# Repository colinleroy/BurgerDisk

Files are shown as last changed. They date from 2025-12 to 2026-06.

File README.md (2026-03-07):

# BurgerDisk - a daisy-chainable Smartport hard drive

**Warning - everything in git, and not a release, is not necessarily fully tested.**

This device provides the Smartport-capable Apple II with an SD-card-based
hard-drive, like the SmartportSD, SPIISD or FloppyEmu projects do.

Contrary to those, the BurgerDisk firmware handles a daisy-chain port
and allows you to have more Smartport devices and/or dumb floppy drives
connected behind it.

Contrary to the SPIISD v2 and FloppyEmu projects, BurgerDisk is free software and
free hardware, and licensed in a way to keep it that way.

Contrary to the SPIISD v2 and FloppyEmu projects, BurgerDisk has no screen UI,
and contrary to the SPIISD v1 project, it has no "boot partition" selection
button. The Apple II will be able to boot from the first partition when booting
from slot 5. This is both a choice - I wanted this device to resemble a
period-correct hard drive - and a limitation - there are no extra digital GPIOs
available on the Nano board.

The code of this firmware is based on:
- Apple //c Smartport Compact Flash adapter, written by Robert Justice <rjustice(at)internode.on.net>
- Ported to Arduino UNO with SD Card adapter, written by Andrea Ottaviani <andrea.ottaviani.69(at)gmail.com>
- FAT filesystem support, written by Katherine Stark
- Daisy chaining is based on SmartportVHD's reverse engineering, written by Cedric Peltier

## Building the BurgerDisk
Full instructions for building your own BurgerDisk are available in the
[BurgerDisk build instruction page](build_instructions/README.md).

## Using the BurgerDisk
### Plugging in
Plug the BurgerDisk to your Apple II, or to the previous Smartport device in the
chain. Plug the next device to the daisy port of the BurgerDisk.

When daisy-chaining, the usual Apple II rules apply:
- first the dumb 3.5" floppy disk drives (like the Apple 3.5 drive)
- followed by Smartport devices (like BurgerDisk, Unidisk 3.5", Fujinet, SPIISD, etc)
- followed by dumb disk drives (like the Disk //c)

So far, BurgerDisk has been tested in the following configurations:
- Alone on the //c and IIgs external floppy connector
- computer => BurgerDisk => Disk //c
- computer => Unidisk 3.5 => BurgerDisk
- computer => Unidisk 3.5 => BurgerDisk => Disk //c
- computer => BurgerDisk => Unidisk 3.5 => Disk //c

It has been tested with the following computers:
- Apple //c A2S4000, ROM3
- Apple //c A2S4100, ROM4x
- Apple IIgs, ROM 01

[More tests results are available](https://www.colino.net/wordpress/archives/2026/02/08/burgerdisk-tests/).

### Configuring disk images
The firmware will open and present between one and four partitions.
If a config.txt file exists on the SD card, it will use the first four
lines as filenames for the partitions to open. An optional fifth line
containing "debug=1" will turn debug messages on.

For example, this will present `prodos.po` and `total_replay.po`, and turn
debug on:
```
prodos.po
total_replay.po

debug=1
```

If no config.txt file exists, the firmware will search for PARTx.po
files, with x between 1 and 4.

## Compatibility notes
The firmware is compatible with SPIISD v1 and SPIISD v2 boards. It fixes
two bugs in their firmwares:
- Too slow init preventing the partitions to be visible by ProDOS after booting
  from internal floppy,
- A non-recoverable freeze on A2S4100 Apple //c with the memory expansion board.

But,
- Of course, running this firmware on an SPIISD board will not allow for daisy chaining.
- For daisy-chaining, the BurgerDisk firmware makes use of pins that the SPIISD
  boards use for button(s) and/or LCD. If you want to replace the SPIISD firmware
  with BurgerDisk's, it is safer to unsolder the buttons and remove the LCD. The
  BurgerDisk firmware does not handle any buttons or LCD anyway.

## Licensing
This firmware is licensed under the GPL v3.

The PCBs and enclosure are licensed under CC BY-SA 4.0.

This means that anyone is welcome to **use, modify, distribute and sell hardware**
based on BurgerDisk. Using and modifying does not require you to do anything.
**Distributing and/or selling requires you to provide the source files for the
firmware and the PCBs, under the same licenses**. It can just be a link to this
repository if no modification is made. If modifications are made, think free
software, and consider submitting pull requests, it could help avoiding
fragmentation.

## Thanks and acknowledgments

Many thanks to Robert Justice, Katherine Stark and Andrea Ottaviani for the
initial work on a simple SD-based Smartport device.

Many thanks to Cedric Peltier for his work on SmartportVHD, which does support
daisy-chaining, but is sadly abandoned, and based on a weird-ass development
board. It was very well documented and helped me a lot implementing daisy-chaining.

Many thanks to Ralph Irving, who spent many hours beta-testing and pinpointing
bugs I could not have fixed without his help (for lack of hardware).

Thanks also to Steve Chamberlin of [BMOW](https://www.bigmessowires.com/), for
documenting a lot of their Smartport/FloppyEmu work on their blog.

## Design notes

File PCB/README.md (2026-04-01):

In this directory are the Kicad sources for the different PCBs.
Variations exist:
- *-Angled: For a right-angle, PCB-type DB19F connector (otherwise, panel-mount (solder cups) connector required)
- *-THT: Through-hold PCB. Will require an Arduino and SD module
- *-SMD: SMD PCB with the Atmega328p integrated, and the microSD where applicable

PCBs families:
- BurgerDisk: The simpler PCB, with more enclosures options (Full or micro SD)
- Mini: Everything integrated, for the Mini enclosure
- Domino: Everything integrated, as small as possible.
- (micro)SD-module: the card readers for the BurgerDisk

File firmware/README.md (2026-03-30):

# Programming the Arduino Nano with BurgerDisk's firmware

In order for the Arduino Nano to boot fast enough to answer an Apple //c booting
from its internal floppy, the Nano **has** to be programmed using an AVR ISP
programmer. I use an [STK500 AVR ISP programmer](https://aliexpress.com/item/1005006205386137.html).

Open a terminal, and change to this `firmware/` directory.

## Arduino IDE installation
Install the Arduino IDE, for example on a Debian-based Linux distribution:
```
sudo apt install arduino
```

Start it:
```
arduino .
```

## Arduino IDE configuration
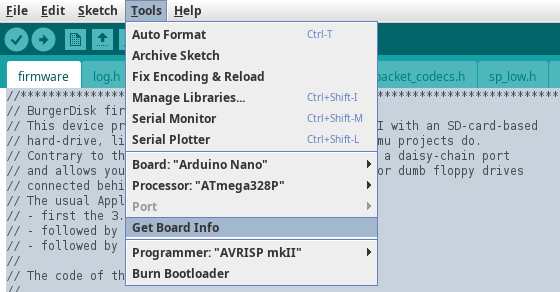
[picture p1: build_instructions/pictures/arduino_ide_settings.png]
The Arduino IDE Tools menu
.

In `Tools` menu, `Programmer` submenu, select your programmer.

You can then either continue using the Arduino IDE interactively:
- In `Tools` menu, `Board` submenu, select `Arduino Nano`.
- In `Tools` menu, `Processor` submenu, select `Atmega328p`.
- In `Sketch` menu, `Include Library` submenu, select `Manage Libraries...`.
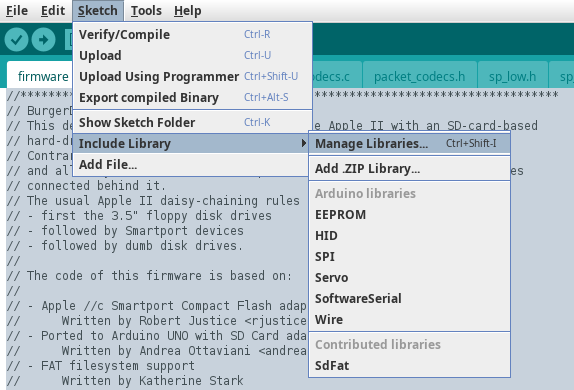
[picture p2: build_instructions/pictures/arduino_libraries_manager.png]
Manage Libraries menu item
  .
- Search for `SdFat` by Bill Greiman, scroll to it, and install version 2.3.0 (Screenshot shows 2.1.2, but choose 2.3.0).
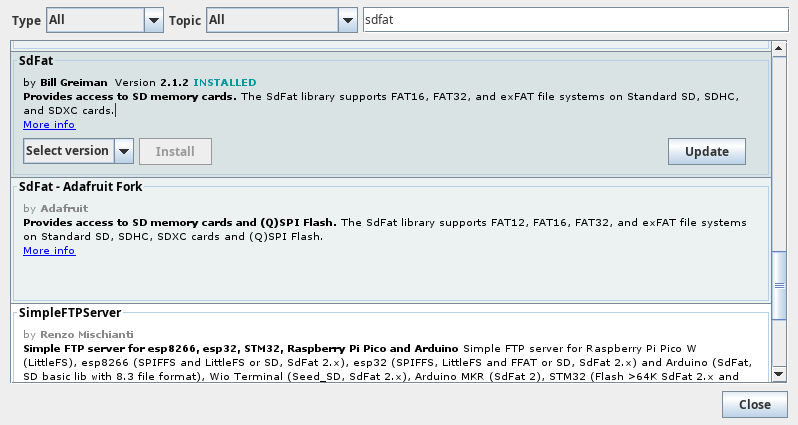
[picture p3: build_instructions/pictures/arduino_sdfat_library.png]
SdFat installation
  

Or, you can quit the Arduino IDE, and in your terminal, run:
```
make setup
```

## Flashing the firmware
**Make sure that the Nano is out of the BurgerDisk PCB, or that the BurgerDisk
is disconnected from the Apple II, even if the Apple II is turned off, before connecting the programmer. NEVER connect the programmer when the BurgerDisk is
connected to the Apple II.**

Connect your Arduino Nano to the programmer's 6-pin connector. The red
wire of the connector must be towards the Nano's `VIN` pin.
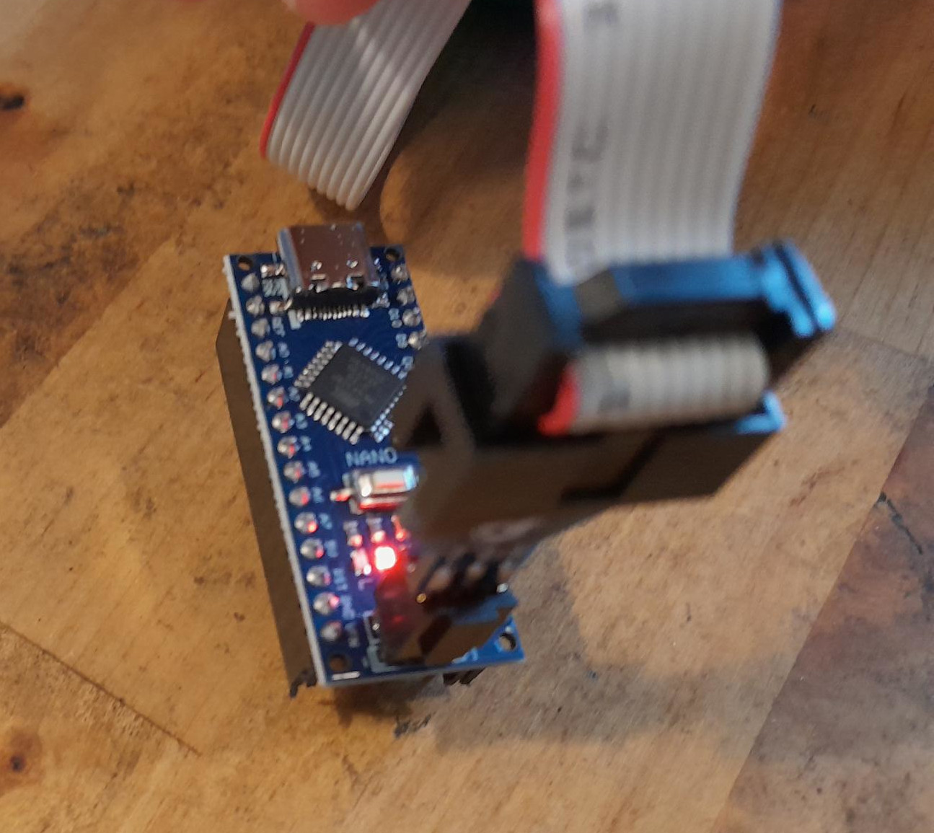
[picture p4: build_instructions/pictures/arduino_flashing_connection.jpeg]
The Arduino Nano, connected to the programmer


Two options here too:
- From the Arduino IDE, `Sketch` menu, choose `Upload using programmer`. Wait
  until the "Done uploading" message.
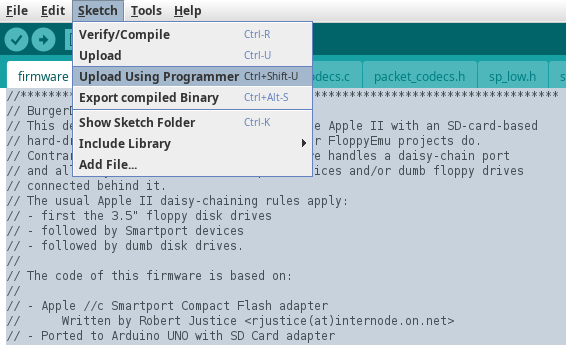
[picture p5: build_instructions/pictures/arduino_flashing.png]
Upload using programmer menu item
  
- From the command line, run `make fuse && make upload`. Wait for the upload to be done.

Disconnect the programmer, and you're set.

## Debugging
If you need to debug the firmware, you can connect its UART pins to an [UART/USB
converter](https://aliexpress.com/item/1005008293602159.html). Wire the
BurgerDisk's UART `GND` pin to the USB converter `GND` pin, and the BurgerDisk's
UART `TX` pin to the USB converter's `RX` pin.

Plug the USB converter in your computer, check its device file (using `dmesg`
for example), then run:
```
minicom -D /dev/ttyUSB0 -8 -b230400
```

Connect the BurgerDisk to the Apple II, and boot the Apple II. Log messages
should be visible in Minicom. Remember: **never have the programmer connected
while the PCB is connected to an Apple II!**

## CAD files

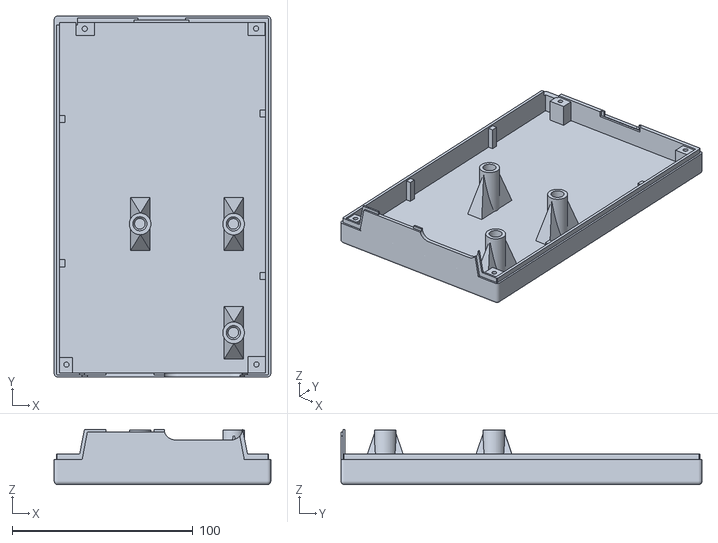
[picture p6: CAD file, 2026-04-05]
enclosure/Full-Size/BurgerDisk SMD Top (full size SD).stl
120.0 x 200.0 x 30.7

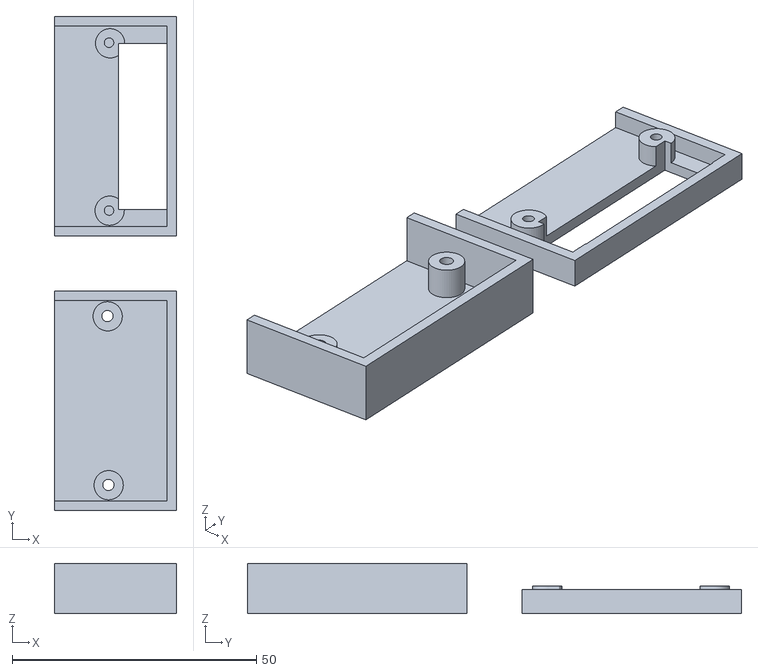
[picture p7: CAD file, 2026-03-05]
enclosure/Adapter/DB19-to-IDC20 adapter.stl
25.0 x 101.2 x 10.2

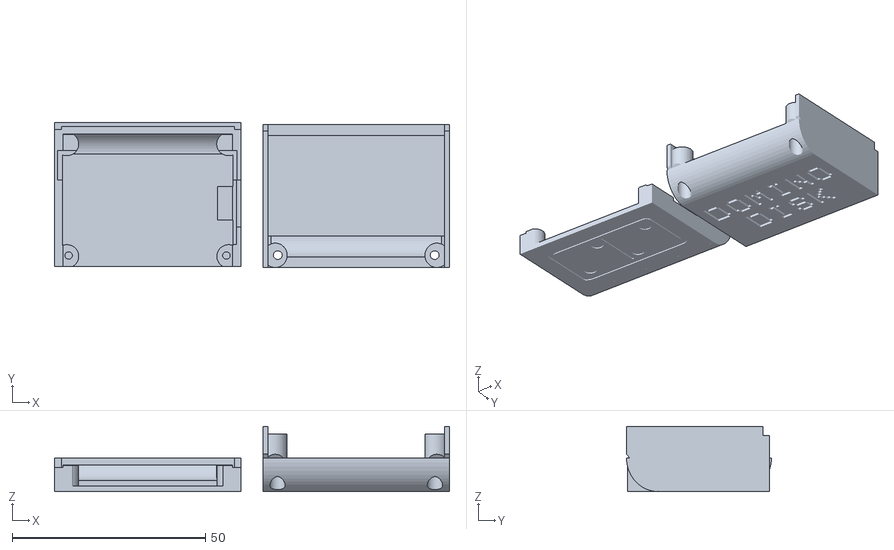
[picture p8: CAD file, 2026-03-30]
enclosure/Domino/DominoDisk SMD Angled.stl
102.1 x 37.5 x 16.9

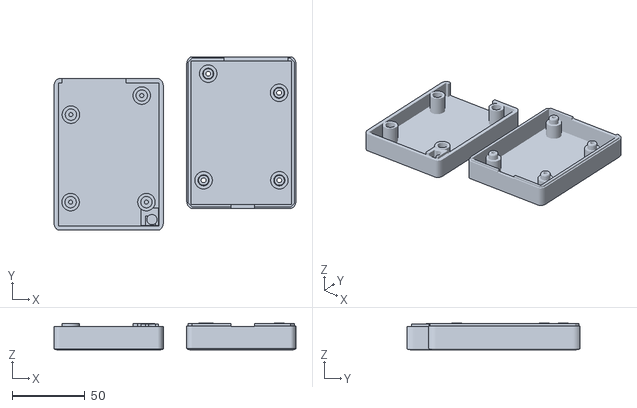
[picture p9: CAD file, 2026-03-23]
enclosure/Mini/Mini-BurgerDisk.stl
166.0 x 119.0 x 18.5

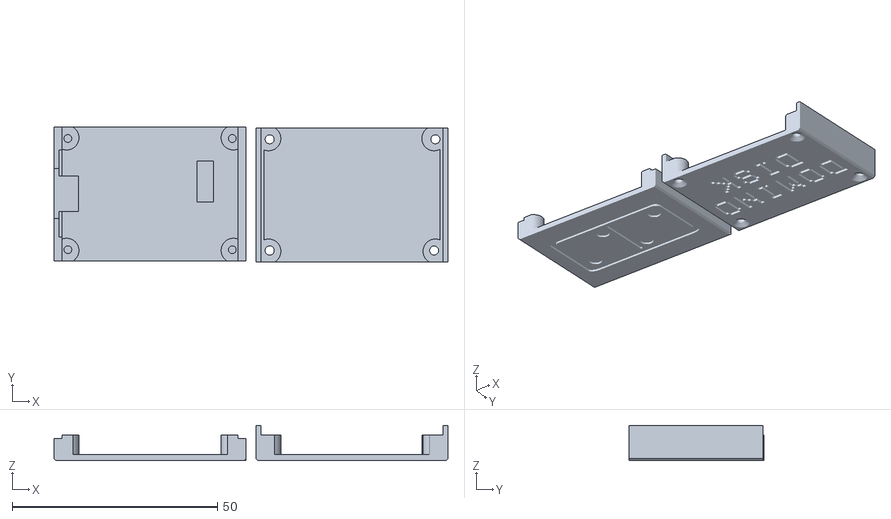
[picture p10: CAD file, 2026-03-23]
enclosure/Domino/DominoDisk SMD.stl
96.0 x 32.9 x 8.60

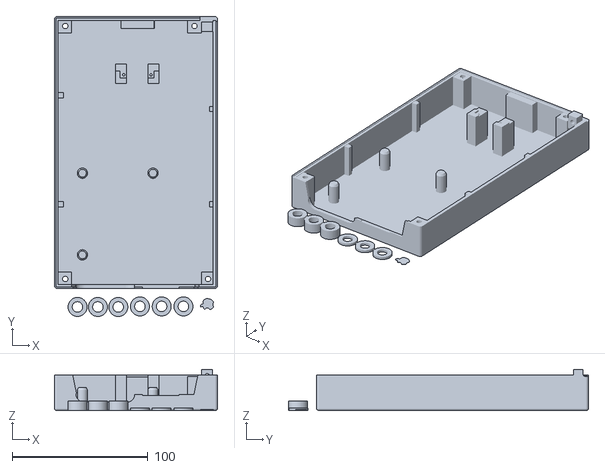
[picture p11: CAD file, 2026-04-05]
enclosure/Full-Size/BurgerDisk SMD bottom.stl
120.0 x 220.6 x 30.2

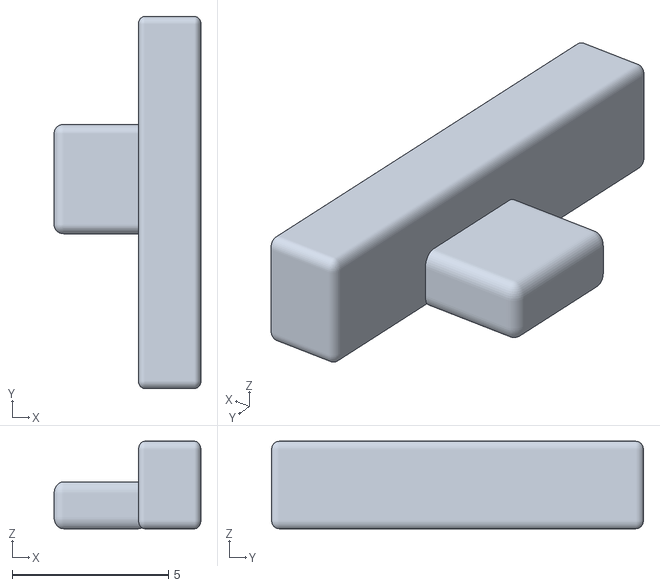
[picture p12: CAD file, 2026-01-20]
enclosure/Full-Size/BurgerDisk LED diffuser.stl
4.70 x 11.9 x 2.80

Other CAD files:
enclosure/Full-Size/BurgerDisk SMD top (micro-SD).stl

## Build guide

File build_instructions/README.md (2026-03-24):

# Building the BurgerDisk

## BOM (bill of materials)
Mind that the links provided here might be dead by the time you read this, and
that most of them have options (number of pins, resistor values, etc) that you
should double-check before buying.

**For the main board**, you will need:
- one female DB19 connector, [solder type](https://www.ebay.com/itm/165875193091) or
  [angled](https://www.ebay.com/itm/284338436979), for daisy-chaining
- the main PCB's [Gerber files](../../../releases/latest/). You can get them easily
  from PCBWay: [for solder type DB19](https://www.pcbway.com/project/shareproject/BurgerDisk_Apple_II_Smartport_hard_drive_235e6080.html), 
  or [for angled DB19](https://www.pcbway.com/project/shareproject/BurgerDisk_Apple_II_Smartport_hard_drive_Angled_THT_DB19_d37bdb0f.html)
- one [Arduino Nano with an Atmega328p processor](https://aliexpress.com/item/1005006773519913.html)
- one [STK500 AVR ISP programmer](https://aliexpress.com/item/1005006205386137.html) for uploading the firmware to the Arduino
- one [IDC20 connector, male, 2.54mm pitch](https://aliexpress.com/item/1005001400147026.html)
- one [470Ω resistor, 1/2W](https://aliexpress.com/item/1005004472952572.html)
- one [150Ω resistor, 1/4W](https://aliexpress.com/item/32952657927.html)
- one [330Ω resistor, 1/4W](https://aliexpress.com/item/32952657927.html)
- one [1kΩ resistor, 1/4W](https://aliexpress.com/item/32952657927.html)
- one [10kΩ resistor, 1/4W](https://aliexpress.com/item/32952657927.html)
- one [3mm LED, 3V, 20mA](https://fr.aliexpress.com/item/1005003320296052.html)
- one [PC817 optocoupler (DIP-4)](https://aliexpress.com/item/1005004609787594.html)
- one [1N5818 diode](https://aliexpress.com/item/4000055728807.html)
- one [1N4448 diode](https://aliexpress.com/item/1005008591345474.html)
- two [2-pin male headers, 2.54mm pitch](https://aliexpress.com/item/1005006181780843.html)
- one [microSD module ("TF")](https://aliexpress.com/item/1005008633757049.html) or for a better manipulation of the card,
  [my version](../../../releases/latest/)
- one [6-pin male header, 2.54mm pitch](https://aliexpress.com/item/1005006181780843.html) for the MicroSD module
- one [6-pin cable, 2.54mm pitch, 10cm long](https://aliexpress.com/item/4001119232749.html) for the MicroSD module
- one [2-pin cable, 2.54mm pitch, 20cm long](https://aliexpress.com/item/4001119232749.html) for the LED
- two [15-pin female header](https://aliexpress.com/item/1005006934014275.html) for easy Arduino removal

**For connecting to the computer**, you will need:
- The BurgerDisk connection cable, composed of:
  - the [DB19 to IDC20 PCB](https://www.pcbway.com/project/shareproject/BurgerDisk_DB19_to_IDC20_adapter_d6ce25bb.html)
    or its [Gerber files](../../../releases/latest)
  - an [IDC20 cable, 2.54mm pitch](https://aliexpress.com/item/1005003853804182.html), at least 50cm
  - a second [IDC20 connector, male, 2.54mm pitch](https://aliexpress.com/item/1005001400147026.html)
  - one [male DB19 connector](https://www.ebay.com/itm/257181325655)
  - two [M2 x 12 or 14mm screws](https://aliexpress.com/item/1005006960903249.html)
- Alternatively, the [Fujinet's DB19/IDC20 adapter](https://github.com/FujiNetWIFI/fujinet-hardware/tree/master/AppleII/DB-19M-Adapter-Male-Rev1)
can be used, provided that you solder [the -12V and +12V pads between the IDC20
and the DB19, and the DRV2 pad on the side](../build_instructions/pictures/fujinet-db19-adapter.png)

**For the enclosure**, you will need:
- the [enclosure's STL files](../enclosure/)
- four [M3 x 20mm wood screws](https://aliexpress.com/item/33043885403.html)
- two [M2 x 6 to 10mm screws](https://aliexpress.com/item/33043885403.html)
- optionally, a [500 grams weight](https://aliexpress.com/item/1005007419997918.html)
  (and glue) to make the enclosure heavier and avoid thick-cables-induced levitation.
  (I found diving belt weights to have the best price-to-weight ratio but you can
  use whatever you want or have available).

## Printing the enclosure
You can use the .stl files provided in [this repository](../enclosure/).
So far I print the enclosure at 15% infill, 0.20mm layer height. With my printer
I don't need support for the overhangs on the slots at the back, but your mileage
may vary.

## Video format

These instructions are also [available in video format](https://www.youtube.com/watch?v=1XYskDaTvEE).

## Building the main PCB
**All elements are to be soldered on the top-side of the PCB**, the side with the
markings.

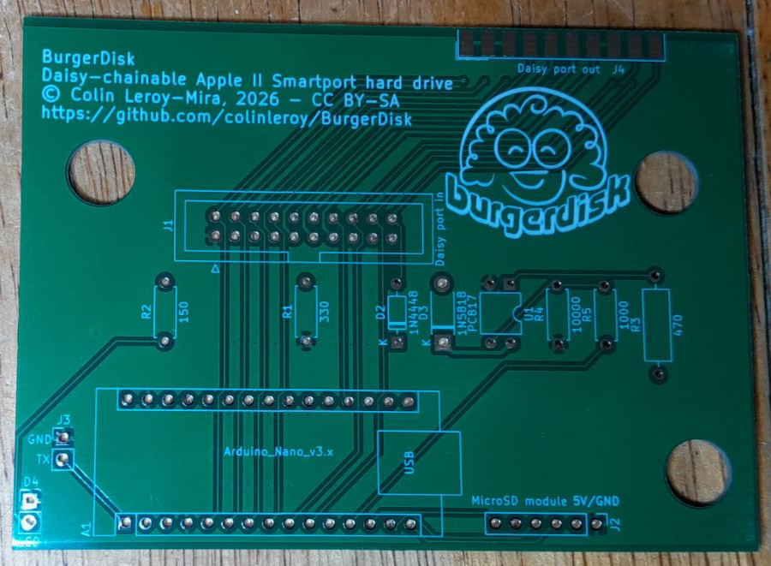
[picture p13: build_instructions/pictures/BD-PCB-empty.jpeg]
The empty PCB


### Small components: Resistors, diodes and optocoupler
Insert the 150Ω resistor in its spot, (R2/150).

Insert the 330Ω resistor in its spot (R1/330).

Insert the 470Ω resistor in its spot (R3/470).

Insert the 10kΩ resistor in its spot (R4/10000).

Insert the 1kΩ resistor in its spot (R5/1000).

Resistors are not polarized, so you can put them either way.

Insert the 1N4448 diode in its spot (D2 / 1N4448).

Mind that diodes **are** polarized, so make sure the line on the PCB silkscreen
and the line on the diode are facing the same way.

Insert the 1N5818 diode in its spot, (D3/1N5818).

Insert the PC817 optocoupler in its spot (U1/PC817). The small round
mark on the PC817 is the anode, and goes to the hole with a square solder mask.

Make these components stay in place, either by bending their legs or taping them.

Solder them.

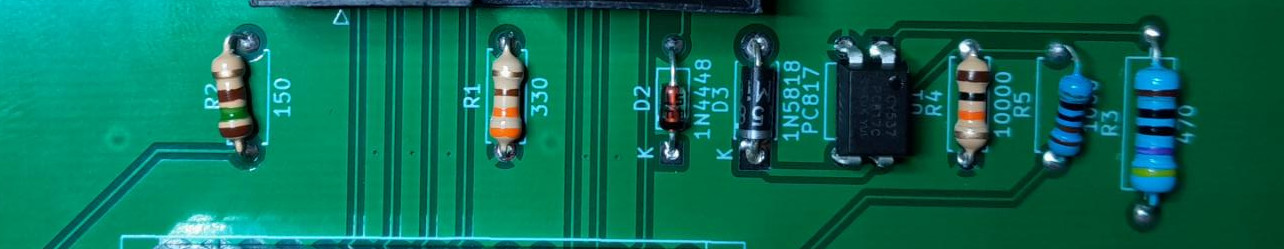
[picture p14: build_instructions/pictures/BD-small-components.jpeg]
Small components soldered


### MicroSD card module connector
Solder the 6-pin male header on the "MicroSD module" spot.

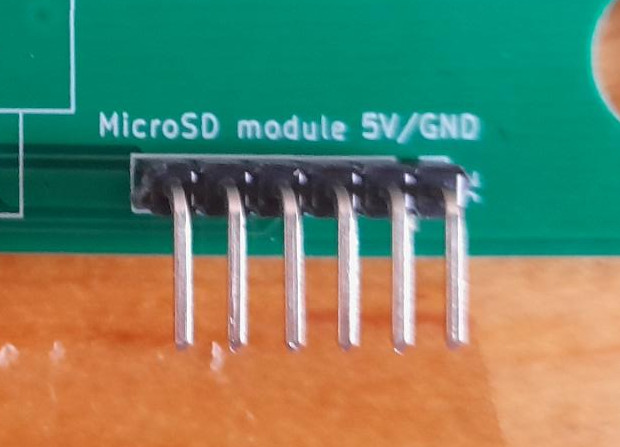
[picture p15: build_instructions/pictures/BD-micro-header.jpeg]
The MicroSD header


### 2-pin headers
Insert the 2-pin male headers in the "J3" and "LED" spots. Solder them.

### Input IDC-20 connector
Insert the IDC-20 connector in its spot. Mind the notch position, it must be
towards the bottom of the PCB. Solder it.

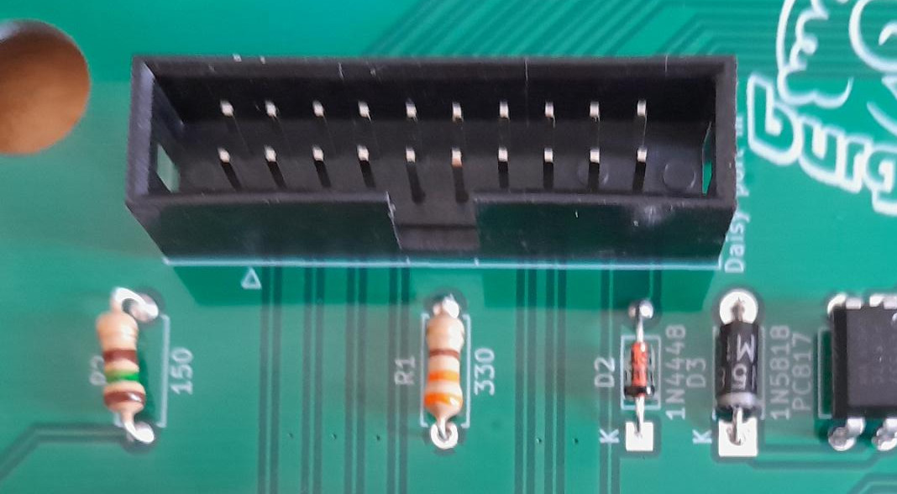
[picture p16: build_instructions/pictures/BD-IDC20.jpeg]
The IDC20 connector


### Arduino Nano
Solder the Nano's 6-pin header for programming on top of the Nano if necessary.
The top of the Nano is the side with the USB connector and the reset button.

This is not strictly necessary, but I like to put the Nano on a "socket" so that
it is easy to replace if necessary.

Assemble the Nano's two 15-pin connector with the 15-pin female connectors.
Insert these on the PCB, in the "NANO" spot, with the female headers towards
the PCB. Make sure the USB port is facing right, over the "USB conn" marking
on the PCB. Solder the 30 pins to the Nano.

Reverse the PCB, and solder the female headers' 30 pins to the PCB.

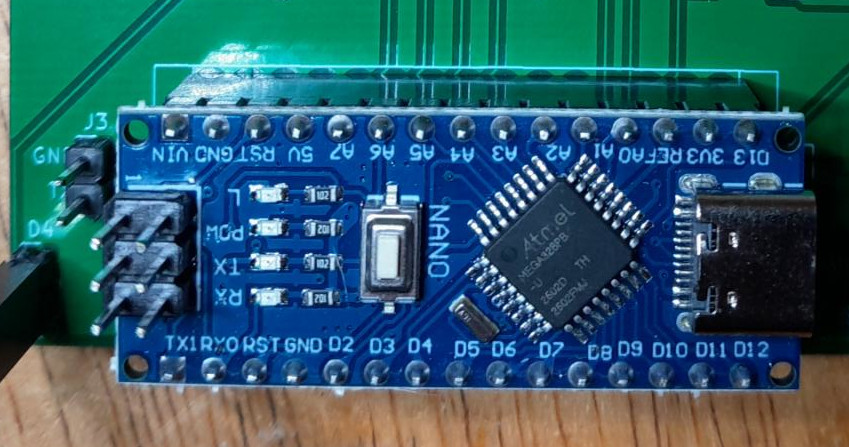
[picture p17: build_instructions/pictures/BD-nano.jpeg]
The Nano on its headers


You can [program the Arduino at this point](../firmware/README.md). People having
bought a kit from me don't need to program the Arduino, I did it before shipping.

Add a strip of black tape on the Nano's red LEDs, otherwise it will glow red
through white enclosures.

### Daisy DB19
Align the female DB19 connector with the Daisy out pads on the PCB. Pay close
attention to the alignment, as the DB19 will basically be un-desolderable with
basic equipment. Solder it on both sides.

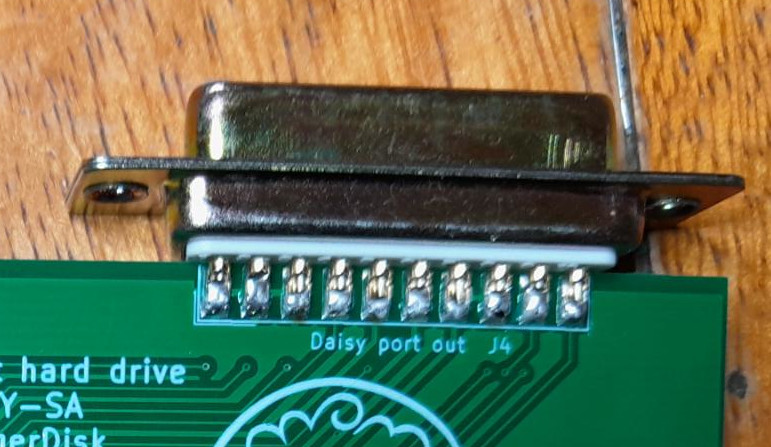
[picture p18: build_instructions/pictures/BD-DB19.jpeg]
DB-19 soldered


Your PCB now looks like this:
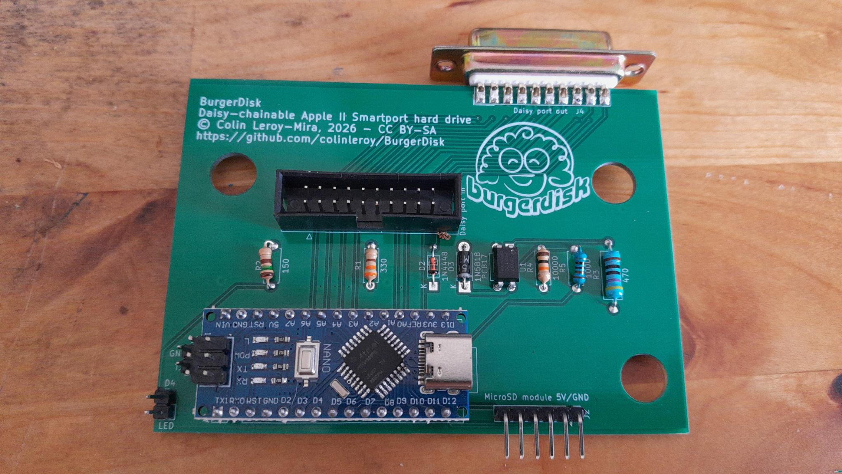
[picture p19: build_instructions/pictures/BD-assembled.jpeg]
The assembled PCB


### LED
Solder the LED to about 15 cm of Dupont wire connectors. The easiest way is to use
male/female connectors, shorten the LED's legs, and solder the LED to the male
connectors, minding the polarity (long leg = anode, red wire).

Put 3mm heatshrink on the LED to avoid having it illuminate the whole enclosure.

The anode (red wire) goes to the edge of the PCB.

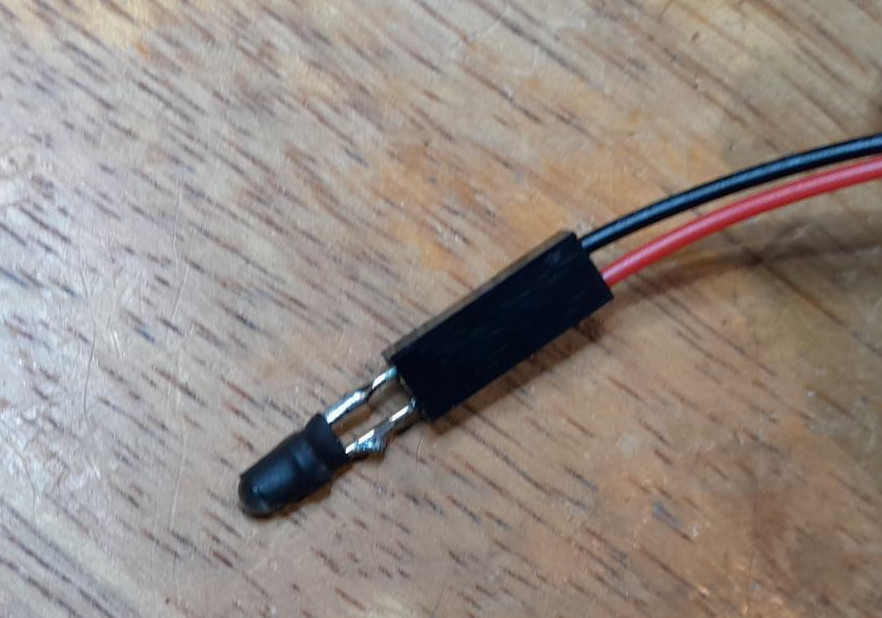
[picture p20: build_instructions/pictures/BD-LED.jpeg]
The LED


## The main connection cable
Because of its daisy-chaining capabilities, the cable to plug BurgerDisk to the
Apple II is more complicated than most DB19-to-IDC20 adapters.

The correct DB19-to-IDC20 adapter for this project is provided in this
repository.

### Assembling the adapter-based cable
Align the male DB19 connector with the pads on the adapter PCB. Pay attention
to the alignment, as the DB19 connector will basically be un-desolderable.
Solder it.

Insert the IDC-20 connector in the adapter PCB. It must on the top-side of the
PCB, where the IDC-20 is outlined on the silkscreen. Pay attention to the notch
position, which should be towards the DB19 connector. Solder it.

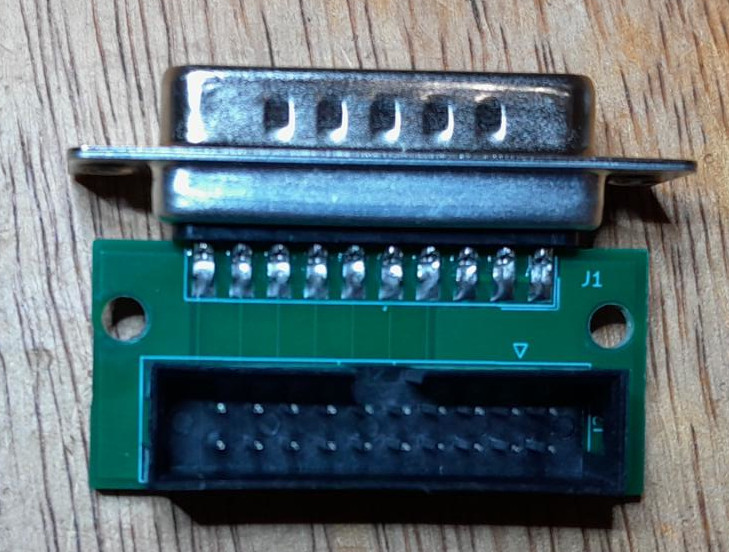
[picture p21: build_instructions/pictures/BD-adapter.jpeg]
The adapter, soldered


Insert the assembled adapter into its enclosure, and screw it shut with two M2
x 12 (or 14) mm screws.

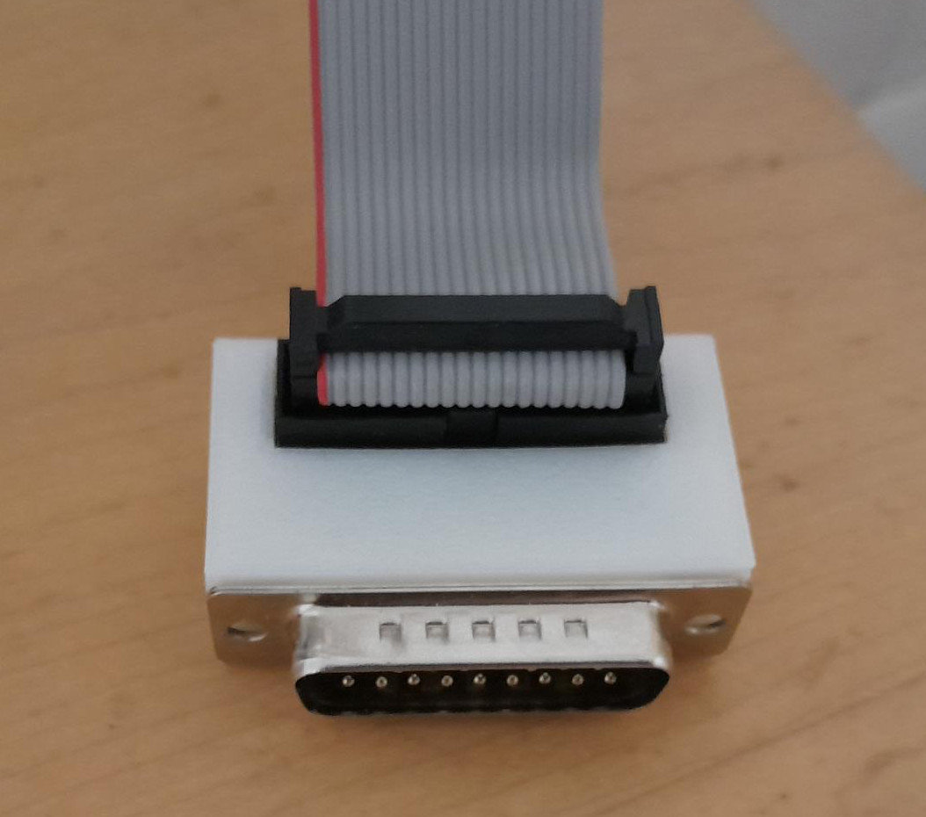
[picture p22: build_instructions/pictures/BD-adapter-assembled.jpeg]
The adapter, assembled


## Assembling in the enclosure
Put washers on the enclosure mounting posts: 2mm if you are using the angled
DB19 female connector, or 9mm (2 + 7) if you're using the "solder type" DB19
connector.

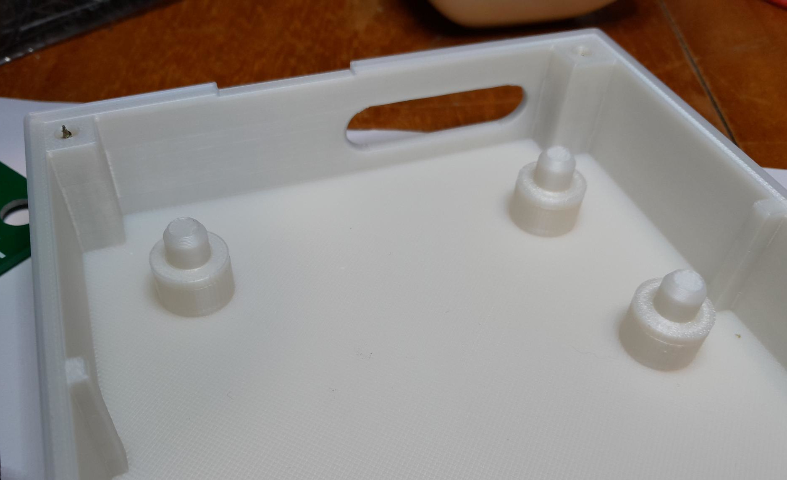
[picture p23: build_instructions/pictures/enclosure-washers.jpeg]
The washers


Put the PCB in the enclosure's bottom, making sure the enclosure notches
are in the PCB mounting holes.

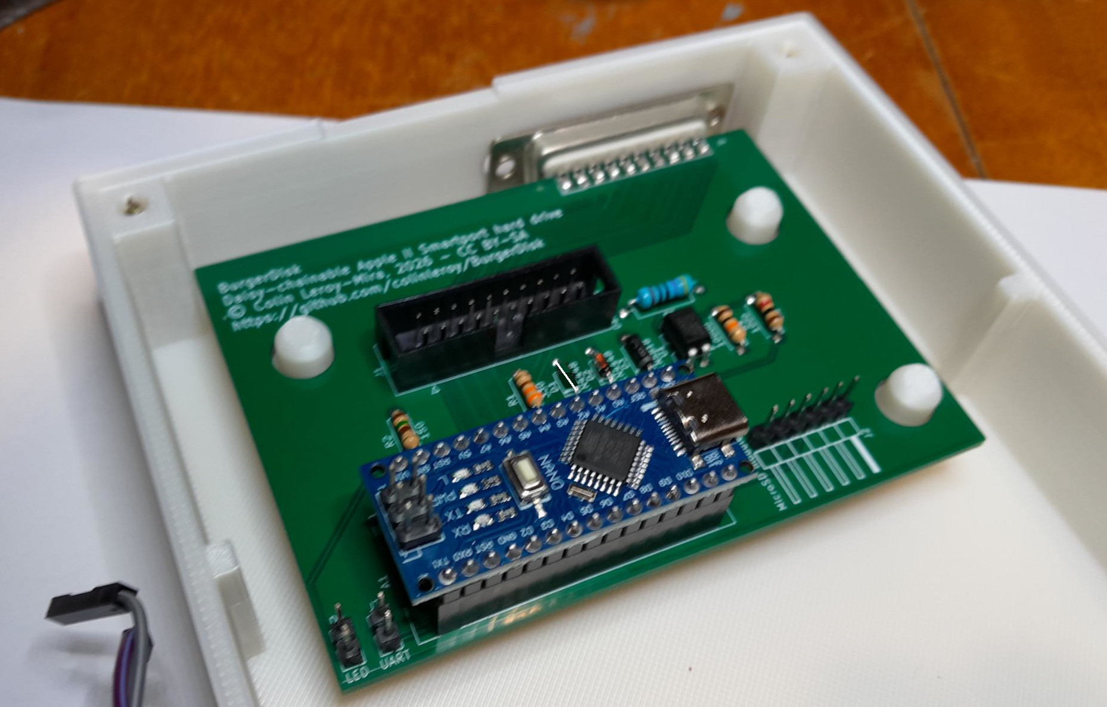
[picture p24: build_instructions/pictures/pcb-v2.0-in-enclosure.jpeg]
The BurgerDisk assembly


If using the angled DB19, put the 7mm washers on top of the PCB.

Screw the MicroSD module with M2 x 6 to 10mm screws, face up, at the front of the
enclosure's bottom; then connect it to the PCB using the 6 or 8-pin cable.
**Mind which way you connect!**
When looking from the front of the enclosure, +5V and GND are on the **right**
both on the PCB, and on the MicroSD module.

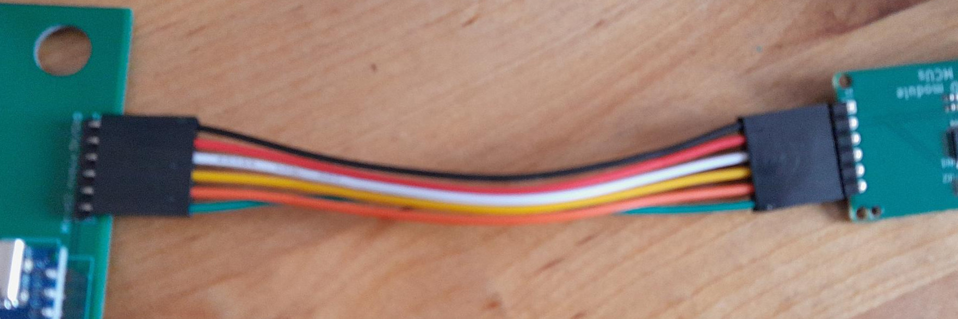
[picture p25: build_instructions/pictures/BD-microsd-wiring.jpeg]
The microSD wiring


Plug the main input cable in, and route it out of the enclosure via its dedicated
slot in the back.

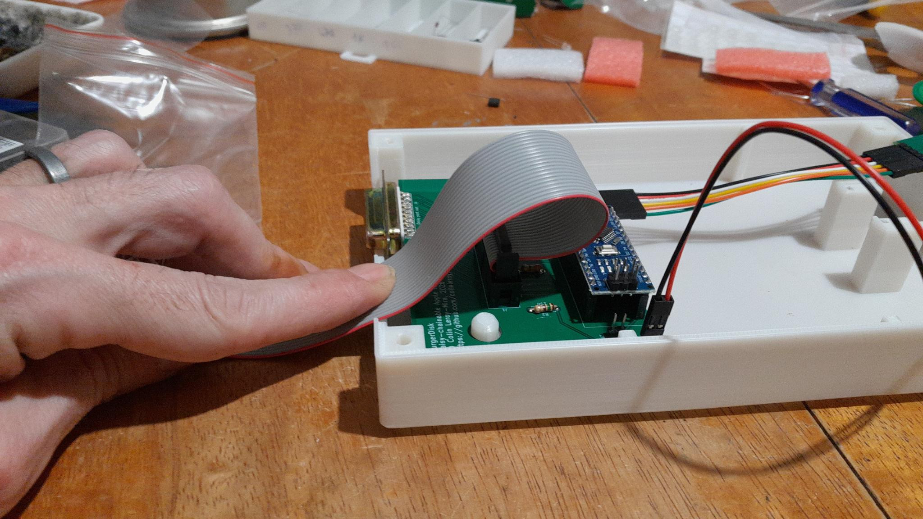
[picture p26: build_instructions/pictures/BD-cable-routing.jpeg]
The cable routing


Glue a weight in the front of the bottom part if needed (epoxy works well on PLA
and lead). Make sure you leave room for the enclosure top's posts.
Put the enclosure's top on the bottom, making sure the notches are
aligned so that the PCB does not move around. Turn the enclosure on its back,
and screw it closed with four M3 x 20mm screws. There may be some stringing from
the 3D printing in the bottom part of the holes, remove it with a small
screwdriver beforehand if needed.

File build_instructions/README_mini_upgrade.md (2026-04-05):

# Fitting the Mini's PCB into a full-size BurgerDisk enclosure
If you have a Mini BurgerDisk and would like to house it in the
full-size BurgerDisk enclosure (for style, or to get a full-size
SD card, etc), this is possible with a bit of tinkering.

The Mini's PCB comes with two cuttable traces - one for the onboard LED's power,
and one for the onboard's MicroSD reader. It also comes with headers to connect
an external LED and card reader instead.

This is what you start with (LED header already soldered in here, forgive the
oversight):
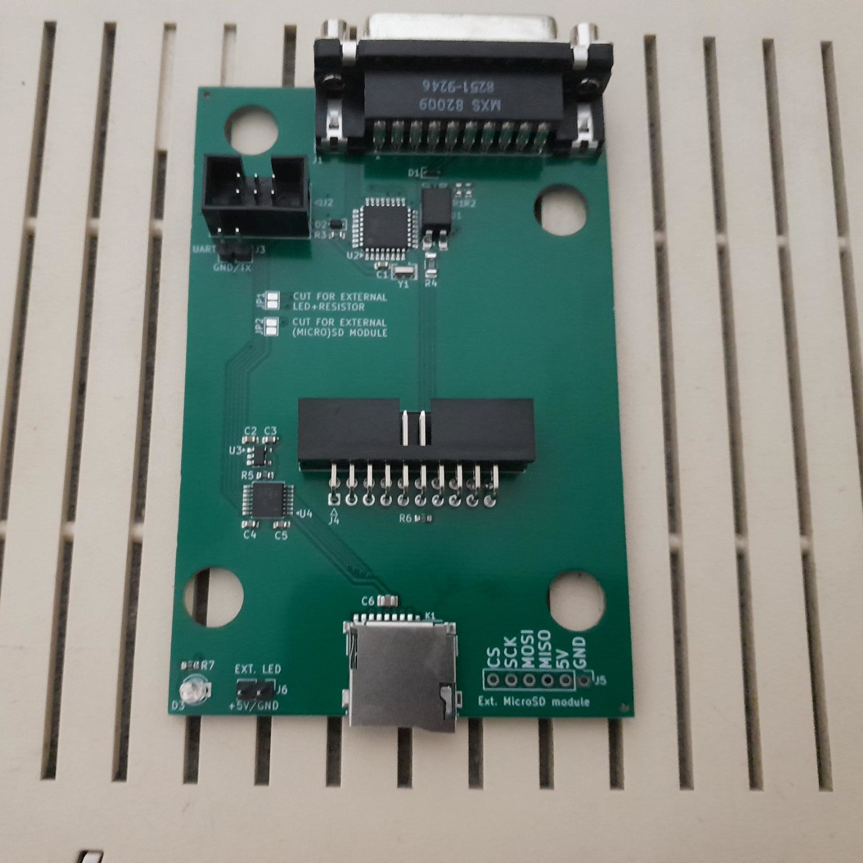
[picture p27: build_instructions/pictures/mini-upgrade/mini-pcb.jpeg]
The Mini PCB


## BOM (bill of materials)
The upgrade requires:
- A full-size enclosure (SMD version)
- A microSD or SD card module
- A ⌀3mm LED
- A resistor (the LED is 5V powered, check the required values. 150Ω is good
  for a blue LED)
- A 2-pin Dupond male header
- A 6-pin Dupond male header
- A 2-pin Dupond cable with female headers on one end
- A 6-pin Dupond cable with female headers on both ends
- A short length of ⌀3mm heatshrink

This is what you need:
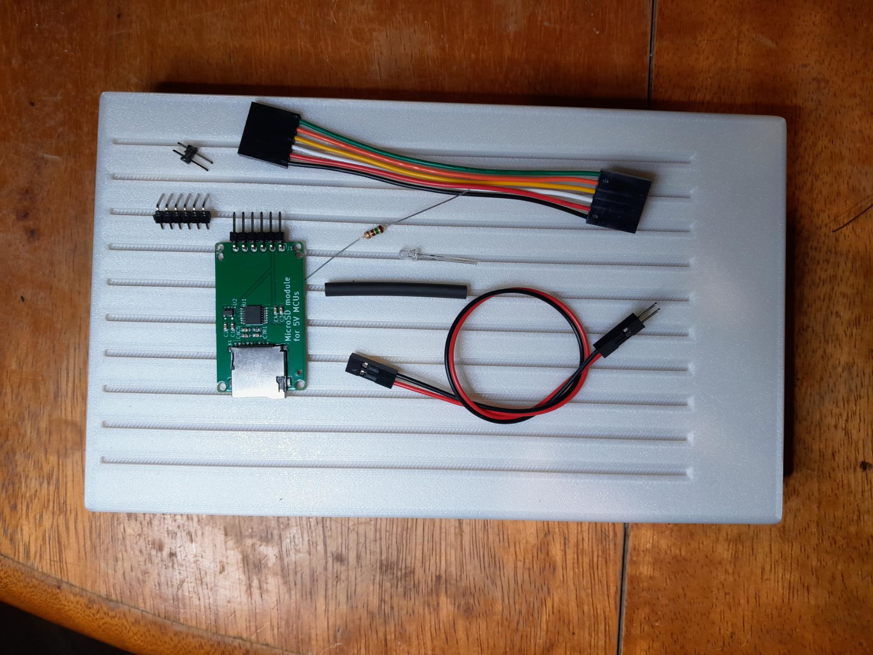
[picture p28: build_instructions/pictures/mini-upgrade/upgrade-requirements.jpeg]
The upgrade kit


## Solder the headers on the LED and MicroSD headers on the PCB
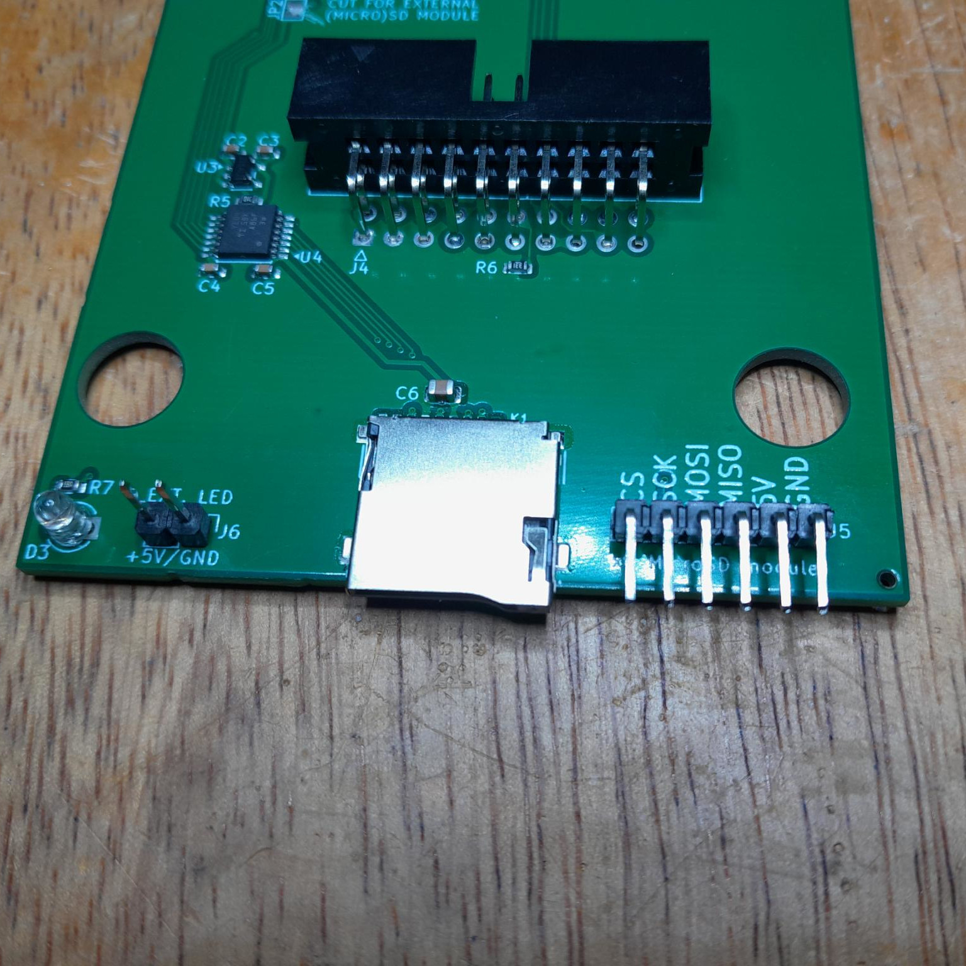
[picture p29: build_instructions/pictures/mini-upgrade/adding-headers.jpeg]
Headers soldered


## Cut the traces powering the internal components
The traces are under the ISP header, clearly identified:
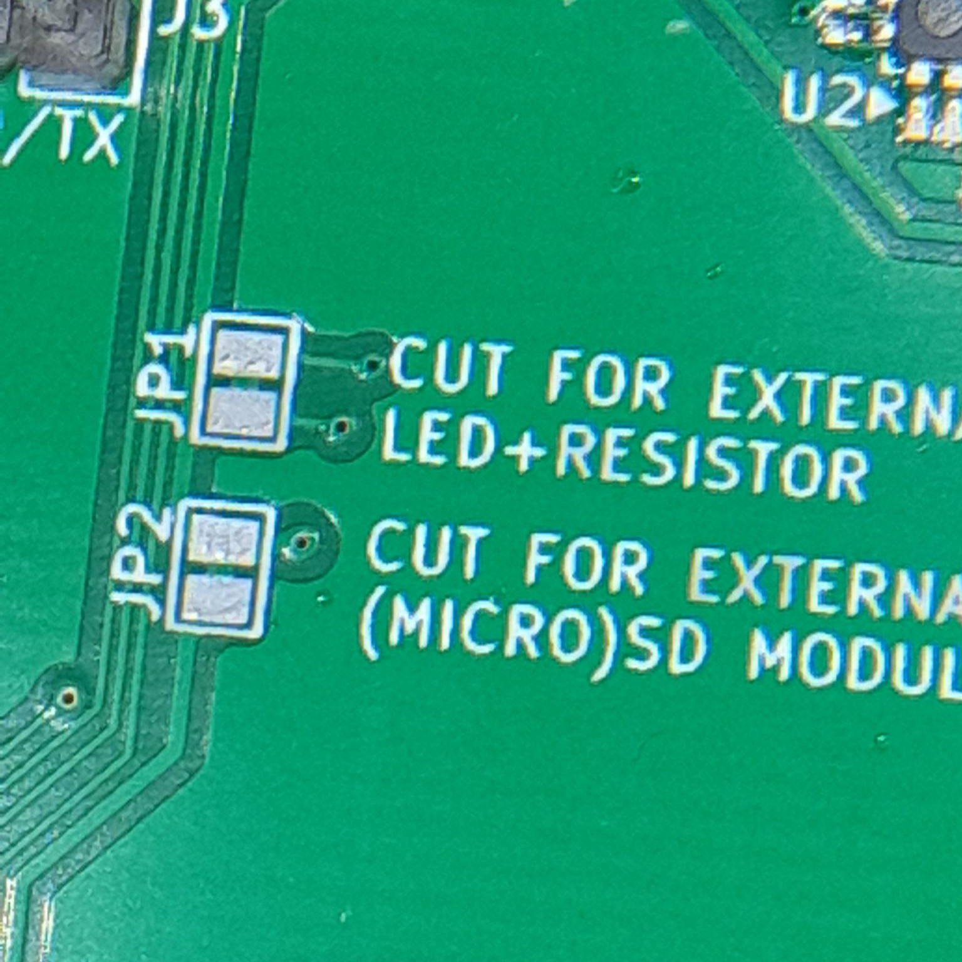
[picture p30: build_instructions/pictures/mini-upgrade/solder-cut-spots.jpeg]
The traces to cut


Cut them with a sharp knife.
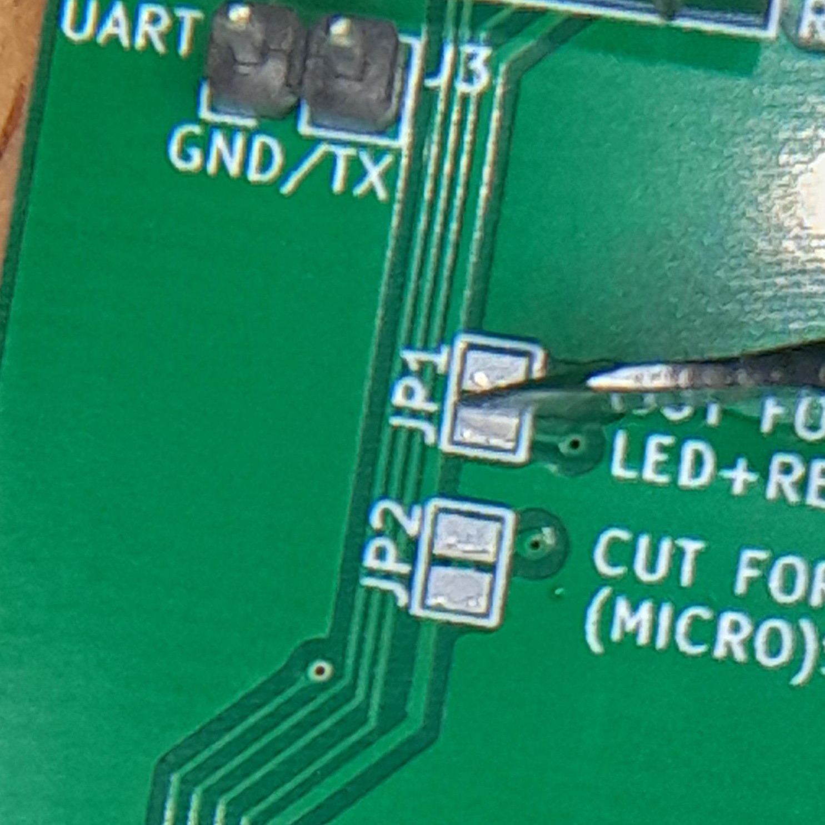
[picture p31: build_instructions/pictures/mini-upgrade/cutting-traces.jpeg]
Cutting the traces


Once done, verify that there is no continuity between the surrounding pads.
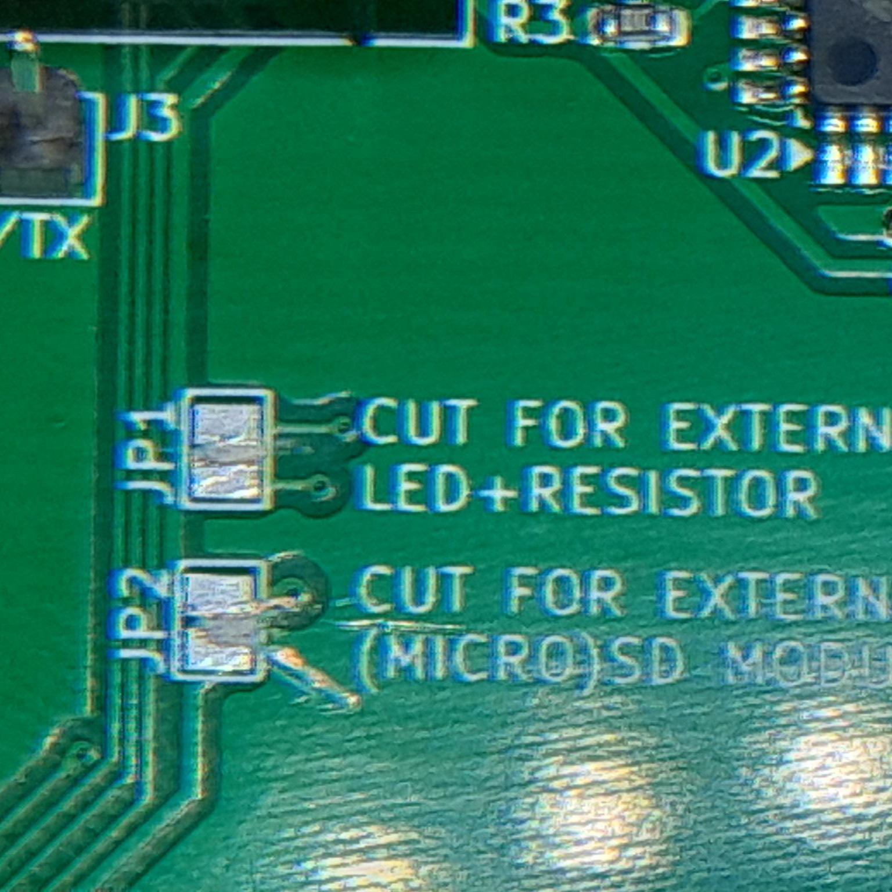
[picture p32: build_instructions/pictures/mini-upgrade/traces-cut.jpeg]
The traces, cut


If you want to go back to a Mini enclosure at a later point, reconnecting these
will be possible with two solder points.

## Assemble the LED and resistor on their cable
Cut the LED's long leg shorter.
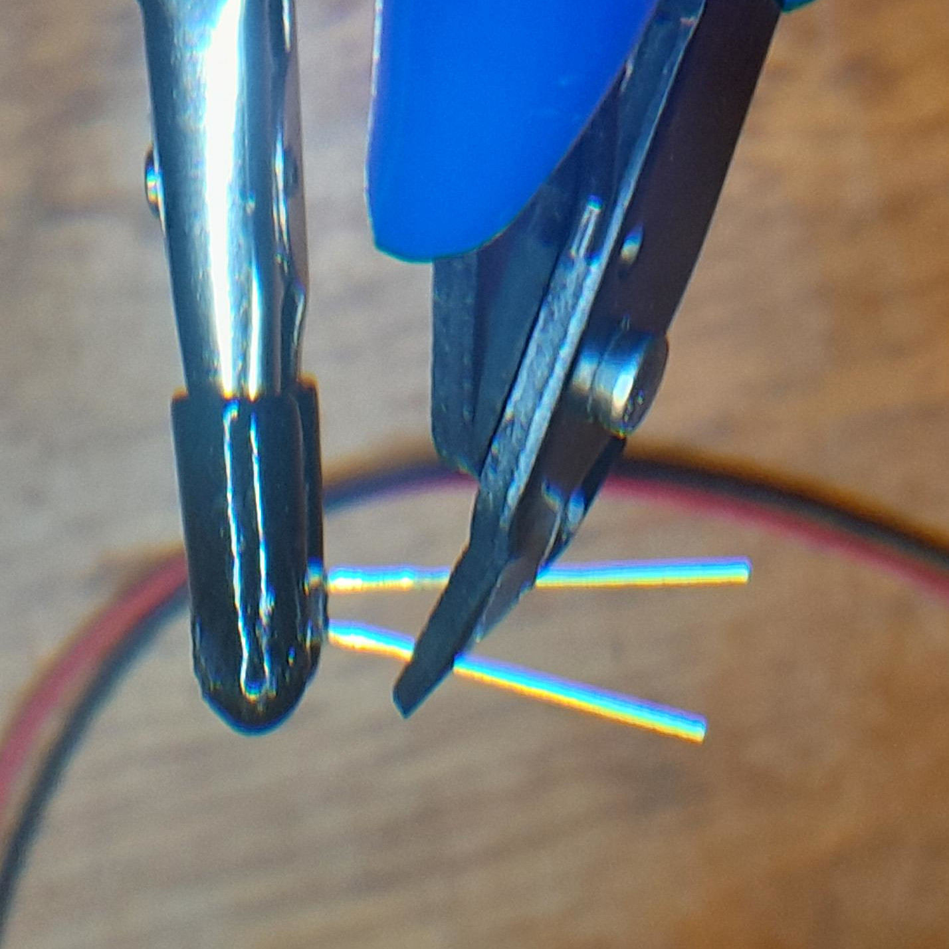
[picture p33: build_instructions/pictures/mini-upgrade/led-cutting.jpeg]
Cutting the LED's anode


Cut the resistor's legs shorter, and tin them with solder. Do the same with
the LED's legs and the wires.
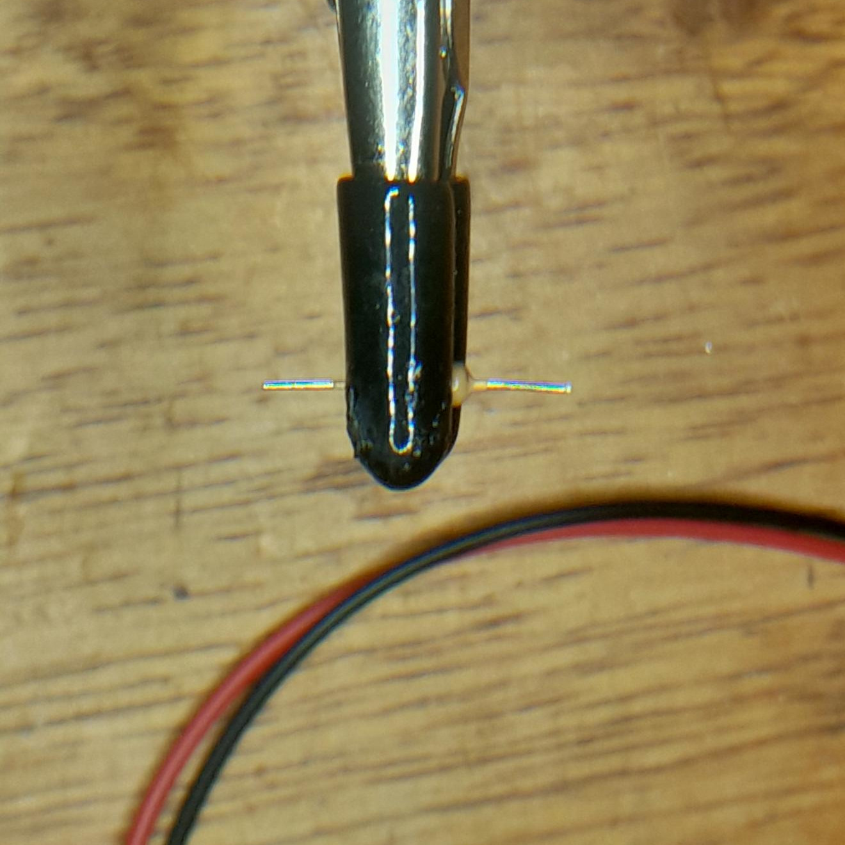
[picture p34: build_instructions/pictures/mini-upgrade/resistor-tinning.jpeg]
Tin the resistor with solder


Solder the resistor on the LED's short leg, add a bit of heatshrink, and solder
to the wire.
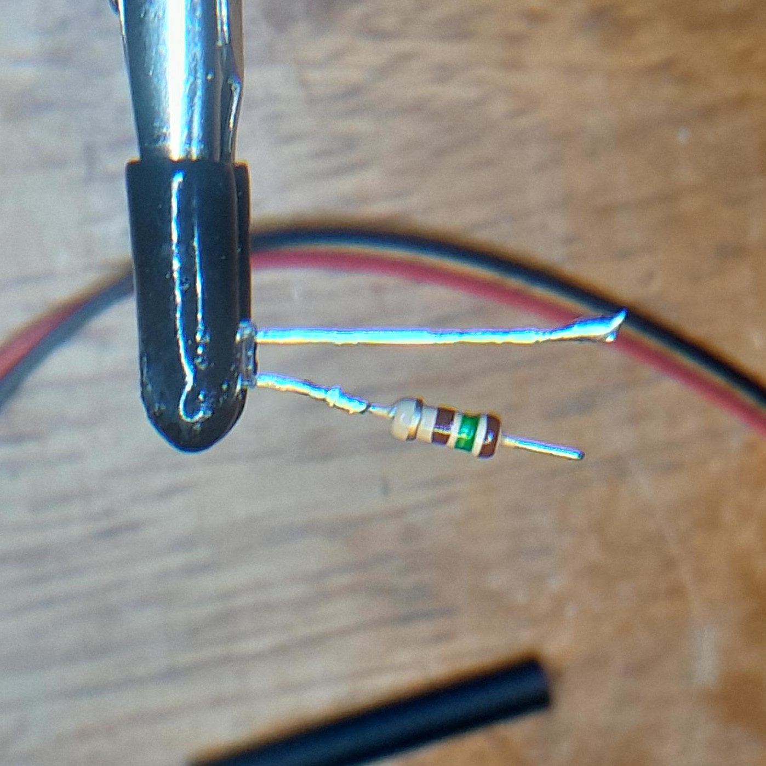
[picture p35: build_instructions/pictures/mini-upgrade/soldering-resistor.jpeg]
Soldering the resistor on the LED

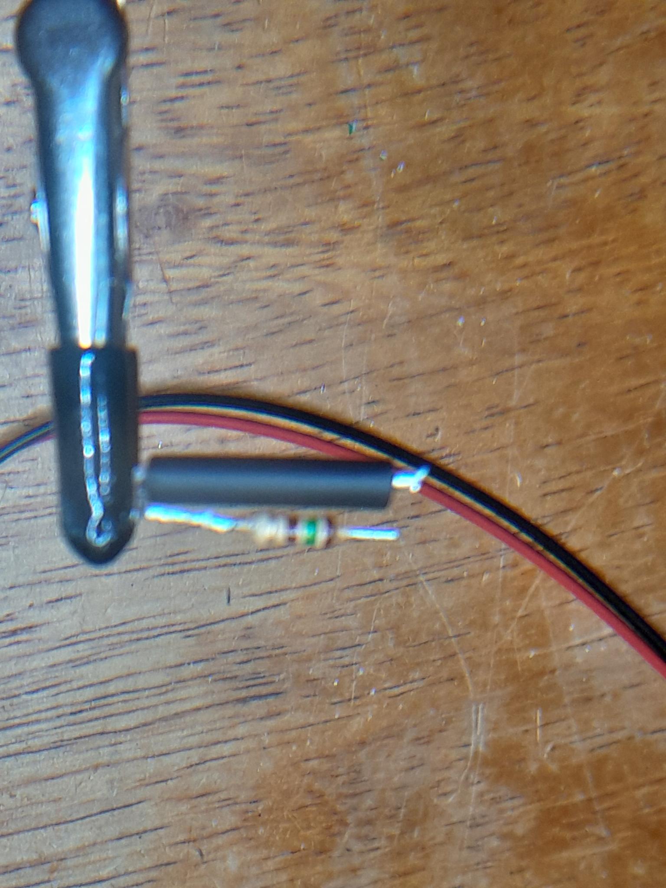
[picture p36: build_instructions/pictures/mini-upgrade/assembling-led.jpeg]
Adding the heatshrink

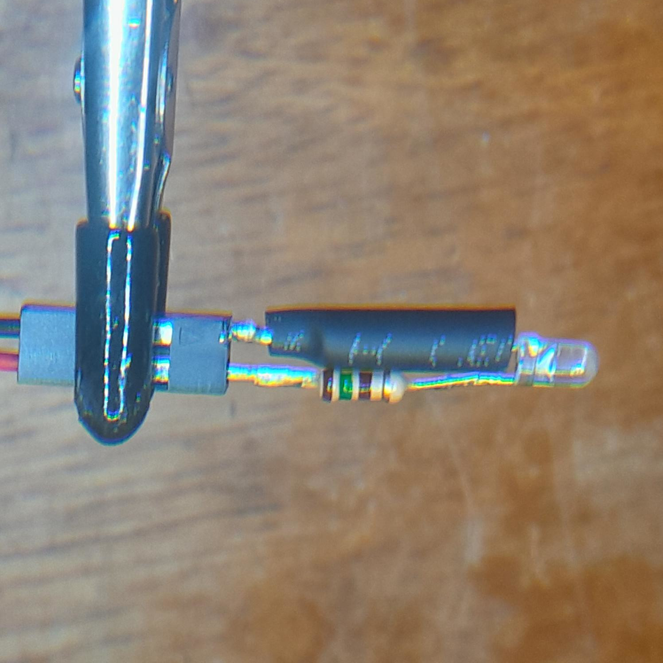
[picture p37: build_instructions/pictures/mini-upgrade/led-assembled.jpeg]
Soldering to the wire


Add a bit of heatshrink around the LED's body, to prevent light from going out
in all directions.
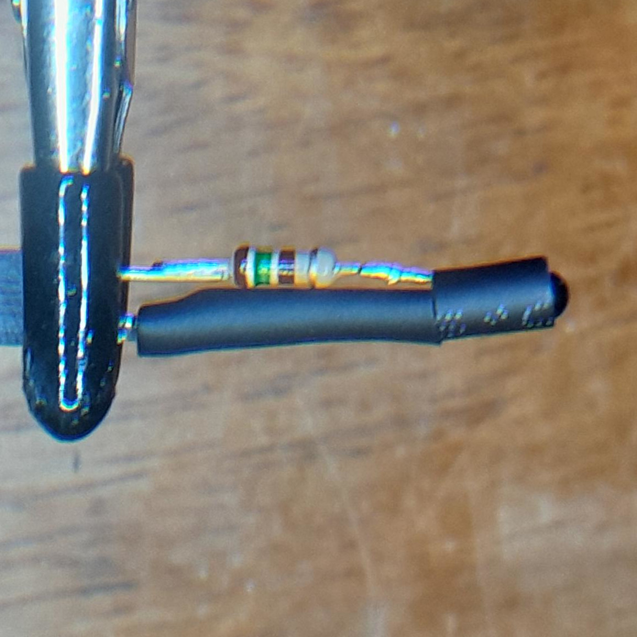
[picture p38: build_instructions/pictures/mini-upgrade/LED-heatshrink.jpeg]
Heatshrinking the LED


## Assemble your kit in the full-size enclosure
Install the PCB in the full-size enclosure, with the provided spacers:
- 2mm under and 7mm on top if you have a PCB-type DB19F connector
- 2+7mm under if you have a solder-cups DB19F connector

Screw the card reader module in place, insert the LED in its holder, and connect
both to the PCB.

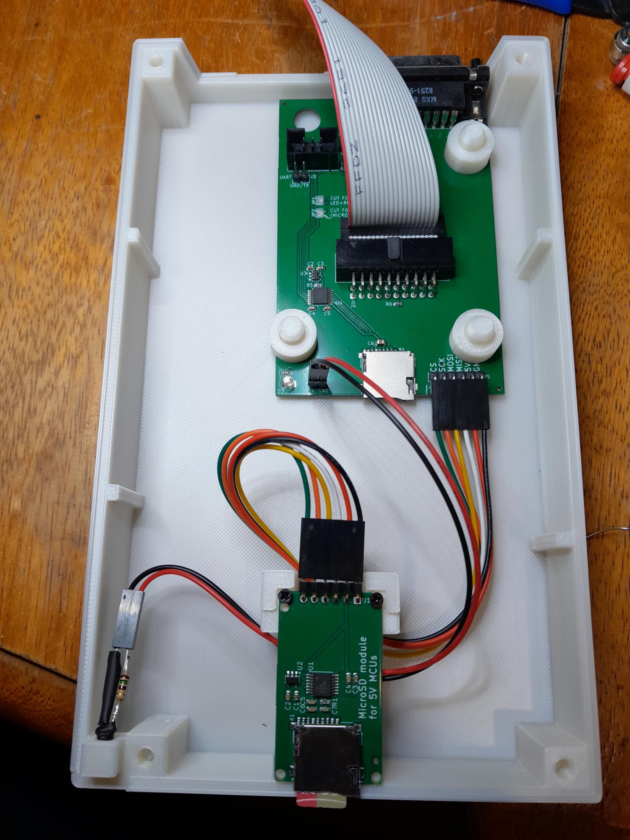
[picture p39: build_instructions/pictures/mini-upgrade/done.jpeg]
The result


Let the IDC-20 cable through its slot, close the enclosure and screw it shut.
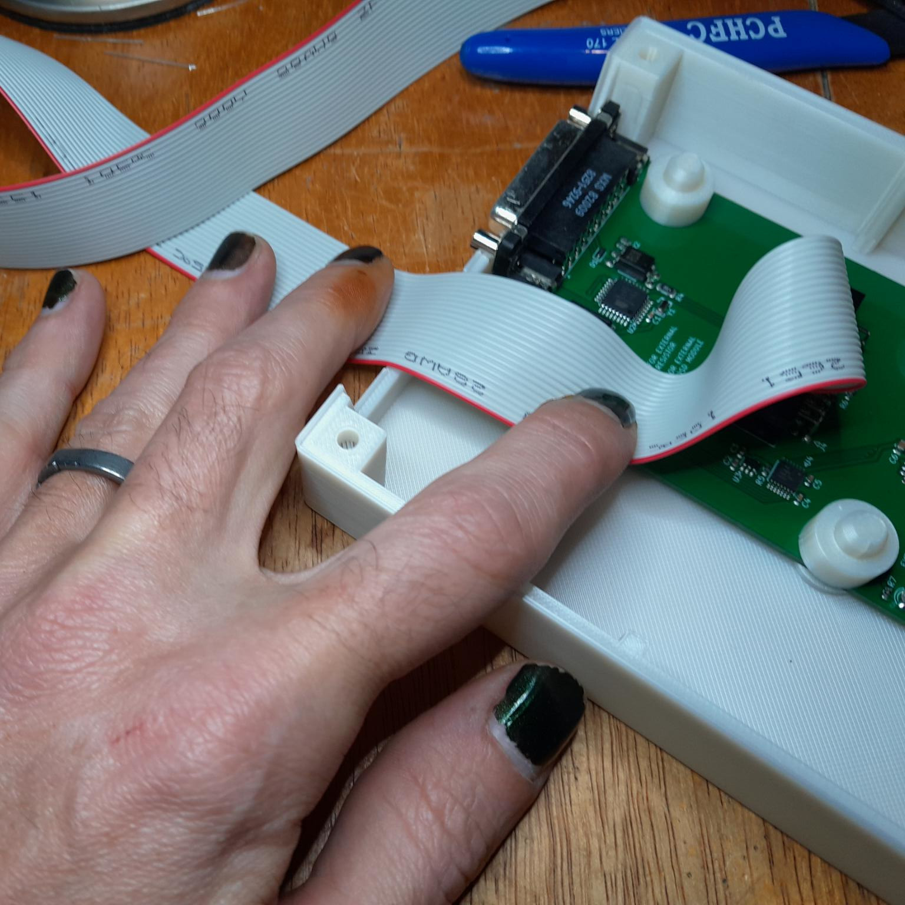
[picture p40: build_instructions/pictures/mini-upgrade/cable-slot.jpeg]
The cable's path


Add the LED diffuser, the logo and feet to the enclosure. You're done!

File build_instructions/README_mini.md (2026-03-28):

# Building the Mini BurgerDisk

## BOM (bill of materials)
Mind that some of the external links provided here might be dead by the time you read this, and
that some of them have options (number of pins, length, etc) that you should double-check
before buying.

**For the main board**, you will need:
- the [assembled main PCB](../PCB/Small-atmega-SMD). Kicad 9 + the 
  [Fabrication toolkit plugin](https://github.com/bennymeg/Fabrication-Toolkit)
  allows for a simple order at JLC, with a few components needing a manual rotation.
- one female DB19 connector, [angled](https://www.ebay.com/itm/284338436979), for daisy-chaining
- one [STK500 AVR ISP programmer](https://aliexpress.com/item/1005006205386137.html) for uploading the firmware to the Arduino

**For connecting to the computer**, you will need:
- The BurgerDisk connection cable, composed of:
  - the [DB19 to IDC20 PCB](../PCB/DB19-IDC20-Adapter)
  - an [IDC20 cable, 2.54mm pitch](https://aliexpress.com/item/1005003853804182.html), at least 50cm
  - an [IDC20 connector, male, 2.54mm pitch](https://aliexpress.com/item/1005001400147026.html)
  - one [male DB19 connector](https://www.ebay.com/itm/257181325655)
  - two [M2 x 12 or 14mm screws](https://aliexpress.com/item/1005006960903249.html)
  - its [enclosure's STL files](../enclosure/Adapter/)
- Alternatively, the [Fujinet's DB19/IDC20 adapter](https://github.com/FujiNetWIFI/fujinet-hardware/tree/master/AppleII/DB-19M-Adapter-Male-Rev1)
can be used, provided that you solder [the -12V and +12V pads between the IDC20
and the DB19, and the DRV2 pad on the side](../build_instructions/pictures/fujinet-db19-adapter.png)

**For the enclosure**, you will need:
- the [enclosure's STL files](../enclosure/Mini/)
- four [M3 x 20mm wood screws](https://aliexpress.com/item/33043885403.html)

## Printing the enclosure
You can use the .stl files provided in [this repository](../enclosure/).
So far I print the enclosure at 15% infill, 0.20mm layer height. With my printer
I don't need support for the overhangs, but your mileage may vary.

### Finishing the main PCB
Insert the female DB19 connector pins on the PCB's top side and clip it. Solder it.

Your PCB now looks like this:
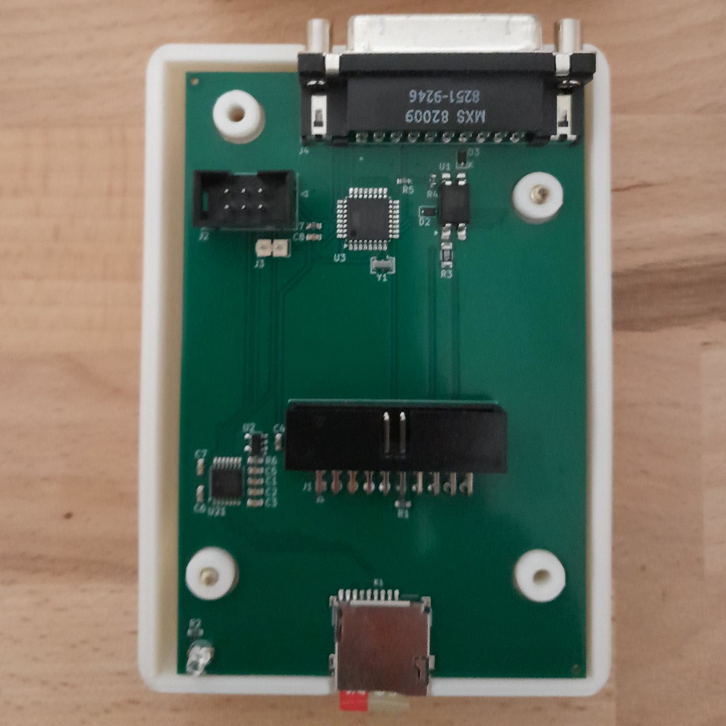
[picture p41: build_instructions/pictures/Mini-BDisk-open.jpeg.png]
The assembled PCB


Connect the ISP programmer to its header, and use `make fuse upload` in the
[firmware](../firmware) directory to program the Atmega. You might need to change the
`PROGRAMMER` variable in the `Makefile`. For the first time, you will need the
install the Arduino IDE, and to run `make setup` once in the
[firmware](../firmware) directory.

### Assembling the adapter-based cable
Align the male DB19 connector with the pads on the adapter PCB. Pay attention
to the alignment, as the DB19 connector will basically be un-desolderable.
Solder it.

Insert the IDC-20 connector in the adapter PCB. It must on the top-side of the
PCB, where the IDC-20 is outlined on the silkscreen. Pay attention to the notch
position, which should be towards the DB19 connector. Solder it.

The adapter, soldered

Insert the assembled adapter into its enclosure, and screw it shut with two M2
x 12 (or 14) mm screws.

The adapter, assembled

## Assembling in the enclosure

Connect the IDC-20 cable to both the main PCB and the adapter. The notch is not on
the same side at both ends, so one way is more satisfying than the other. Make it
so the IDC-20 cable goes directly behind the adapter.

Close the enclosure, with the IDC-20 cable exiting right over the DB19, and screw
it shut with 4x20mm screws. Add rubber feet.

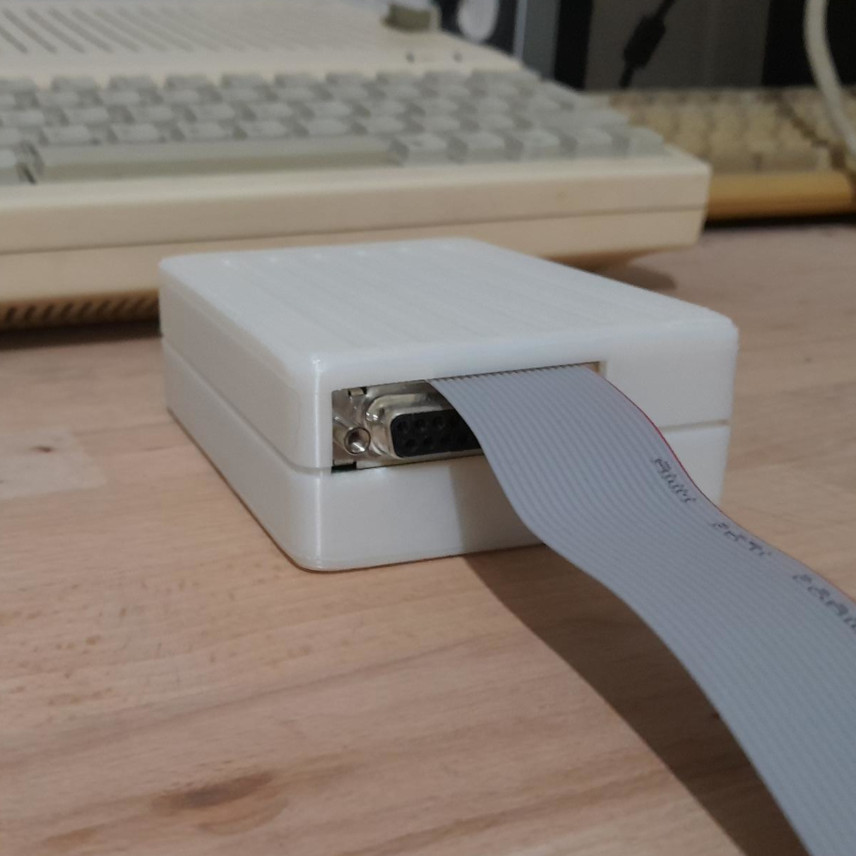
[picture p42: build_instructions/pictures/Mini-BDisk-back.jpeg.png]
The assembled unit


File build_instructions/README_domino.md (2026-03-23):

# Building the DominoDisk

## BOM (bill of materials)
Mind that some of the external links provided here might be dead by the time you read this.

**For the main board**, you will need:
- the [assembled main PCB](../PCB/DominoDisk-SMD). Kicad 9 + the 
  [Fabrication toolkit plugin](https://github.com/bennymeg/Fabrication-Toolkit)
  allows for a simple order at JLC, with a few components needing a manual rotation.
  Don't forget to have them assemble **both sides**.
- one female DB19 connector, [solder cups type](https://www.ebay.com/itm/165875193091), for daisy-chaining
- one male DB19 connector, [solder cups type](https://www.ebay.com/itm/116595555769)
- one [STK500 AVR ISP programmer](https://aliexpress.com/item/1005006205386137.html) for uploading the firmware to the Arduino

**For the enclosure**, you will need:
- the [enclosure's STL files](../enclosure/Domino/)
- four [M2 x 12mm wood screws](https://aliexpress.com/item/1005006960903249.html)

## Printing the enclosure
You can use the .stl files provided in [this repository](../enclosure/).
So far I print the enclosure at 100% infill, 0.20mm layer height.

### Finishing the main PCB
Insert the female DB19 connector pins on the PCB, at the J1 (DB19F) edge connector.
Insert the male DB19 connector pins on the PCB, at the J3 (DB19M) edge connector.
Solder them, both sides.

Your PCB now looks like this:
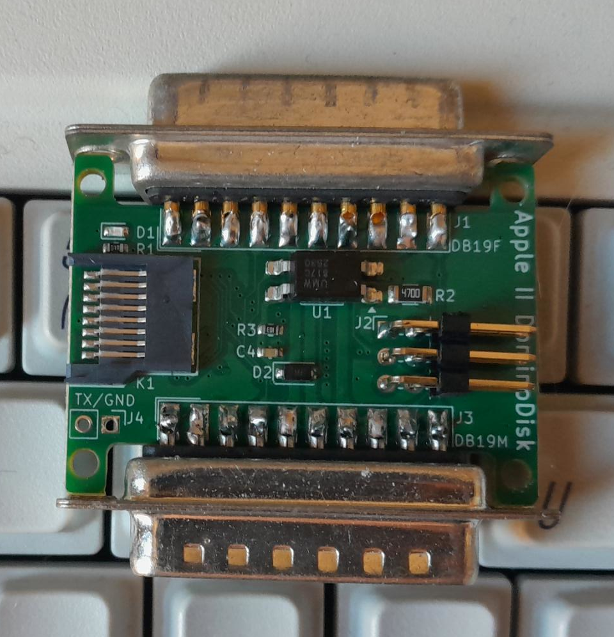
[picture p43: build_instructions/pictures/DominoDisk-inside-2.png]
The assembled PCB


Connect the ISP programmer to its header, notch up (the other way is impossible anyway).
Use `make fuse upload` in the [firmware](../firmware) directory to program the
Atmega. You might need to change the `PROGRAMMER` variable in the `Makefile`.
For the first time, you will need the install the Arduino IDE, and to run 
`make setup` once in the [firmware](../firmware) directory.

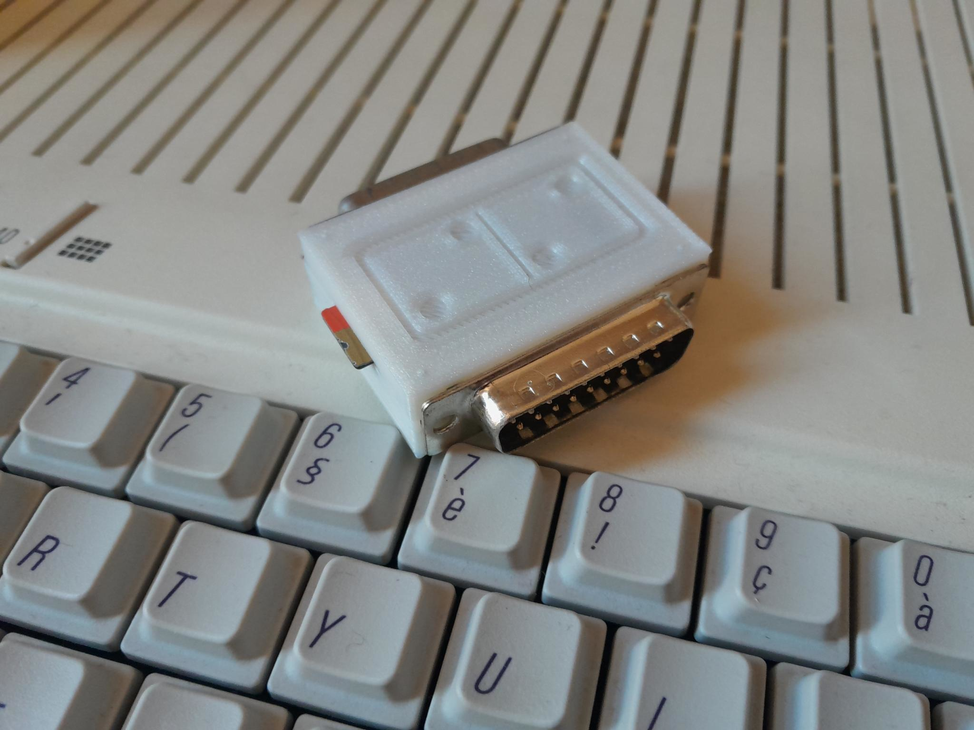
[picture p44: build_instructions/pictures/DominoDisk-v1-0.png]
The assembled unit


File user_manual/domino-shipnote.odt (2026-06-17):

DominoDisk Smartport Hard Disk for Apple II

Quickstart

Thank you for getting a DominoDisk! I hope you will like it.

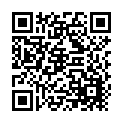
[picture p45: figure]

| The User Manual is available at https://www.colino.net/wordpress/wp-content/burgerdisk-user-manual.pdf

Here are the most relevant parts:

Insert a FAT-formatted microSD card in the slot, face up. The ProDOS volumes presented to the Apple II must be named PART1.po to PART4.po, or be referenced in a config.txt file containing up to four lines with the filenames. For example:

A2Desktop.hdv

Total_Replay.hdv

ProDOS 2.4.3.po

System Utilities.dsk

Do not hotplug Apple II storage devices while the Apple II is powered on.

Plug any “dumb” 3.5inch drive first, followed by the DominoDisk and Smartport devices, followed by 5.25” drives.

Have fun,

Colin - colin@colino.net

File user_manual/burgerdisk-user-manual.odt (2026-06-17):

BurgerDisk/DominoDisk Smartport Hard Disk for Apple II

User manual

Version 2.5

April 2026

colin@colino.net – https://www.colino.net/

# Index of Figures

Figure 1: Inserting the MicroSD card 5

Figure 2: Example daisy-chain 6

# Index of Tables

Table 1: Example config.txt 4

# Introduction

BurgerDisk and DominoDisk are Smartport hard disks, with storage backed on a microSD card, for the Apple II line of computers running ProDOS.

Both devices share the same firmware and the same features, so this user manual applies equally to both devices.

It is compatible with the Smartport-enabled Apple II models:

- The Apple //c (apart from the ROM255 version, which can be upgraded)
- The Apple IIgs
- Slotted Apple II computers with a DiskII controller and a SoftSP card.

It is daisy-chainable, which lets you use other storage devices with it.

# BurgerDisk storage configuration

## Presenting disk images to the computer

Different image formats are supported:

- .po (in ProDOS-ordered format)
- .2mg (in ProDOS-ordered format)
- .dsk (in ProDOS or DOS3.3-ordered format, but of ProDOS volumes)
- .hdv

These images can be either 140KB, 400KB, 800KB, or an arbitrary number of blocks up to 32MB (65535 blocks).

The BurgerDisk does not support .woz, .nib, .edf, .do images.

BurgerDisk uses these disk images to present to ProDOS. They are stored as files on the MicroSD card, formatted as FAT.

By default, the firmware will search for four files: PART1.po, PART2.po, PART3.po, PART4.po, and present them if they exist.

You can also put images with arbitrary names, and reference at most four of them in the config.txt file at the root of the MicroSD’s filesystem.

Table 1: Example config.txt

A2DeskTop-1.5-en_800k.2mg

Total Replay v5.2.hdv

Documents.po

Your Apple II can boot from any slot, but only from the first device in any slot. For the BurgerDisk, this means you can boot from the first partition if the device is first in the daisy-chain. Booting from another partition requires modifying their order in config.txt.

Afterwards, you can insert the MicroSD card in its slot (face up, connector down), connect your device to your Apple II, and boot it.

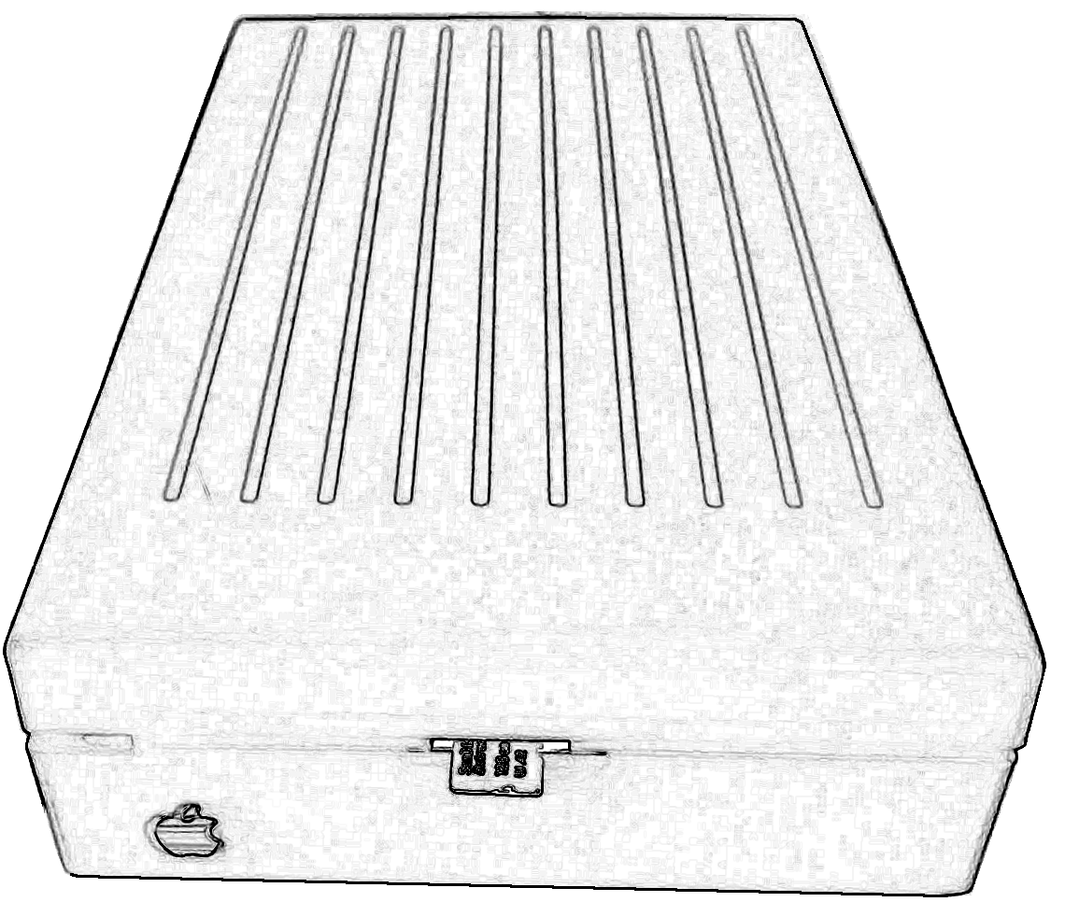
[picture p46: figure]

Figure 1: Inserting the MicroSD card

Push the card until it clicks in place. Push it again to remove it.

## Debugging and options

debug (default 0): If you would like to work on the BurgerDisk firmware, enabling debug messages on its serial port will be useful. You can do that by adding debug=1 in an options.txt file at the root of the SD card.

force_next_smartport (default 1): By default, BurgerDisk lies to the controller, telling it there are more Smartport devices after it. This makes chaining an SPIISD (or other devices that do not correctly advertise themselves as Smartport devices) possible. It has no adverse effects, but this can be disabled using force_next_smartport=0 in the options.txt file.

# BurgerDisk installation

To connect the BurgerDisk to your Apple II, you can either plug it directly to the computer, or to another device, in what is called a Daisy Chain. This allows you to have multiple storage devices connected to your computer. Daisy chains have rules about devices ordering:

- First “dumb” 3.5” floppy drives, like the Apple 3.5 Drive (A9M0106)

- then Smartport devices, like the Unidisk 3.5 (A2M2053) or the BurgerDisk

- followed by 5.25” floppy drives (except on Liron cards, which do not handle 5.25” drives at all)

In this example, the Apple II will be able to boot from the Unidisk 3.5”. To boot from the BurgerDisk’s first partition, invert the Unidisk 3.5” and BurgerDisk, so that the BurgerDisk is connected to the computer, the Unidisk connected to the BurgerDisk, and the Disk //c connected to the Unidisk.

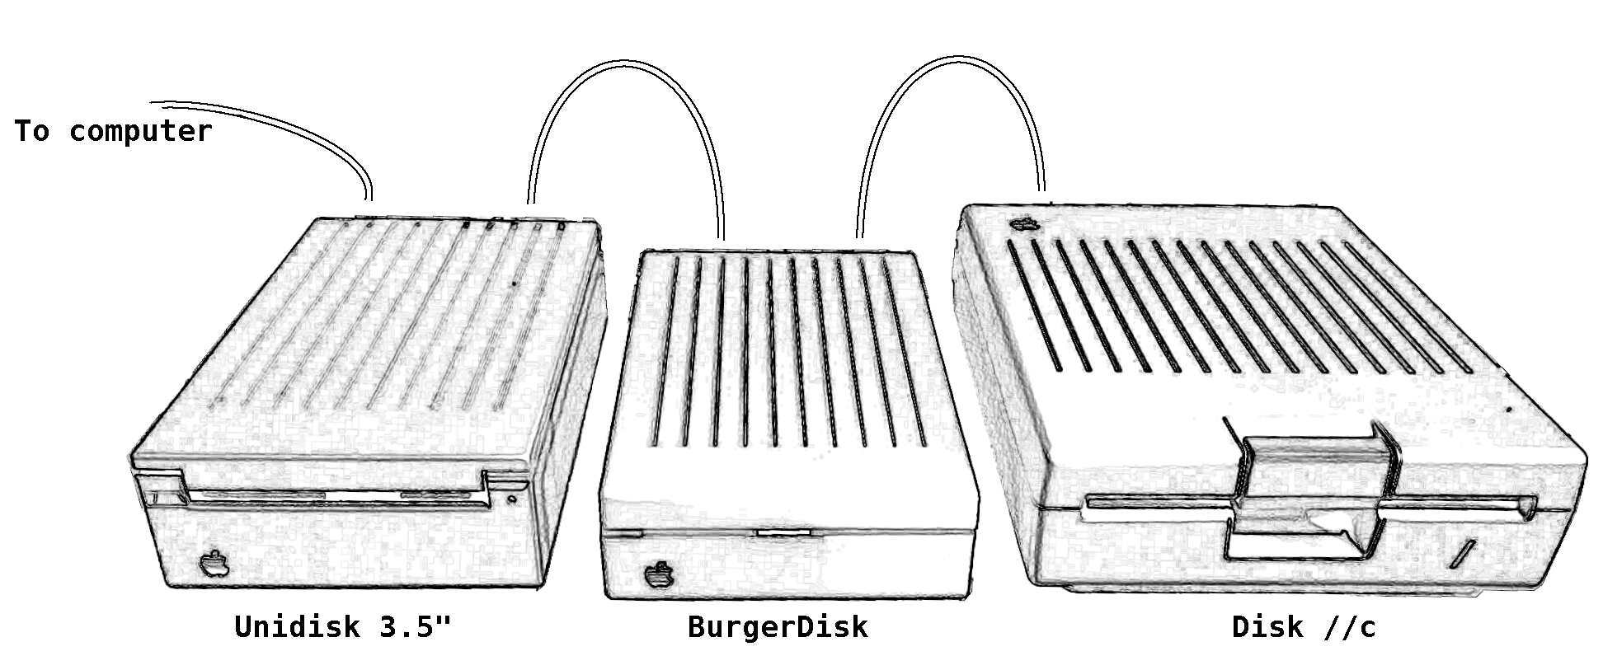
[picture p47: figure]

Figure 2: Example daisy-chain

# Booting the computer

The Apple II can boot from the first device in a given slot. Smartport devices are usually in slot #5, and 5.25” drives in slot #6.

If you want to boot your Apple II from the BurgerDisk, use a bootable image, like A2Desktop, as first image; and connect the BurgerDisk first to the computer.

Note: this means that you cannot directly boot from the BurgerDisk if an Apple 3.5” drive (A9M0106) is present in your chain, even if no floppy is inserted into it; because the A9M0106 drive has to be connected first.

# Troubleshooting

## Serial debug output

If you are investigating a problem or experimenting with your own modifications of the firmware, you might want to enable debug output on the Arduino’s serial port.

This can be enabled with a debug=1 line in options.txt.

Afterwards, you can open the enclosure, locate the UART port, and connect an UART to USB adapter to it. Connect the UART’s GND to the adapter’s GND, and the UART’s TX to the adapter’s RX.

## Blinking LED, no image mounted

If after booting the Apple II, a small delay happens, followed by the BurgerDisk’s LED blinking 4 times per second, and none of its volumes are visible by ProDOS, this means that the MicroSD card initialization failed, or that zero valid images were found on the card. Verify its presence and contents.

## Compatibility

So far, the BurgerDisk has been tested on:

- Apple //c ROM3, model A2S4000
- Apple //c ROM4x, model A2S4100
- Apple IIgs, ROM01
- Apple IIe, Liron card
- Apple IIe, DiskII controller + SoftSP card

Various daisy chaining configurations have been tested:

- only the BurgerDisk on the Smartport bus
- Unidisk 3.5”, then BurgerDisk
- BurgerDisk, then Disk //c
- Unidisk 3.5”, then BurgerDisk, then Disk //c
- Unidisk 3.5”, then BurgerDisk, then another BurgerDisk, then Disk //c
- BurgerDisk, then Unidisk 3.5”, then Disk //c

In case of problems in a daisy chain, verify that your chain respect Apple’s rules, and that the chained devices are actually able to be chained.

Liron card notes: the Liron card is not able to drive a 5.25” drive.

SoftSP card notes: the SoftSP card is not able to drive a Unidisk 3.5” drive. It has annoying, but non-blocking issues with 5.25” drives.

Compatibility with the SPIISD, Fujinet, or other Smartport-based devices has not yet been tested.

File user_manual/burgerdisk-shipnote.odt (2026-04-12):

BurgerDisk Smartport Hard Disk for Apple II

Quickstart

Thank you for getting a BurgerDisk! I hope you will like it.


| The User Manual is available at https://www.colino.net/wordpress/wp-content/burgerdisk-user-manual.pdf

Here are the most relevant parts:

Insert a FAT-formatted microSD card in the slot, face up. The volumes presented to the Apple II must be named PART1.po to PART4.po, or be referenced in a config.txt file containing up to four lines with the filenames. For example:

A2Desktop.hdv

Total_Replay.hdv

ProDOS 2.4.3.po

Do not hotplug Apple II storage devices while the Apple II is powered on.

Plug any “dumb” 3.5inch drive first, followed by the DominoDisk and Smartport devices, followed by 5.25” drives.

Your enclosure comes with a placeholder logo taped at the front. You can either glue it, or replace it with a real vintage Apple logo if you have one!

Have fun,

Colin

colin@colino.net

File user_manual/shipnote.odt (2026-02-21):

BurgerDisk Smartport Hard Disk for Apple II

Quickstart

Thank you for getting a BurgerDisk! I hope you will like it.

Quick pointers to start using it:


| The User Manual is available at https://www.colino.net/wordpress/wp-content/burgerdisk-user-manual.pdf

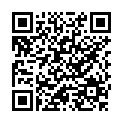
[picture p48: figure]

| Assembly instructions are available at https://github.com/colinleroy/BurgerDisk/tree/main/build_instructions


Your enclosure comes with a 3D-printed Apple logo taped to it. You can either glue it, or remove it and glue a real vintage Apple logo if you have one available.

Have fun!

# Kit contents

Small components taped here

R2 150Ω | R1 330Ω | D1 removed | D2 1N4448 | D3 1N5818 | R4 10kΩ | R5 1kΩ | R3 470Ω
| | Errata: D1 was an issue with SoftSP cards.Solder a leg from another component instead.

In the box, for the PCB

- One BurgerDisk PCB
- One adapter PCB
- One Arduino Nano
- One MicroSD module
- One pair of DB19 connectors
- One pair of IDC20 connectors
- One pair of 15-pin sockets
- One LED
- One PC817 optocoupler
- Two 2-pin headers
- One 6-pin header
- One 6-pin cable
- One 2-pin cable
- One IDC20 cable
- 2 M2x8mm screws

In the box, for the enclosure

- The enclosure itself
- The adapter’s enclosure
- One LED diffuser
- One white Apple logo
- Two M2x12mm screws
- Four M3x20mm screws

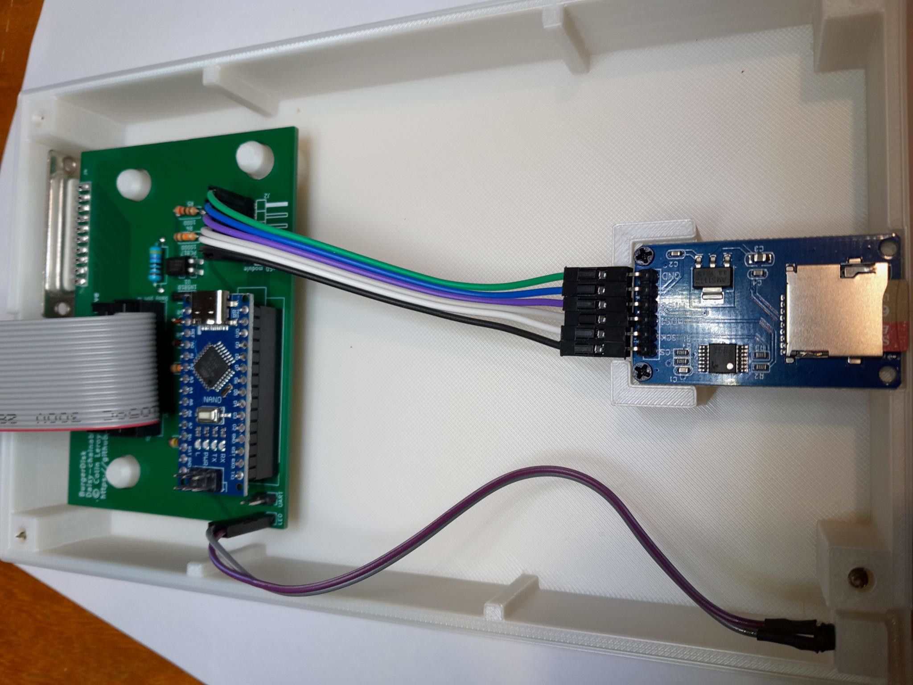
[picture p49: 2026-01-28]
build_instructions/pictures/BurgerDisk-v2.0-assembled.jpeg

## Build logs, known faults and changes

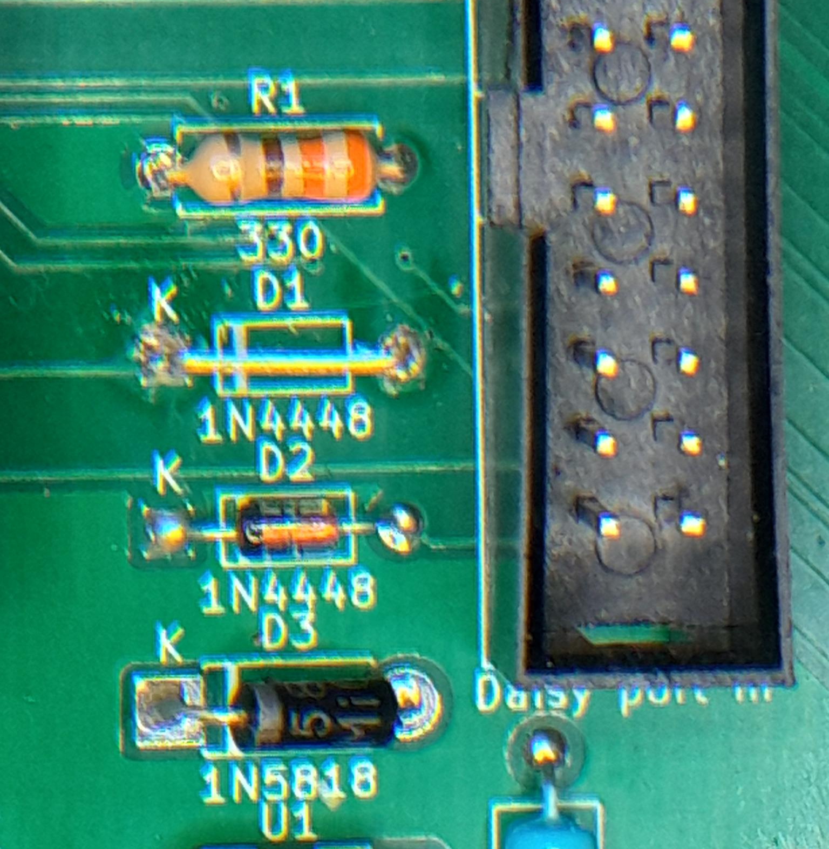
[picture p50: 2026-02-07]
build_instructions/pictures/D1_errata.png

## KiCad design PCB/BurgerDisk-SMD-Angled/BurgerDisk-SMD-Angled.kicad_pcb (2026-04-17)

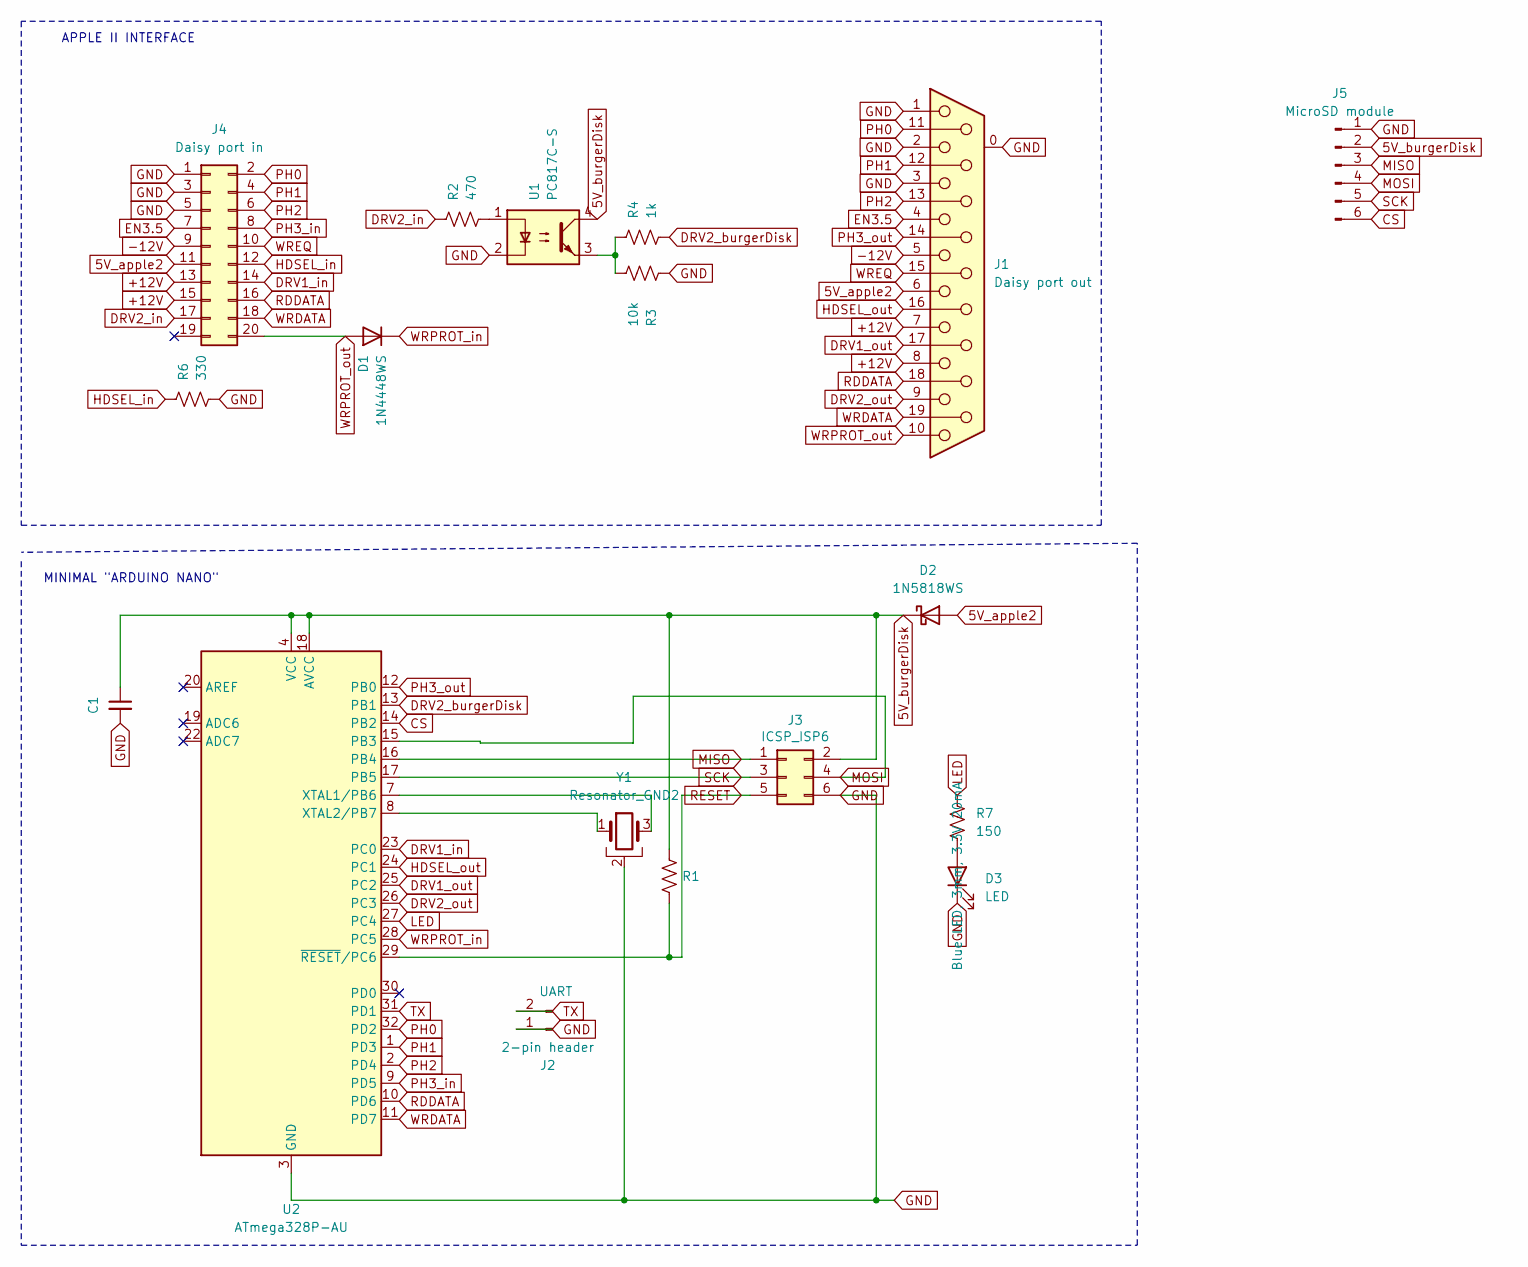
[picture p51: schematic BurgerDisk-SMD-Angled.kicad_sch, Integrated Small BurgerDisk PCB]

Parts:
C1: 100n; C_0603_1608Metric; LCSC C14663
D1: 1N4448WS; D_SOD-323_HandSoldering; LCSC C167101
D2: 1N5818WS; D_SOD-323_HandSoldering; LCSC C5240366
D3: LED; PinHeader_1x02_P2.54mm_Vertical; LCSC C32713268
J1: Daisy port out; DSUB-19_Female_Horizontal_MXS82009-8251-9246
J2: 2-pin header; PinHeader_1x02_P2.54mm_Vertical; LCSC C32713268
J3: ICSP_ISP6; IDC-Header_2x03_P2.54mm_Vertical; LCSC C11214
J4: Daisy port in; IDC-Header_2x10_P2.54mm_Horizontal; LCSC C9144
J5: MicroSD module; PinHeader_1x06_P2.54mm_Vertical; LCSC C56816
R1: 10K; R_0603_1608Metric; LCSC C25804
R2: 470; R_1206_3216Metric; LCSC C137212
R3: 10k; R_0603_1608Metric; LCSC C25804
R4: 1k; R_0603_1608Metric; LCSC C21190
R6: 330; R_0603_1608Metric; LCSC C23138
R7: 150; R_0603_1608Metric; LCSC C22808
U1: PC817C-S; SOP-4_3.8x4.1mm_P2.54mm; LCSC C3008369
U2: ATmega328P-AU; TQFP-32_7x7mm_P0.8mm; LCSC C14877
Y1: Resonator_GND2; Resonator_SMD_Murata_CSTxExxV-3Pin_3.0x1.1mm; LCSC C341521

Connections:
5V_apple2: D2.2 (A), J1.6, J4.11
5V_burgerDisk: C1.1, D2.1 (K), J3.2, J5.2, R1.1, U1.4, U2.4 (VCC), U2.6 (VCC), U2.18 (AVCC)
+12V: J1.7, J1.8, J4.13, J4.15
-12V: J1.5, J4.9
CS: J5.6, U2.14 (PB2)
DRV1_in: J4.14, U2.23 (PC0)
DRV1_out: J1.17, U2.25 (PC2)
DRV2_burgerDisk: R4.1, U2.13 (PB1)
DRV2_in: J4.17, R2.1
DRV2_out: J1.9, U2.26 (PC3)
EN3.5: J1.4, J4.7
GND: C1.2, D3.1 (K), J1.0 (GND), J1.1, J1.2, J1.3, J2.1, J3.6, J4.1, J4.3, J4.5, J5.1, R3.1, R6.1, U1.2, U2.3 (GND), U2.5 (GND), U2.21 (GND), Y1.2
HDSEL_in: J4.12, R6.2
HDSEL_out: J1.16, U2.24 (PC1)
LED: R7.2, U2.27 (PC4)
MISO: J3.1, J5.3, U2.16 (PB4)
MOSI: J3.4, J5.4, U2.15 (PB3)
unnamed: D3.2 (A), R7.1
unnamed: R2.2, U1.1
unnamed: R3.2, R4.2, U1.3
unnamed: U2.7 (XTAL1/PB6), Y1.3
unnamed: U2.8 (XTAL2/PB7), Y1.1
PH0: J1.11, J4.2, U2.32 (PD2)
PH1: J1.12, J4.4, U2.1 (PD3)
PH2: J1.13, J4.6, U2.2 (PD4)
PH3_in: J4.8, U2.9 (PD5)
PH3_out: J1.14, U2.12 (PB0)
RDDATA: J1.18, J4.16, U2.10 (PD6)
RESET: J3.5, R1.2, U2.29 (~RESET/PC6)
SCK: J3.3, J5.5, U2.17 (PB5)
TX: J2.2, U2.31 (PD1)
WRDATA: J1.19, J4.18, U2.11 (PD7)
WREQ: J1.15, J4.10
WRPROT_in: D1.1 (K), U2.28 (PC5)
WRPROT_out: D1.2 (A), J1.10, J4.20

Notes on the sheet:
APPLE II INTERFACE
MINIMAL "ARDUINO NANO"

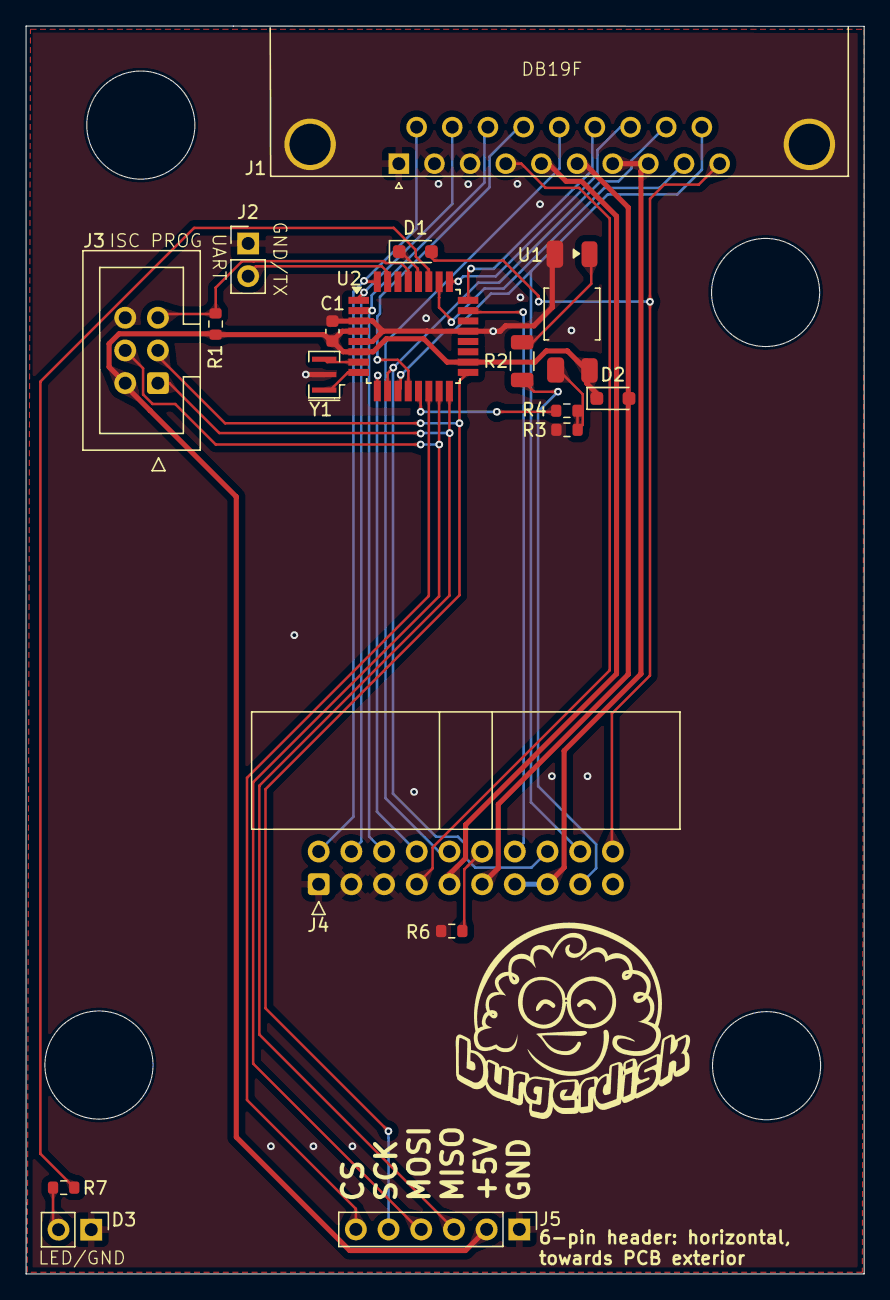
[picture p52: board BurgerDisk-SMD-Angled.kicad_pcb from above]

Board: 2 copper layers, 65.1 x 96.9 mm, 18 parts (0 on the bottom side), 35 nets.

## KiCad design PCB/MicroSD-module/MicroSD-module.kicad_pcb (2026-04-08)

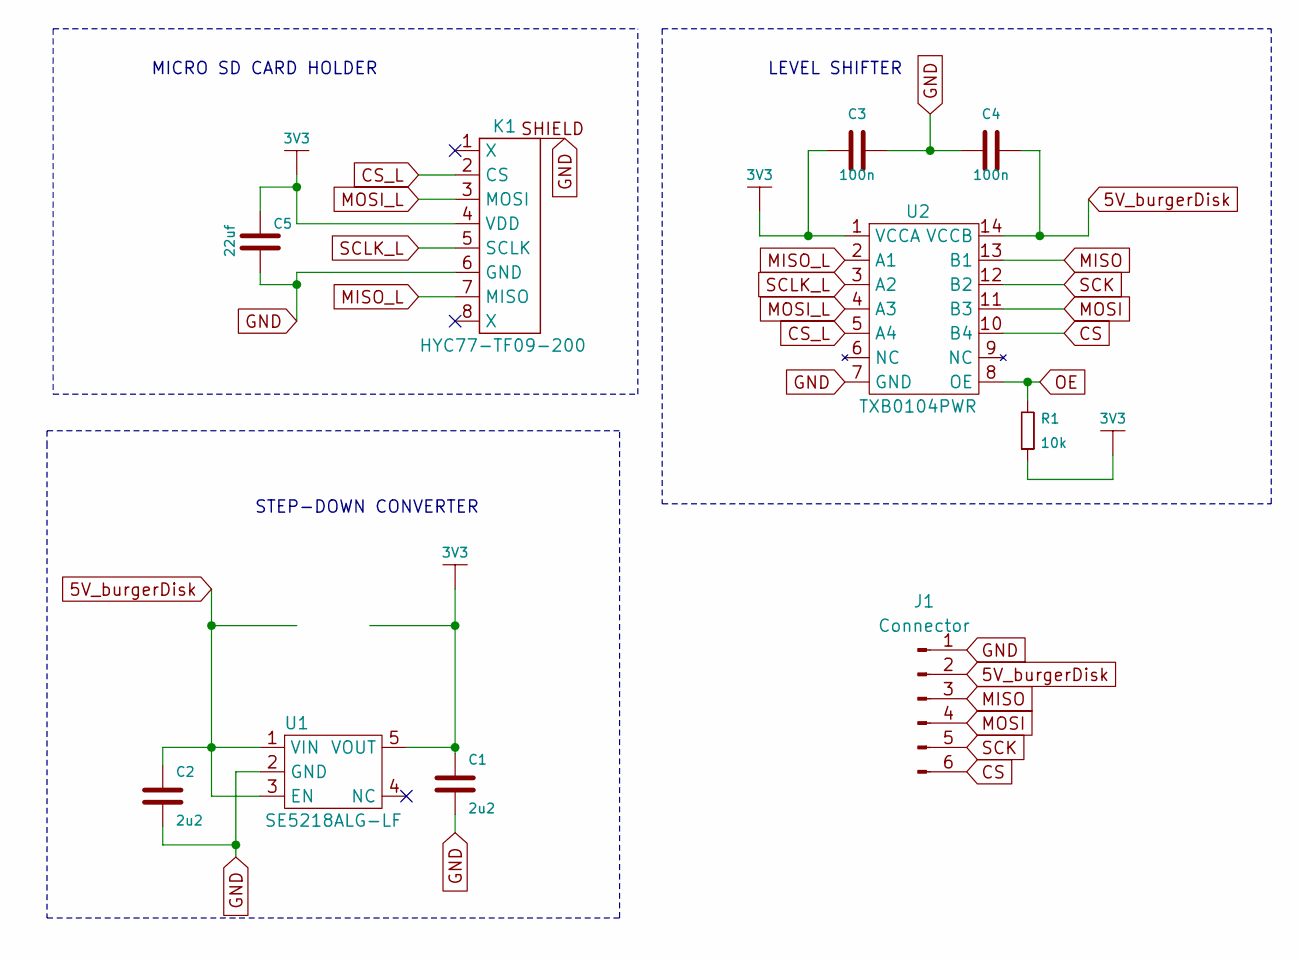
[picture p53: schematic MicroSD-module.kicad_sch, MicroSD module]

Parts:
C1, C2: 2u2; C_0603_1608Metric; LCSC C1607
C3, C4: 100n; C_0603_1608Metric; LCSC C1590
C5: 22uf; C_0805_2012Metric; LCSC C45783
J1: Connector; PinHeader_1x06_P2.54mm_Horizontal; LCSC C56816
K1: HYC77-TF09-200; MICROSD-HYC77-TF09-200; LCSC C341092
R1: 10k; R_0603_1608Metric; LCSC C177337
U1: SE5218ALG-LF; SOT-23-5; LCSC C118233
U2: TXB0104PWR; TSSOP-14-1EP_4.4x5mm_P0.65mm; LCSC C60708

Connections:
3V3: C1.2, C3.1, C5.2, K1.4 (VDD), R1.1, U1.5 (VOUT), U2.1 (VCCA)
5V_burgerDisk: C2.2, C4.2, J1.2, U1.1 (VIN), U1.3 (EN), U2.14 (VCCB)
CS: J1.6, U2.10 (B4)
CS_L: K1.2 (CS), U2.5 (A4)
GND: C1.1, C2.1, C3.2, C4.1, C5.1, J1.1, K1.6 (GND), K1.SHIELD, U1.2 (GND), U2.7 (GND)
MISO: J1.3, U2.13 (B1)
MISO_L: K1.7 (MISO), U2.2 (A1)
MOSI: J1.4, U2.11 (B3)
MOSI_L: K1.3 (MOSI), U2.4 (A3)
OE: R1.2, U2.8 (OE)
SCK: J1.5, U2.12 (B2)
SCLK_L: K1.5 (SCLK), U2.3 (A2)

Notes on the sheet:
LEVEL SHIFTER
STEP-DOWN CONVERTER
MICRO SD CARD HOLDER

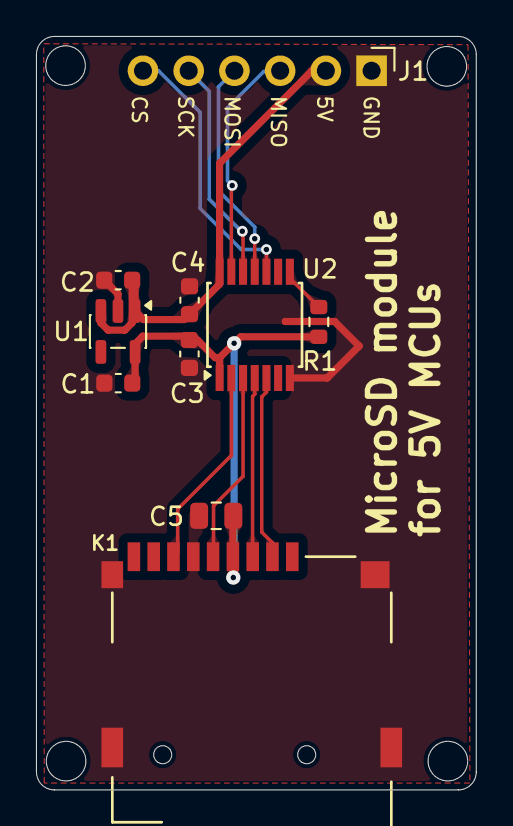
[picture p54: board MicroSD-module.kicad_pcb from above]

Board: 2 copper layers, 24.4 x 41.9 mm, 10 parts (0 on the bottom side), 12 nets.

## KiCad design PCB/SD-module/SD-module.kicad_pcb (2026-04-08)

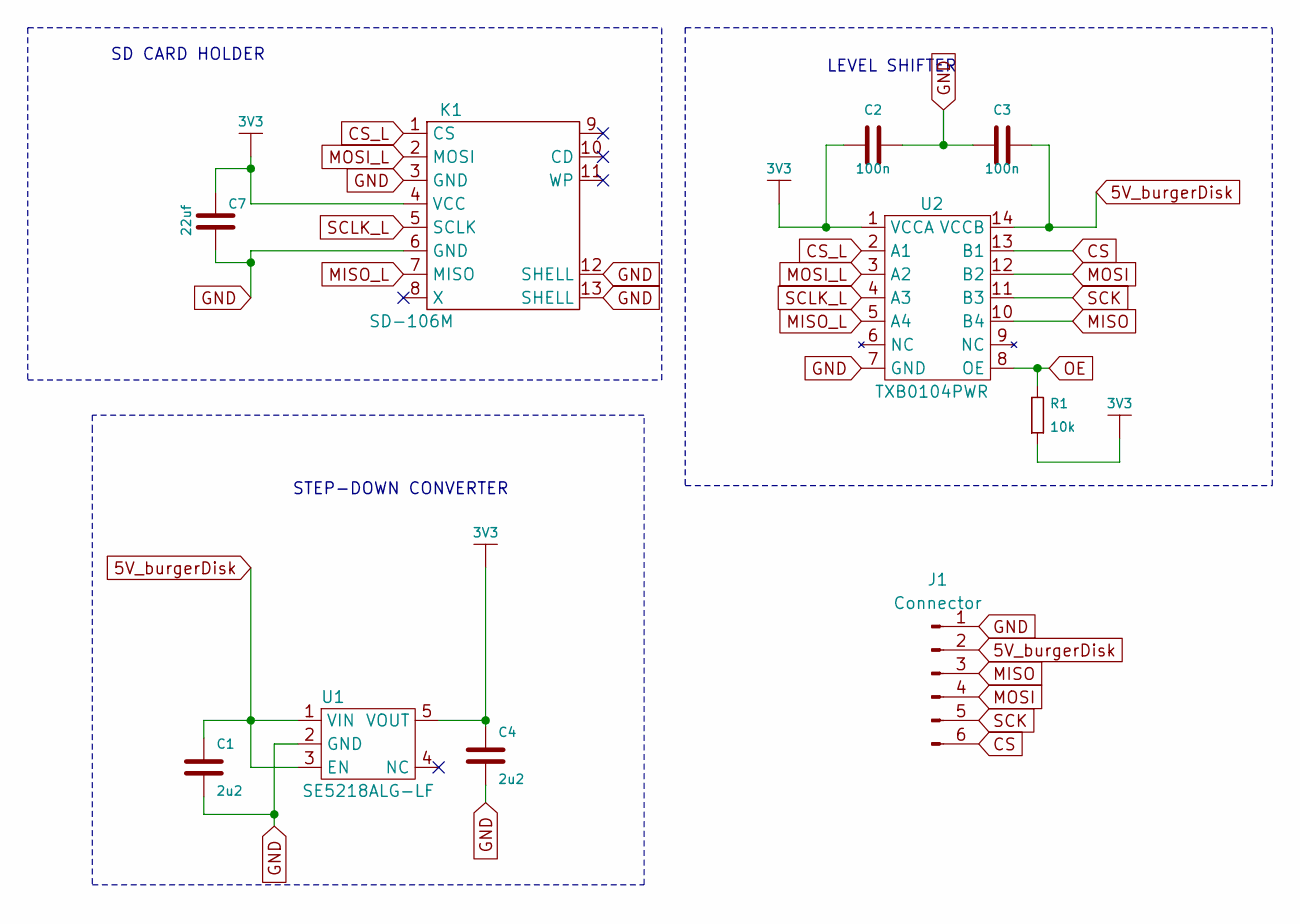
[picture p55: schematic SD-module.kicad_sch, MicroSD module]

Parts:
C1, C4: 2u2; C_0603_1608Metric; LCSC C1607
C2, C3: 100n; C_0603_1608Metric; LCSC C1590
C7: 22uf; C_0805_2012Metric; LCSC C45783
J1: Connector; PinHeader_1x06_P2.54mm_Horizontal; LCSC C56816
K1: SD-106M; SD-SMD_SD-106M; LCSC C266603
R1: 10k; R_0603_1608Metric; LCSC C177337
U1: SE5218ALG-LF; SOT-23-5; LCSC C118233
U2: TXB0104PWR; TSSOP-14-1EP_4.4x5mm_P0.65mm; LCSC C60708

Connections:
3V3: C2.1, C4.2, C7.2, K1.4 (VCC), R1.1, U1.5 (VOUT), U2.1 (VCCA)
5V_burgerDisk: C1.2, C3.2, J1.2, U1.1 (VIN), U1.3 (EN), U2.14 (VCCB)
CS: J1.6, U2.13 (B1)
CS_L: K1.1 (CS), U2.2 (A1)
GND: C1.1, C2.2, C3.1, C4.1, C7.1, J1.1, K1.3 (GND), K1.6 (GND), K1.12 (SHELL), K1.13 (SHELL), U1.2 (GND), U2.7 (GND)
MISO: J1.3, U2.10 (B4)
MISO_L: K1.7 (MISO), U2.5 (A4)
MOSI: J1.4, U2.12 (B2)
MOSI_L: K1.2 (MOSI), U2.3 (A2)
OE: R1.2, U2.8 (OE)
SCK: J1.5, U2.11 (B3)
SCLK_L: K1.5 (SCLK), U2.4 (A3)

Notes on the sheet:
LEVEL SHIFTER
STEP-DOWN CONVERTER
SD CARD HOLDER

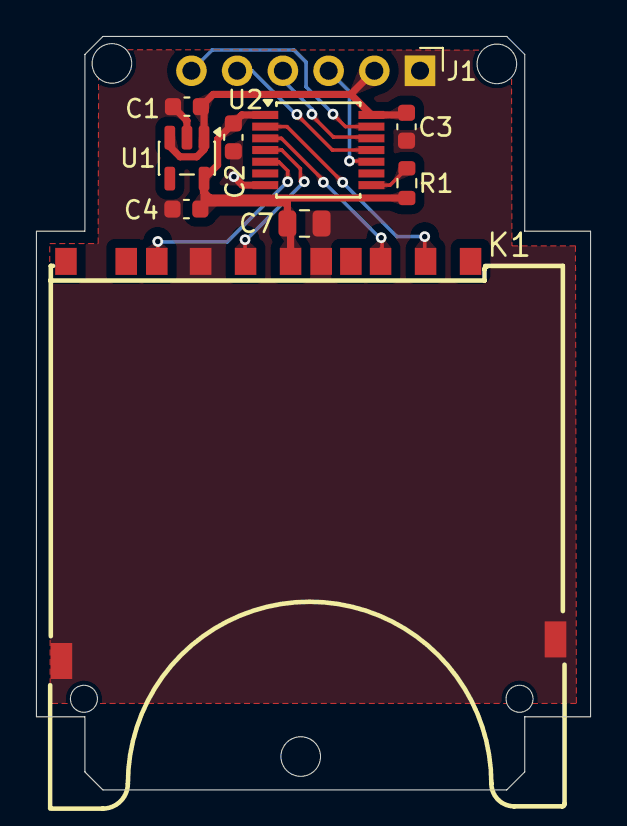
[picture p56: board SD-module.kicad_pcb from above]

Board: 2 copper layers, 30.8 x 41.9 mm, 10 parts (0 on the bottom side), 12 nets.

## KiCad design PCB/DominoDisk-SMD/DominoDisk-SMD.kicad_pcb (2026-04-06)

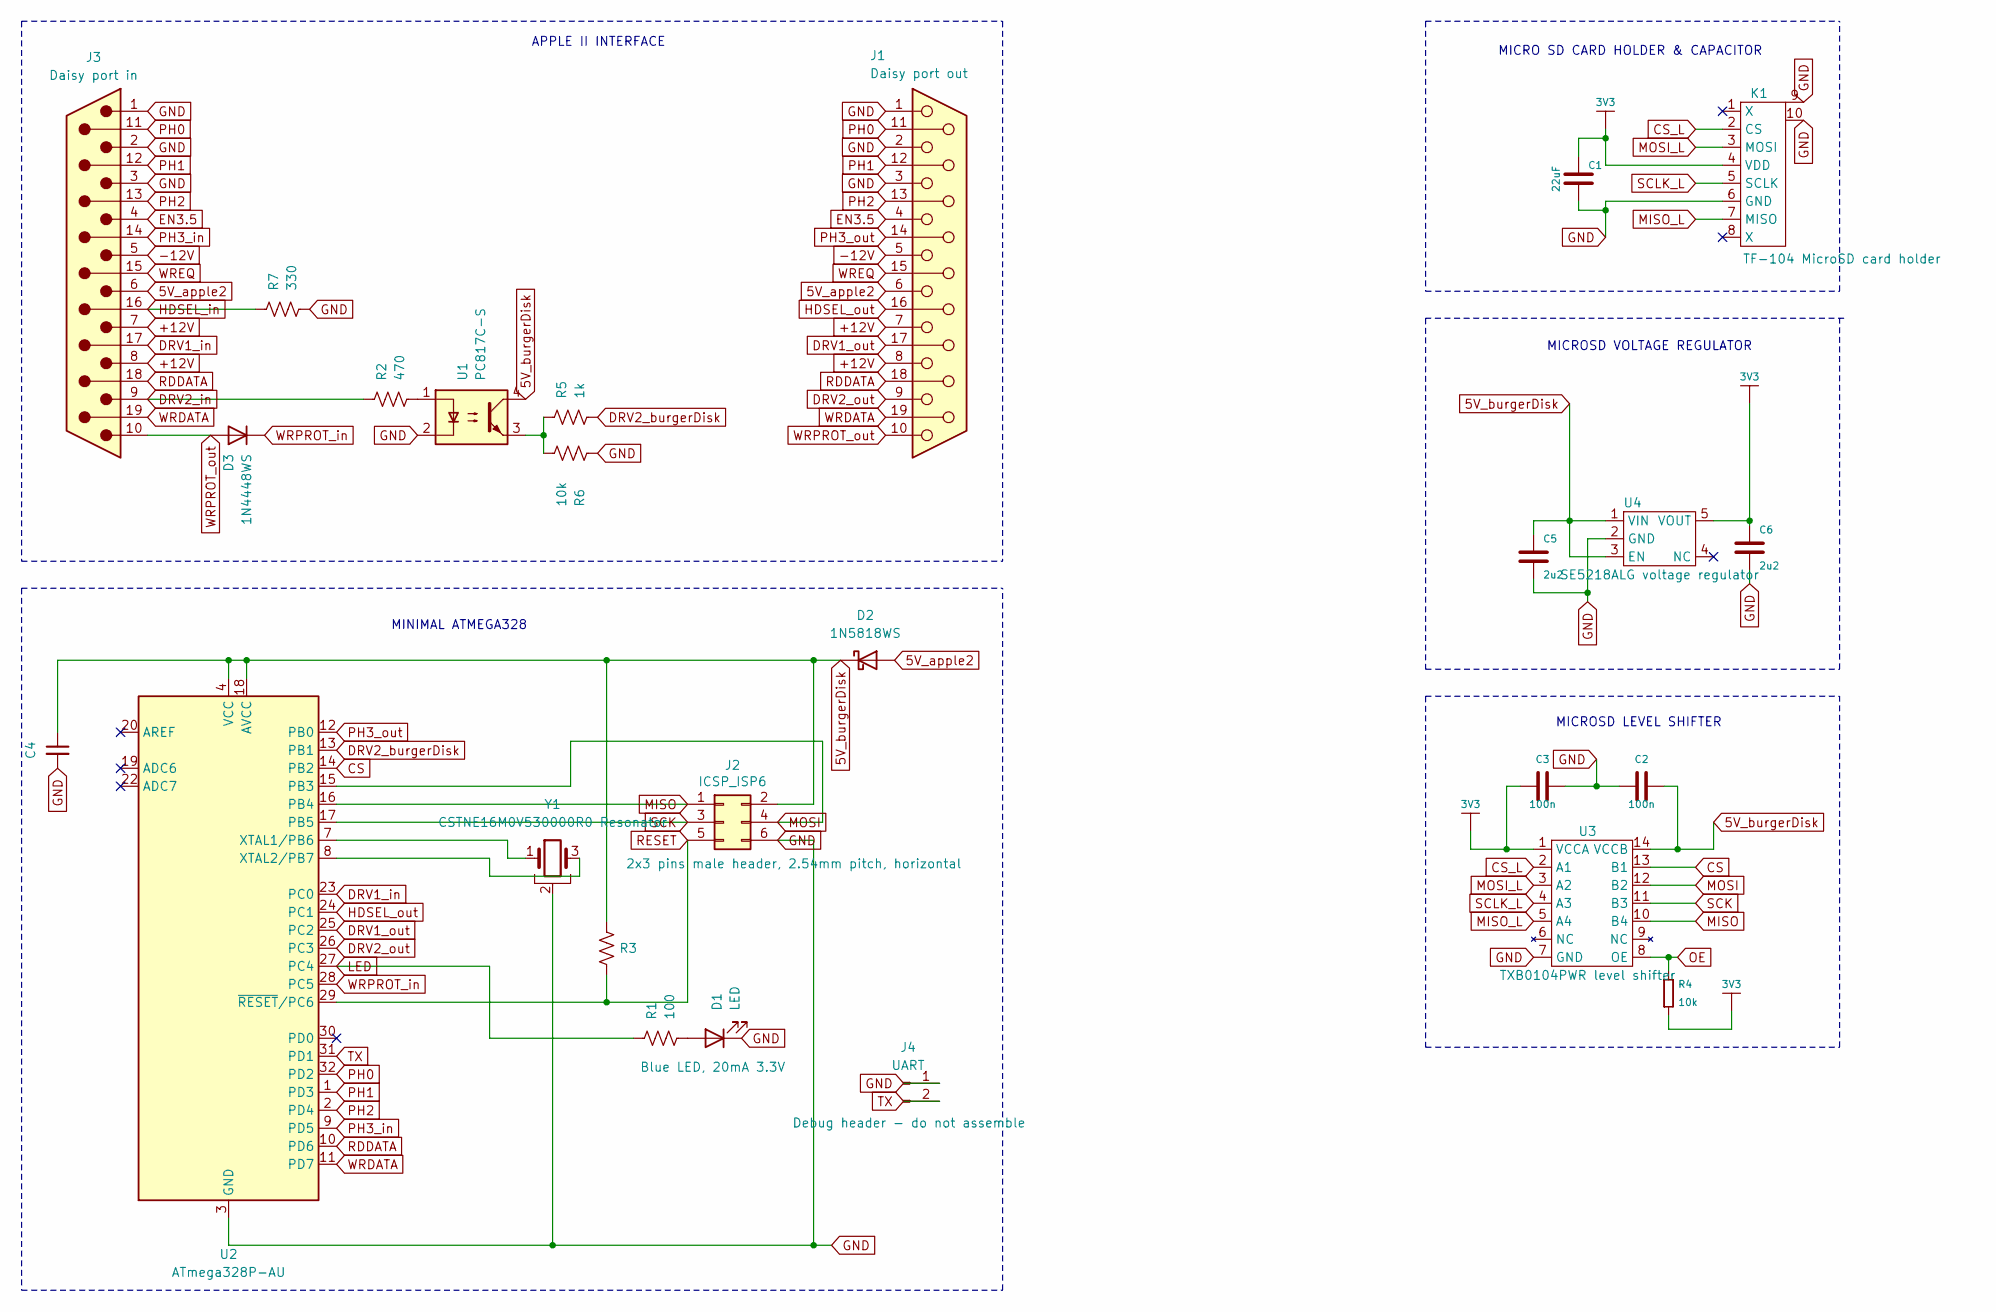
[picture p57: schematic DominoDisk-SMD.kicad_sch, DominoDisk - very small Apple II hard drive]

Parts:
C1: 22uF; C_0805_2012Metric; LCSC C45783
C2, C3, C4: 100n; C_0603_1608Metric; LCSC C14663
C5, C6: 2u2; C_0603_1608Metric; LCSC C1607
D1: LED; LED_0603_1608Metric; LCSC C965807
D2: 1N5818WS; D_SOD-123F; LCSC C51315007
D3: 1N4448WS; D_SOD-323_HandSoldering; LCSC C167101
J1: Daisy port out; DSUB-19_Female_EdgeMount_Pitch2.77mm
J2: ICSP_ISP6; PinHeader_2x03_P2.54mm_Horizontal; LCSC C492431
J3: Daisy port in; DSUB-19_Male_EdgeMount_Pitch2.77mm
J4: UART; PinHeader_1x02_P2.54mm_Vertical; LCSC-disabled C6273326 (disabled to avoid having to r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
K1: TF-104 MicroSD card holder; TF-SMD_TF-104; LCSC C266612
R1: 100; R_0603_1608Metric; LCSC C22775
R2: 470; R_1206_3216Metric; LCSC C137212
R3, R4, R6: 10k; R_0603_1608Metric; LCSC C25804
R5: 1k; R_0603_1608Metric; LCSC C21190
R7: 330; R_0603_1608Metric; LCSC C23138
U1: PC817C-S; SOP-4_3.8x4.1mm_P2.54mm; LCSC C3008369
U2: ATmega328P-AU; TQFP-32_7x7mm_P0.8mm; LCSC C14877
U3: TXB0104PWR level shifter; TSSOP-14-1EP_4.4x5mm_P0.65mm; LCSC C60708
U4: SE5218ALG voltage regulator; SOT-23-5; LCSC C118233
Y1: CSTNE16M0V530000R0 Resonator; Resonator_SMD_Murata_CSTxExxV-3Pin_3.0x1.1mm; LCSC C341521

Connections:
3V3: C1.2, C3.1, C6.2, K1.4 (VDD), R4.1, U3.1 (VCCA), U4.5 (VOUT)
5V_apple2: D2.2 (A), J1.6, J3.6
5V_burgerDisk: C2.2, C4.1, C5.2, D2.1 (K), J2.2, R3.1, U1.4, U2.4 (VCC), U2.6 (VCC), U2.18 (AVCC), U3.14 (VCCB), U4.1 (VIN), U4.3 (EN)
+12V: J1.7, J1.8, J3.7, J3.8
-12V: J1.5, J3.5
CS: U2.14 (PB2), U3.13 (B1)
CS_L: K1.2 (CS), U3.2 (A1)
DRV1_in: J3.17, U2.23 (PC0)
DRV1_out: J1.17, U2.25 (PC2)
DRV2_burgerDisk: R5.1, U2.13 (PB1)
DRV2_in: J3.9, R2.1
DRV2_out: J1.9, U2.26 (PC3)
EN3.5: J1.4, J3.4
GND: C1.1, C2.1, C3.2, C4.2, C5.1, C6.1, D1.1 (K), J1.1, J1.2, J1.3, J2.6, J3.1, J3.2, J3.3, J4.1, K1.6 (GND), K1.9, K1.10, R6.1, R7.1, U1.2, U2.3 (GND), U2.5 (GND), U2.21 (GND), U3.7 (GND), U4.2 (GND), Y1.2
HDSEL_in: J3.16, R7.2
HDSEL_out: J1.16, U2.24 (PC1)
LED: R1.2, U2.27 (PC4)
MISO: J2.1, U2.16 (PB4), U3.10 (B4)
MISO_L: K1.7 (MISO), U3.5 (A4)
MOSI: J2.4, U2.15 (PB3), U3.12 (B2)
MOSI_L: K1.3 (MOSI), U3.3 (A2)
unnamed: D1.2 (A), R1.1
unnamed: R2.2, U1.1
unnamed: R5.2, R6.2, U1.3
unnamed: U2.7 (XTAL1/PB6), Y1.1
unnamed: U2.8 (XTAL2/PB7), Y1.3
OE: R4.2, U3.8 (OE)
PH0: J1.11, J3.11, U2.32 (PD2)
PH1: J1.12, J3.12, U2.1 (PD3)
PH2: J1.13, J3.13, U2.2 (PD4)
PH3_in: J3.14, U2.9 (PD5)
PH3_out: J1.14, U2.12 (PB0)
RDDATA: J1.18, J3.18, U2.10 (PD6)
RESET: J2.5, R3.2, U2.29 (~RESET/PC6)
SCK: J2.3, U2.17 (PB5), U3.11 (B3)
SCLK_L: K1.5 (SCLK), U3.4 (A3)
TX: J4.2, U2.31 (PD1)
WRDATA: J1.19, J3.19, U2.11 (PD7)
WREQ: J1.15, J3.15
WRPROT_in: D3.1 (K), U2.28 (PC5)
WRPROT_out: D3.2 (A), J1.10, J3.10

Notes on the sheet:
MICROSD LEVEL SHIFTER
MINIMAL ATMEGA328
MICROSD VOLTAGE REGULATOR
APPLE II INTERFACE
MICRO SD CARD HOLDER & CAPACITOR

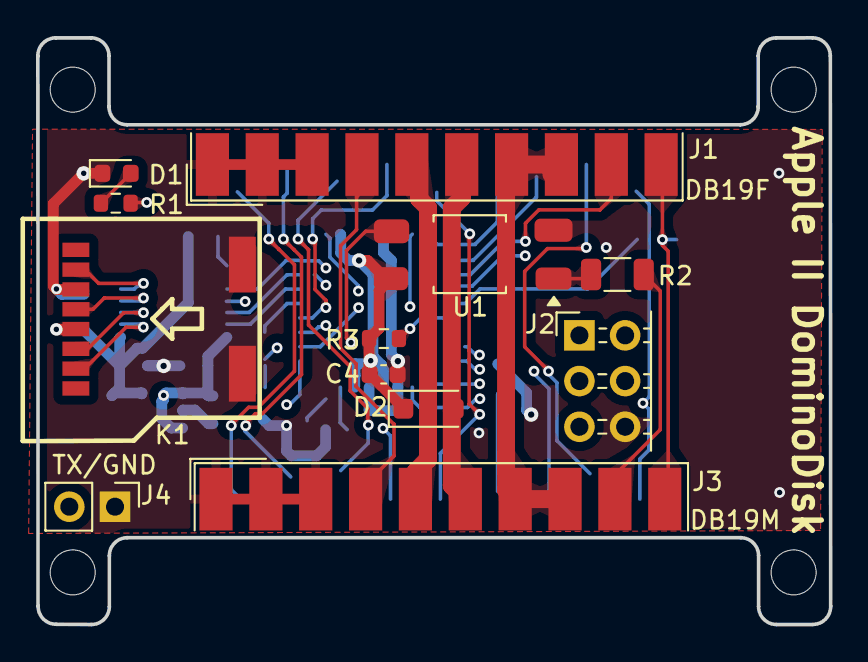
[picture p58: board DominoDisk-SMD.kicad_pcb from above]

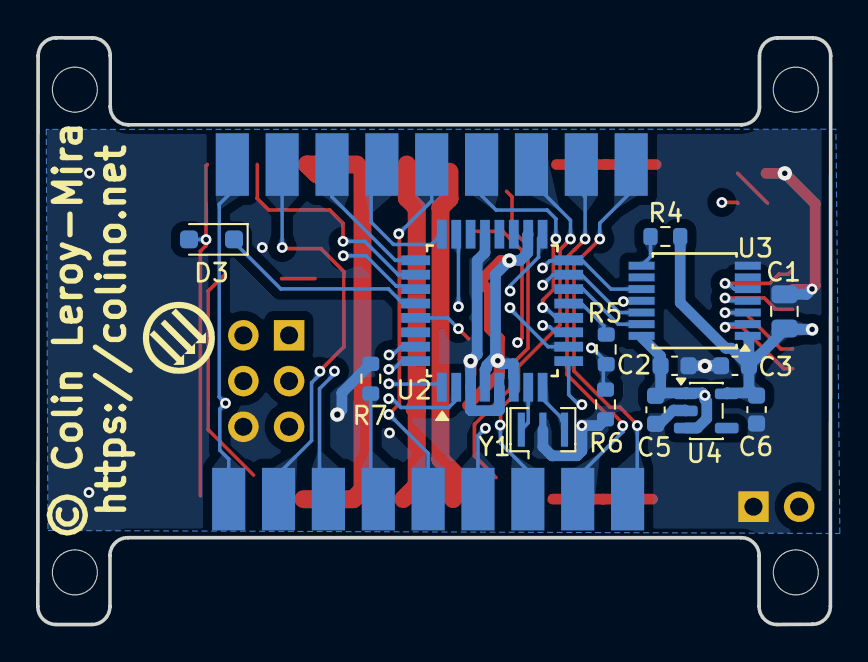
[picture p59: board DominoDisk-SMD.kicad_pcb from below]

Board: 4 copper layers, 44.0 x 32.6 mm, 26 parts (14 on the bottom side), 41 nets.

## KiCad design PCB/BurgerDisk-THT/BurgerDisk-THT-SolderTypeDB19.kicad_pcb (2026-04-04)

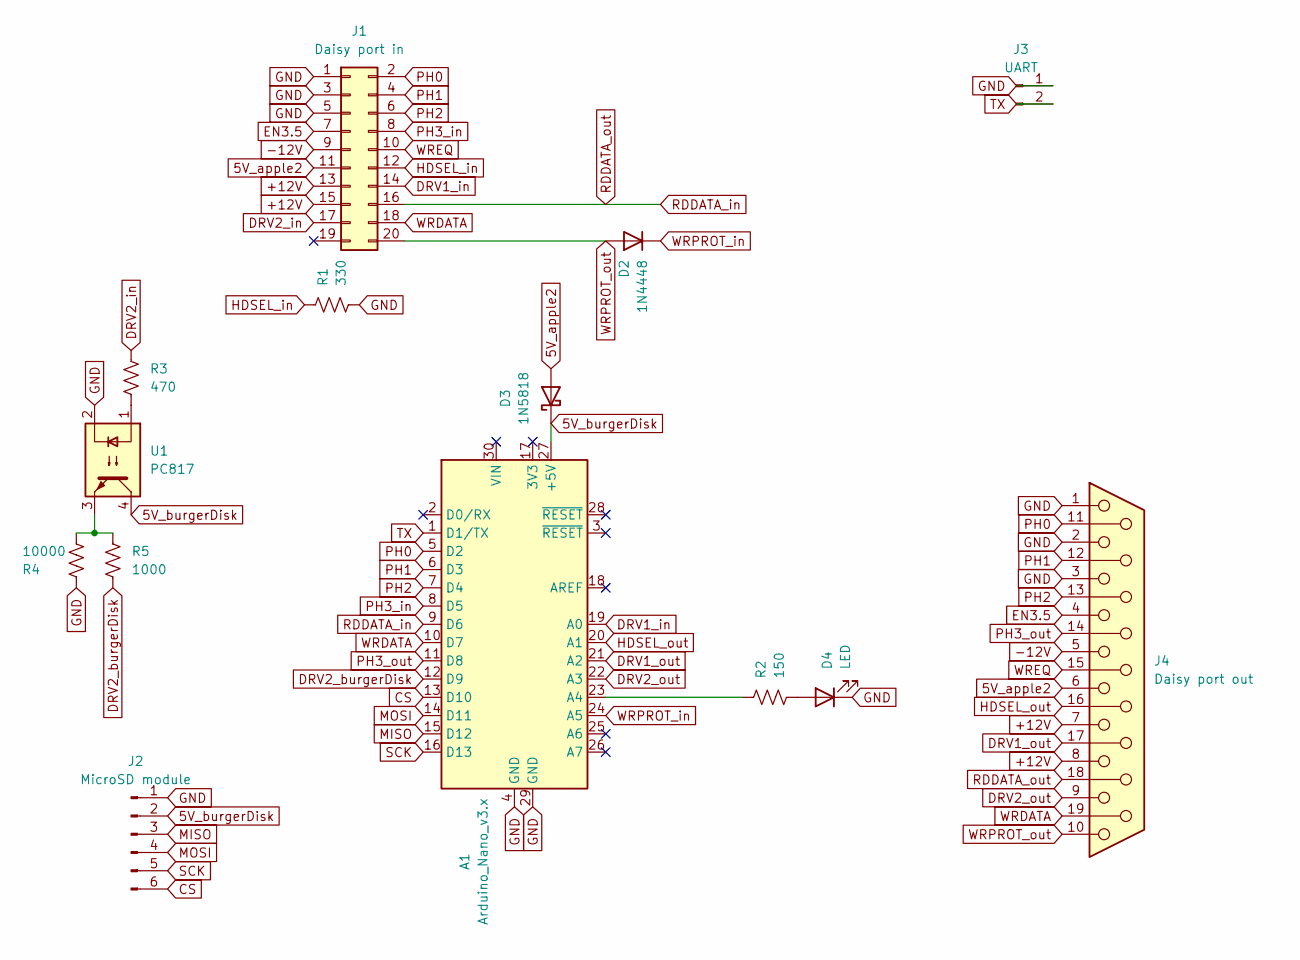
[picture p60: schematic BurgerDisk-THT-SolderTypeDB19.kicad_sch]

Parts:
A1: Arduino_Nano_v3.x; Arduino_Nano
D2: 1N4448; D_DO-35_SOD27_P7.62mm_Horizontal; LCSC C258170
D3: 1N5818; D_DO-41_SOD81_P7.62mm_Horizontal; LCSC C402217
D4: LED; PinHeader_1x02_P2.54mm_Vertical; LCSC C32713268
J1: Daisy port in; IDC-Header_2x10_P2.54mm_Vertical; LCSC C3405
J2: MicroSD module; PinHeader_1x06_P2.54mm_Vertical; LCSC C56816
J3: UART; PinHeader_1x02_P2.54mm_Vertical; LCSC C32713268
J4: Daisy port out; DSUB-19_Female_EdgeMount_Pitch2.77mm
R1: 330; R_Axial_DIN0207_L6.3mm_D2.5mm_P7.62mm_Horizontal; LCSC C58608
R2: 150; R_Axial_DIN0207_L6.3mm_D2.5mm_P7.62mm_Horizontal; LCSC C58668
R3: 470; R_Axial_DIN0309_L9.0mm_D3.2mm_P12.70mm_Horizontal; LCSC C129899
R4: 10000; R_Axial_DIN0207_L6.3mm_D2.5mm_P7.62mm_Horizontal; LCSC C57436
R5: 1000; R_Axial_DIN0207_L6.3mm_D2.5mm_P7.62mm_Horizontal; LCSC C57435
U1: PC817; DIP-4_W7.62mm; LCSC C5350

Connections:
5V_apple2: D3.2 (A), J1.11, J4.6
5V_burgerDisk: A1.27 (+5V), D3.1 (K), J2.2, U1.4
+12V: J1.13, J1.15, J4.7, J4.8
-12V: J1.9, J4.5
CS: A1.13 (D10), J2.6
DRV1_in: A1.19 (A0), J1.14
DRV1_out: A1.21 (A2), J4.17
DRV2_burgerDisk: A1.12 (D9), R5.1
DRV2_in: J1.17, R3.1
DRV2_out: A1.22 (A3), J4.9
EN3.5: J1.7, J4.4
GND: A1.4 (GND), A1.29 (GND), D4.1 (K), J1.1, J1.3, J1.5, J2.1, J3.1, J4.1, J4.2, J4.3, R1.1, R4.1, U1.2
HDSEL_in: J1.12, R1.2
HDSEL_out: A1.20 (A1), J4.16
MISO: A1.15 (D12), J2.3
MOSI: A1.14 (D11), J2.4
unnamed: A1.23 (A4), R2.2
unnamed: D4.2 (A), R2.1
unnamed: R3.2, U1.1
unnamed: R4.2, R5.2, U1.3
PH0: A1.5 (D2), J1.2, J4.11
PH1: A1.6 (D3), J1.4, J4.12
PH2: A1.7 (D4), J1.6, J4.13
PH3_in: A1.8 (D5), J1.8
PH3_out: A1.11 (D8), J4.14
RDDATA_in: A1.9 (D6), J1.16, J4.18
SCK: A1.16 (D13), J2.5
TX: A1.1 (D1/TX), J3.2
WRDATA: A1.10 (D7), J1.18, J4.19
WREQ: J1.10, J4.15
WRPROT_in: A1.24 (A5), D2.1 (K)
WRPROT_out: D2.2 (A), J1.20, J4.10

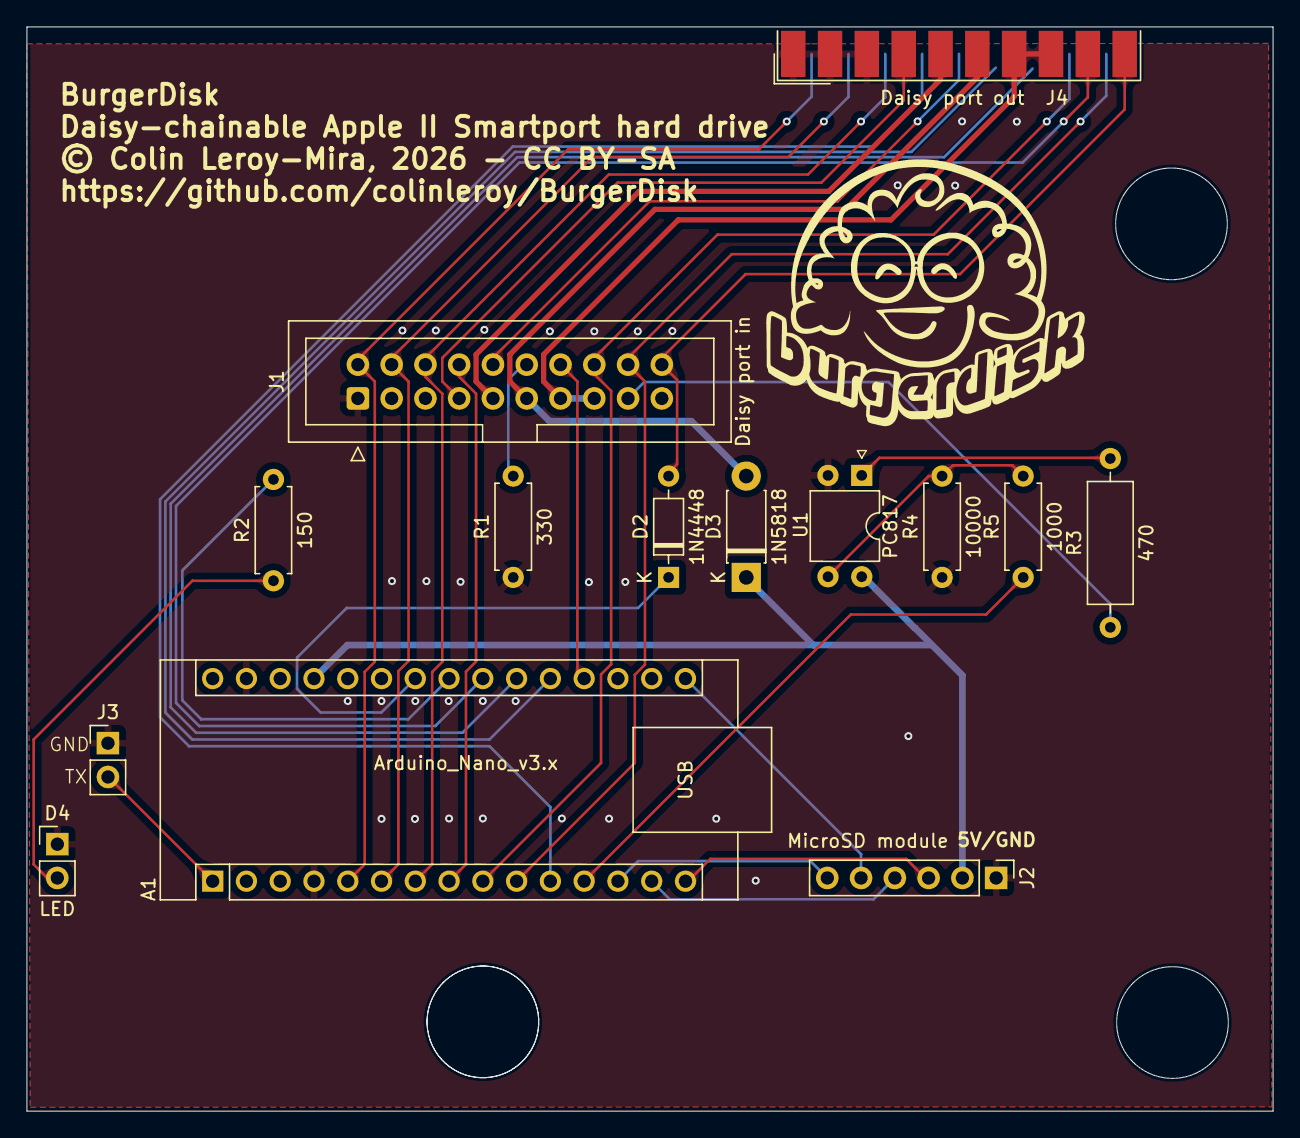
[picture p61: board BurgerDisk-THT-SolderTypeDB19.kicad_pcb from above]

Board: 2 copper layers, 93.7 x 81.5 mm, 14 parts (0 on the bottom side), 32 nets.

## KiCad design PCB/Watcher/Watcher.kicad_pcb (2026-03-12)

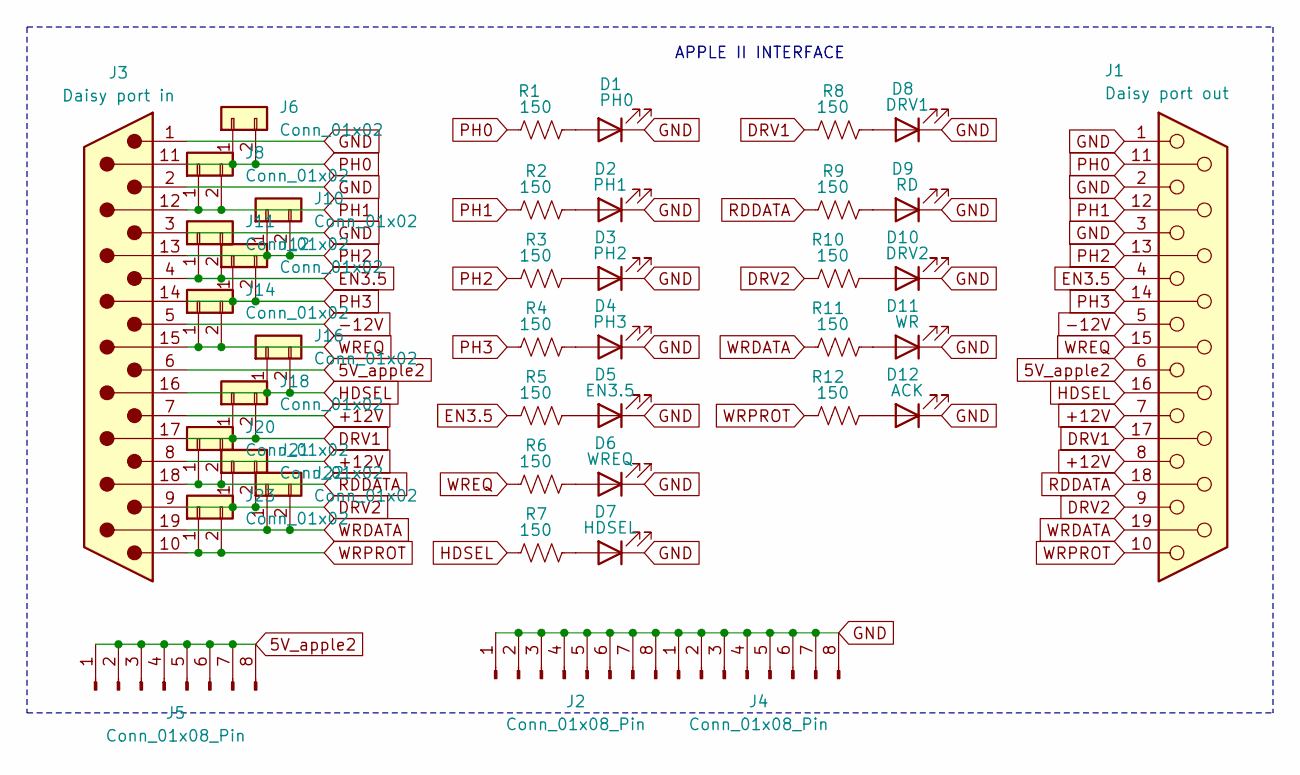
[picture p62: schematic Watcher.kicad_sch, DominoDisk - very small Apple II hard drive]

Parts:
D1: PH0; LED_0603_1608Metric; LCSC C2286
D2: PH1; LED_0603_1608Metric; LCSC C2286
D3: PH2; LED_0603_1608Metric; LCSC C2286
D4: PH3; LED_0603_1608Metric; LCSC C2286
D5: EN3.5; LED_0603_1608Metric; LCSC C2286
D6: WREQ; LED_0603_1608Metric; LCSC C2286
D7: HDSEL; LED_0603_1608Metric; LCSC C2286
D8: DRV1; LED_0603_1608Metric; LCSC C2286
D9: RD; LED_0603_1608Metric; LCSC C2286
D10: DRV2; LED_0603_1608Metric; LCSC C2286
D11: WR; LED_0603_1608Metric; LCSC C2286
D12: ACK; LED_0603_1608Metric; LCSC C2286
J1: Daisy port out; DSUB-19_Female_EdgeMount_Pitch2.77mm
J2, J4, J5: Conn_01x08_Pin; PinHeader_1x08_P1.00mm_Vertical
J3: Daisy port in; DSUB-19_Male_EdgeMount_Pitch2.77mm
J6, J8, J10, J11, J12, J14, J16, J18, J20, J21, J22, J23: Conn_01x02; PinHeader_1x02_P1.00mm_Vertical
R1, R2, R3, R4, R5, R6, R7, R8, R9, R10, R11, R12: 150; R_0603_1608Metric; LCSC C22808

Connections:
5V_apple2: J1.6, J3.6, J5.1, J5.2, J5.3, J5.4, J5.5, J5.6, J5.7, J5.8
+12V: J1.7, J1.8, J3.7, J3.8
-12V: J1.5, J3.5
DRV1: J1.17, J3.17, J18.1, J18.2, R8.1
DRV2: J1.9, J3.9, J21.1, J21.2, R10.1
EN3.5: J1.4, J3.4, J11.1, J11.2, R5.1
GND: D1.1 (K), D2.1 (K), D3.1 (K), D4.1 (K), D5.1 (K), D6.1 (K), D7.1 (K), D8.1 (K), D9.1 (K), D10.1 (K), D11.1 (K), D12.1 (K), J1.1, J1.2, J1.3, J2.1, J2.2, J2.3, J2.4, J2.5, J2.6, J2.7, J2.8, J3.1, J3.2, J3.3, J4.1, J4.2, J4.3, J4.4, J4.5, J4.6, J4.7, J4.8
HDSEL: J1.16, J3.16, J16.1, J16.2, R7.1
unnamed: D1.2 (A), R1.2
unnamed: D2.2 (A), R2.2
unnamed: D3.2 (A), R3.2
unnamed: D4.2 (A), R4.2
unnamed: D5.2 (A), R5.2
unnamed: D6.2 (A), R6.2
unnamed: D7.2 (A), R7.2
unnamed: D8.2 (A), R8.2
unnamed: D9.2 (A), R9.2
unnamed: D10.2 (A), R10.2
unnamed: D11.2 (A), R11.2
unnamed: D12.2 (A), R12.2
PH0: J1.11, J3.11, J6.1, J6.2, R1.1
PH1: J1.12, J3.12, J8.1, J8.2, R2.1
PH2: J1.13, J3.13, J10.1, J10.2, R3.1
PH3: J1.14, J3.14, J12.1, J12.2, R4.1
RDDATA: J1.18, J3.18, J20.1, J20.2, R9.1
WRDATA: J1.19, J3.19, J22.1, J22.2, R11.1
WREQ: J1.15, J3.15, J14.1, J14.2, R6.1
WRPROT: J1.10, J3.10, J23.1, J23.2, R12.1

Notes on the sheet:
APPLE II INTERFACE


Board: 2 copper layers, 44.0 x 32.6 mm, 41 parts (0 on the bottom side), 28 nets.

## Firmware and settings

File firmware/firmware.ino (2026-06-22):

//
//*****************************************************************************
// BurgerDisk firmware.
// This device provides the Smartport-capable Apple II with an SD-card-based
// hard-drive, like the SmartportSD, SP2SD or FloppyEmu projects do.
// Contrary to those, the BurgerDisk firmware handles a daisy-chain port
// and allows you to have more Smartport devices and/or dumb floppy drives
// connected behind it.
// The usual Apple II daisy-chaining rules apply:
// - first the 3.5" floppy disk drives
// - followed by Smartport devices
// - followed by dumb disk drives.
//
// The code of this firmware is based on:
// 
// - Apple //c Smartport Compact Flash adapter
//      Written by Robert Justice <rjustice(at)internode.on.net>
// - Ported to Arduino UNO with SD Card adapter
//      Written by Andrea Ottaviani <andrea.ottaviani.69(at)gmail.com>
// - FAT filesystem support
//      Written by Katherine Stark
// - Daisy chaining based on SmartportVHD's reverse engineering
//      Written by Cedric Peltier
//
// The firmware will open and present between one and four partitions.
// If a config.txt file exists on the SD card, it will use the first four
// lines as filenames for the partitions to open. An optional fifth line
// containing "debug=1" will turn debug messages on.
// If no config.txt file exists, the firmware will search for PARTx.po
// files, with x between 1 and 4.
//
// The firmware is compatible with SPIISD v1 and SPIISD v2 boards. It fixes
// two bugs in that firmware:
// - Too slow init preventing the partitions to be visible by ProDOS after
//   booting from internal floppy,
// - It fixes a non-recoverable freeze on A2S4100 Apple //c with the memory
//   expansion board.
// Of course, running this firmware on an SPIISD board will not allow for
// daisy chaining.
// The slow initialization problem has two parts, one of them is a fix in the
// code, the other one depends on the Arduino boot process and this one must
// be fixed by using an AVR programmer to upload the firmware.
//
// This firmware is licensed under the GPL v3.
//
//*****************************************************************************

#include "SdFat.h" // tested with SDFat version 2.3.0
#include <string.h>
#include <stdio.h>
#include <avr/pgmspace.h>
#include "packet_codecs.h"
#include "sp_pins.h"
#include "sp_low.h"
#include "sp_vals.h"
#include "log.h"
#if __has_include("version.h")
#include "version.h"
#else
#define GIT_VERSION "UNDEFINED VERSION"
#endif

#define SPI_CLOCK SD_SCK_MHZ(50)
#define SD_CONFIG SdSpiConfig(PIN_CHIP_SELECT, DEDICATED_SPI, SPI_CLOCK)

#define MAX_PARTITIONS 4

#define _MAX_FILENAME_LEN 80
#define _2MG_HEADER_LEN   0x0F

unsigned char open_partitions = 0;
unsigned char debug = 0;
unsigned char force_next_smartport = 1;

unsigned char *packet_buffer;
unsigned char identifier = '0';

// We need to remember several things about a device, not just its ID
struct device {
  File sdf;
  unsigned char device_id;              //to hold assigned device id's for the partitions
  unsigned char dos33;                  //0: ProDOS; 1: DOS3.3
  unsigned long blocks;                 //how many 512-byte blocks this image has
  unsigned char header_offset;          //Some image files have headers, skip this many bytes to avoid them
};

struct device devices[MAX_PARTITIONS];
SdFat sdcard;

static void log_io_err(const __FlashStringHelper *op, unsigned char partition, int block_num) {
  Serial.print(op);
  Serial.print(F(" error on partition "));
  Serial.print(partition);
  Serial.print(F(", block "));
  Serial.print(block_num);
  Serial.print(F(" - errCode 0x"));
  Serial.println(sdcard.sdErrorCode(), HEX);

  deinit_storage();
  init_storage();
}

static void deinit_storage(void) {
  // cleanup previous possibly opened files
  while (open_partitions > 0) {
    open_partitions--;
    if (devices[open_partitions].sdf.isOpen()) {
      devices[open_partitions].sdf.close();
      devices[open_partitions].blocks = 0;
    }
  }
  sdcard.end();
}

/* First bytes of sector 1 */
static unsigned char prodos_sector_1[] = { 0x3F, 0x09, 0x26, 'P', 'R', 'O', 'D', 'O', 'S'};
static char dos_sector_map[16] = {0x0, 0xE, 0xD, 0xC, 0xB, 0xA, 0x9, 0x8,
                                  0x7, 0x6, 0x5, 0x4, 0x3, 0x2, 0x1, 0xF};
#define BLOCKS_PER_TRACK 8
#define BLOCK_SIZE       512
#define SECTOR_SIZE      256

static void init_storage(void) {
  if (open_partitions > 0) {
    return;
  }

  if (!sdcard.begin(SD_CONFIG)) {
    sdcard.initErrorPrint();
    return;
  }

  // check for open error
  LOG(F("Opening partitions"));
  open_partitions = 0;

  // Not enough RAM for SDFat to open a file if the standard packet_buffer
  // is allocated.
  free(packet_buffer);
  packet_buffer = (unsigned char *)malloc(_MAX_FILENAME_LEN + _2MG_HEADER_LEN + 1);

  SdFile configFile("config.txt", O_READ);
  if (configFile.isOpen()) {
    unsigned char n;
    while (open_partitions < MAX_PARTITIONS) {
      n = configFile.fgets((char*)packet_buffer, _MAX_FILENAME_LEN - 1);
      if(n > 1) {
        if (packet_buffer[n - 1] == '\n') {
          packet_buffer[n-1] = 0;
        }
        LOG((char*)packet_buffer);

        open_image(devices[open_partitions],(char*)packet_buffer);
        if(!devices[open_partitions].sdf.isOpen()) {
          LOG(F(" open error"));
        } else {
          if ((packet_buffer[n-4]       == '2')
           &&((packet_buffer[n-3]&0xdf) == 'M')
           &&((packet_buffer[n-2]&0xdf) == 'G')) {
            /* https://gswv.apple2.org.za/a2zine/Docs/DiskImage_2MG_Info.txt */
            /* Read header after name, check ProDOS sector order */
            if (devices[open_partitions].sdf.read(packet_buffer+_MAX_FILENAME_LEN, 0x0F) < _2MG_HEADER_LEN
             || packet_buffer[_MAX_FILENAME_LEN+0x0C] != 0x01) {
              LOG(F(" not in ProDOS format"));
              devices[open_partitions].sdf.close();
              continue;
            }
            /* Apply offset */
            devices[open_partitions].header_offset=packet_buffer[_MAX_FILENAME_LEN+0x08];
          } else {
            devices[open_partitions].header_offset=0;
          }

          /* Check DOS3.3 order on .dsk files */
          if (((packet_buffer[n-4]&0xdf) == 'D')
           && ((packet_buffer[n-3]&0xdf) == 'S')
           && ((packet_buffer[n-2]&0xdf) == 'K')
           && devices[open_partitions].sdf.seekSet(0xE00+devices[open_partitions].header_offset)
           && devices[open_partitions].sdf.read(packet_buffer+_MAX_FILENAME_LEN, 0x0F) == 0x0F
           && !memcmp(packet_buffer+_MAX_FILENAME_LEN, prodos_sector_1, sizeof(prodos_sector_1))) {
             LOG(F(" DOS3.3 ordered"));
             devices[open_partitions].dos33 = 1;
          }
          open_partitions++;
        }
      } else {
        break;
      }
    }
    configFile.close();
  } else {
    LOG(F("No config.txt. Searching for images."));
    for (unsigned char i = 0; i < MAX_PARTITIONS; i++) {
      String prefix = F("PART");
      open_image(devices[i], prefix+(i+1)+".po");
      if (devices[i].sdf.isOpen()) {
        open_partitions++;
      }
    }
  }

  /* Now get parameters */
  SdFile optionsFile("options.txt", O_READ);
  if (optionsFile.isOpen()) {
    while (optionsFile.fgets((char*)packet_buffer, _MAX_FILENAME_LEN) > 0) {
      if (!strncmp((const char *)packet_buffer, "debug=", 6)) {
        debug = (packet_buffer[6] == '1');
      } else if (!strncmp((const char *)packet_buffer, "force_next_smartport=", 21)) {
        force_next_smartport = (packet_buffer[21] == '1');
      }
    }
    optionsFile.close();
  }

  // Realloc standard packet_buffer
  free(packet_buffer);
  packet_buffer = (unsigned char *)malloc(605);
  memset(packet_buffer, 0, 605);
  DEBUGN(F("Free memory now "), freeMemory(), DEC);
}

//Arduino boot setup - serial, pinmodes.
void setup (void) {
  // LED
  SET_LED_OUT;
  SET_LED_HIGH;

  // Serial init
  Serial.begin(230400);
  LOG(F("BurgerDisk version " GIT_VERSION));

  packet_buffer = (unsigned char *)malloc(605);

  /* Main pins on upstream port */
  SET_WR_HIGH; SET_WR_IN;     //WR: input pullup
  SET_DRV1_IN; SET_DRV1_HIGH; //DRV1 & 2: input
  SET_DRV2_IN; SET_DRV2_HIGH;

  SP_ACK_MUTE();
  SP_RD_MUTE();

  /* Daisy pins */
  SET_DAISY_PH3_OUT;          // PH3: output
  daisy_ph3_disable();

  SET_DAISY_DRV1_OUT;         // DRV1 & 2: output
  SET_DAISY_DRV2_OUT;
  daisy_diskII_mirror();

  SET_DAISY_HDSEL_IN;         // HDSEL: input pullup
  SET_DAISY_HDSEL_HIGH;

  LOG(F("Ready"));

  SET_LED_LOW;
}

// Helper to match a Smartport device_id to one of our images
#define NO_PARTITION 0xFF

static unsigned char get_device_partition(unsigned char device_id) {
  for  (unsigned char p = 0; p < MAX_PARTITIONS; p++) {
    if (devices[p].device_id == device_id) {
      return p;
    }
  }
  return NO_PARTITION;
}

// Helper to extract the block number from the Smartport packet
static unsigned long int smartport_get_block_num_from_buf(void) {
  unsigned long int block_num;

  block_num = ((unsigned long int)packet_buffer[PACKET_BLOCK_NUM_L])
            | ((unsigned long int)packet_buffer[PACKET_BLOCK_NUM_M] << 8)
            | ((unsigned long int)packet_buffer[PACKET_BLOCK_NUM_H] << 16);

  return block_num;
}

//Get Smartport state from phases pins
static inline SP_State smartport_get_state(void) {
  if (PHASES_BUS_RESET) {
    return SP_BUS_RESET;
  }
  if (PHASES_BUS_ENABLE) {
    return SP_BUS_ENABLED;
  }
  return SP_BUS_DISABLED;
}


static inline void daisy_ph3_mirror(void) {
  if (RD_PORT_PHASES & _BV(PIN_PH3)) {
    SET_DAISY_PH3_HIGH;
  } else {
    SET_DAISY_PH3_LOW;
  }
}

static inline void daisy_ph3_disable() {
  SET_DAISY_PH3_LOW;
}

static inline void daisy_diskII_mirror(void) {
  if (DRV1_IS_HIGH) {
    SET_DAISY_DRV1_HIGH;
  } else {
    SET_DAISY_DRV1_LOW;
  }

  if (DRV2_IS_HIGH) {
    SET_DAISY_DRV2_HIGH;
  } else {
    SET_DAISY_DRV2_LOW;
  }
}

static inline void daisy_diskII_disable(void) {
  SET_DAISY_DRV1_HIGH;
  SET_DAISY_DRV2_HIGH;
}

//SMARTPORT COMMAND HANDLERS ---------------------------------------------------

//Smartport RESET handler
static unsigned char number_partitions_initialised = 0;
static unsigned char device_init_done = 0;
static unsigned char never_got_reset = 1;
static void smartport_device_reset(void) {
  LOG(F("RESET"));

  //reset number of partitions init'd
  number_partitions_initialised = 0;
  device_init_done = 0;
  never_got_reset = 0;

  deinit_storage();
  daisy_diskII_disable();

  // Ready. Wait for reset to clear
  while(smartport_get_state() == SP_BUS_RESET);
}

//Smartport STATUS handler
static void smartport_answer_status(unsigned char partition) {
  SP_Status_Code status_code;

  if (open_partitions == 0)
    init_storage();

  status_code = (SP_Status_Code)(packet_buffer[PACKET_STATCODE_TYPE]);
  DEBUG_CMD('s', devices[partition].device_id, status_code);

  switch (status_code) {
    case SP_STATUS_DIB:
      encode_status_dib_reply_packet(devices[partition].device_id, devices[partition].blocks);
      break;
    case SP_STATUS_SIMPLE:
      encode_status_reply_packet(devices[partition].device_id, SP_SUCCESS, devices[partition].blocks);
      break;
    default:
      encode_status_reply_packet(devices[partition].device_id, SP_BADCTL, devices[partition].blocks);
      break;
  }
  SendPacket( (unsigned char*) packet_buffer);
}

//Smartport READ handler
static void smartport_read_block(unsigned char partition) {
  unsigned long int block_num;
  SP_Error status = SP_SUCCESS;
  unsigned char tries = 3;
  int r;

  block_num = smartport_get_block_num_from_buf();

read_again:
  if (open_partitions == 0)
    init_storage();

  DEBUG_CMD('r', devices[partition].device_id, block_num);

  if (!devices[partition].sdf.isOpen()) {
    status = SP_OFFLINE;
    goto reply;
  }

  if (!devices[partition].dos33) {
    /* Simple case, read block at once */
    if (!devices[partition].sdf.seekSet(block_num*512+devices[partition].header_offset)) {
      log_io_err(F("Seek"), partition, block_num);
      status = SP_BADBLOCK;
      goto reply;
    }

    //Read block from SD Card
    if ((r = devices[partition].sdf.read((unsigned char*) packet_buffer, 512)) != 512) {
      log_io_err(F("Read"), partition, block_num);
      if (tries--) {
        goto read_again;
      }
      status = SP_IOERROR;
    }
  } else {
    /* Complicated DOS3.3 case, read block in two sectors at two offsets */
    unsigned long int track_num, sector_a, sector_b;
    unsigned char block_in_track = block_num % BLOCKS_PER_TRACK;
    track_num = block_num / BLOCKS_PER_TRACK;
    track_num = track_num * BLOCKS_PER_TRACK * 512;
    sector_a = track_num + (dos_sector_map[block_in_track*2] * 256);
    sector_b = track_num + (dos_sector_map[(block_in_track*2)+1] * 256);

    if (!devices[partition].sdf.seekSet(sector_a+devices[partition].header_offset)) {
      log_io_err(F("Seek"), partition, block_num);
      status = SP_BADBLOCK;
      goto reply;
    }
    //Read sector a from SD Card
    if ((r = devices[partition].sdf.read((unsigned char*) packet_buffer, 256)) != 256) {
      log_io_err(F("Read"), partition, block_num);
      if (tries--) {
        goto read_again;
      }
      status = SP_IOERROR;
    }
    if (!devices[partition].sdf.seekSet(sector_b+devices[partition].header_offset)) {
      log_io_err(F("Seek"), partition, block_num);
      status = SP_BADBLOCK;
      goto reply;
    }
    //Read sector b from SD Card
    if ((r = devices[partition].sdf.read((unsigned char*) packet_buffer+256, 256)) != 256) {
      log_io_err(F("Read"), partition, block_num);
      if (tries--) {
        goto read_again;
      }
      status = SP_IOERROR;
    }
  }

reply:
  if (status != SP_SUCCESS)
    DEBUG_CMD('E', devices[partition].device_id, status);

  encode_data_packet(devices[partition].device_id, status);
  SendPacket( (unsigned char*) packet_buffer);
}

//Smartport WRITE handler
static void smartport_write_block(unsigned char partition) {
  unsigned long int block_num;
  SP_Error status;
  unsigned int numodd, numgrps, bytes_to_write;
  unsigned char tries = 5, r;

  block_num = smartport_get_block_num_from_buf();

try_again:
  if ((r = ReceivePacket((unsigned char*) packet_buffer)) != 0) {
    if (tries--) {
      Serial.print('.');
      goto try_again;
    }
  }
  AckPacket();

  numodd  = packet_buffer[PACKET_NUM_ODD]&0x7F;
  numgrps = packet_buffer[PACKET_NUM_GRP]&0x7F;
  bytes_to_write = numodd + numgrps*7;

  DumpPacket(packet_buffer, 2);

  DEBUG_CMD('w', devices[partition].device_id, block_num);

  if (r != 0 || bytes_to_write != 512) {
    status = SP_BADCMD;
    goto reply;
  }

  if (open_partitions == 0)
    init_storage();

  if (!devices[partition].sdf.isOpen()) {
    status = SP_OFFLINE;
    goto reply;
  }

  status = SP_SUCCESS;

  if (!devices[partition].dos33) {
    if (!devices[partition].sdf.seekSet(block_num*512+devices[partition].header_offset)) {
      log_io_err(F("Seek"), partition, block_num);
      status = SP_BADBLOCK;
      goto reply;
    }
    // Write block to SD Card
    if (devices[partition].sdf.write((unsigned char*) packet_buffer+PACKET_DATA_START, 512) != 512) {
      log_io_err(F("Write"), partition, block_num);
      // Sadly no retry here, ase init_storage() destroys packet_buffer and we
      // don't have enough RAM to do otherwise.
      status = SP_IOERROR;
    }
  } else {
    unsigned long int track_num, sector_a, sector_b;
    unsigned char block_in_track = block_num % BLOCKS_PER_TRACK;
    track_num = block_num / BLOCKS_PER_TRACK;
    track_num = track_num * BLOCKS_PER_TRACK * 512;
    sector_a = track_num + (dos_sector_map[block_in_track*2] * 256);
    sector_b = track_num + (dos_sector_map[(block_in_track*2)+1] * 256);

    if (!devices[partition].sdf.seekSet(sector_a+devices[partition].header_offset)) {
      log_io_err(F("Seek"), partition, block_num);
      status = SP_BADBLOCK;
      goto reply;
    }
    if (devices[partition].sdf.write((unsigned char*) packet_buffer+PACKET_DATA_START, 256) != 256) {
      log_io_err(F("Write"), partition, block_num);
      status = SP_IOERROR;
    }

    if (!devices[partition].sdf.seekSet(sector_b+devices[partition].header_offset)) {
      log_io_err(F("Seek"), partition, block_num);
      status = SP_BADBLOCK;
      goto reply;
    }
    if (devices[partition].sdf.write((unsigned char*) packet_buffer+PACKET_DATA_START+256, 256) != 256) {
      log_io_err(F("Write"), partition, block_num);
      status = SP_IOERROR;
    }
  }

  if (!devices[partition].sdf.sync()) {
    log_io_err(F("Sync"), partition, block_num);
    status = SP_IOERROR;
  }

reply:
  if (status != SP_SUCCESS)
    DEBUG_CMD('E', devices[partition].device_id, status);

  //now return status code to host
  encode_write_status_packet(devices[partition].device_id, status);
  SendPacket( (unsigned char*) packet_buffer);
}
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
void loop() {
  unsigned char dev_id, r;
  SP_Command command;
  SP_State smartport_state;
  unsigned char partition;

  SP_ACK_MUTE();
  SP_RD_MUTE();

  while (1) {
    if (device_init_done || never_got_reset) {
      daisy_ph3_mirror();
    }

    if (open_partitions == 0) {
      led_err();
    }

    smartport_state = smartport_get_state();
    partition = -1;

    switch (smartport_state) {
    case SP_BUS_RESET:
      daisy_ph3_disable();
      smartport_device_reset();
      device_init_done = 0;
      break;

    case SP_BUS_ENABLED:
      daisy_diskII_disable();

      // We can come back here after handling a previous smartport packet, as
      // it happens the bus stays enabled a bit longer. ReceivePacket() will
      // return with a non-zero code if the smartport bus gets disabled without
      // receiving anything.
      if ((r = ReceivePacket((unsigned char*) packet_buffer)) != 0) {
        goto out;
      }

      dev_id = packet_buffer[PACKET_DEST];
      command = (SP_Command) packet_buffer[PACKET_COMMAND];

      if (command == SP_INIT && !device_init_done) {
        AckPacket();
      } else if ((partition = get_device_partition(dev_id)) != NO_PARTITION) {
        AckPacket();
      } else {
        DumpPacket(packet_buffer, 1);
        IgnorePacket();
        // Smartbus is now disabled, packet has been ignored. Loop back.
        goto out;
      }

      SET_LED_HIGH;
      DumpPacket(packet_buffer, 0);

      switch (command) {
      case SP_INIT:
        //we may not have a dev_id/partition match yet
        smartport_init(dev_id);
        break;

      case SP_STATUS:
        smartport_answer_status(partition);
        break;

      case SP_READ:
        smartport_read_block(partition);
        break;

      case SP_WRITE:
        smartport_write_block(partition);
        break;

      case SP_FORMAT:
        smartport_format(partition);
        break;

      default:
        LOGN(F("E:"), packet_buffer[PACKET_COMMAND], HEX);
        encode_init_reply_packet(devices[partition].device_id, SP_BADCMD);
        SendPacket( (unsigned char*) packet_buffer);
        break;
      }
out:
      SET_LED_LOW;
      break;

    case SP_BUS_DISABLED:
      daisy_diskII_mirror();
      break;
    }

    // Clear packet for next time
    memset(packet_buffer, 0, 30);
    // I would have preferred to re-mute lines from the assembly funcs,
    // but this triggers a timing problem with SoftSP cards. Cf commit
    // 7b9ef299d98dfbd96c21fb1e522ccb702f9b7ec0
    SP_ACK_MUTE();
    SP_RD_MUTE();
  }
}
#pragma GCC optimize("-Os")

//*****************************************************************************
// Function: led_err
// Parameters: none
// Returns: nothing
//
// Description: Flashes status led to show error status
//*****************************************************************************

void led_err(void)
{
  static unsigned long last_switch = 0;
  static char last_state = 0;

  // Account for counter rollover
  if (millis() < last_switch) {
    last_switch = 0;
  }

  // Toggle led every 250ms
  if (millis() - last_switch > 250) {
    last_switch = millis();
    last_state = !last_state;
    if (last_state) {
      SET_LED_HIGH;
    } else {
      SET_LED_LOW;
    }
  }
}

extern void *__brkval;
extern char __bss_end;
int freeMemory() {
  int free_memory;
  if ((int)__brkval == 0) {
    // if no heap use from end of bss section
    free_memory = ((int)&free_memory) - ((int)&__bss_end);
  } else {
    // use from top of stack to heap
    free_memory = ((int)&free_memory) - ((int)__brkval);
  }
  return free_memory;
}

bool open_image(struct device &d, String filename ) {
  d.sdf = sdcard.open(filename, O_RDWR);
  if (!d.sdf.isOpen()) {
    return false;
  }
  if (!d.sdf.isFile()) {
    return false;
  }

  if (d.sdf.size() == 0) {
    return false;
  }

  d.blocks = d.sdf.size() >> 9;
  return true;
}

//Debug helper - dump a packet's start
static void DumpPacket(unsigned char *buffer, unsigned char type) {
  if (!debug) {
    return;
  }
  if (type == 1) {
    Serial.print(F("Ignored "));
  }
  if (type == 2) {
    Serial.print(F("Data: "));
  } else {
    Serial.print(F("Packet from: "));
    Serial.print(buffer[PACKET_SOURCE], HEX);
    Serial.print(F(", To: "));
    Serial.print(buffer[PACKET_DEST], HEX);
    Serial.print(F(", Command: "));
    Serial.print(buffer[PACKET_COMMAND], HEX);
    Serial.println();
  }
  for (unsigned char i = 0; i < 35; i++) {
    Serial.print(' ');
    Serial.print(buffer[i], HEX);
  }
  Serial.println();
}

static void FullPacketDump(unsigned char decoded) {
  int i;
  if (decoded == 0) {
    Serial.print("Encoded packet:");
  } else {
    Serial.print("Decoded packet:");
  }
  for (i = 0; i < 606; i++) {
    if (i % 8 == 0) {
      Serial.println();
      Serial.print(i, DEC);
    }
    Serial.print(' ');
    Serial.print(packet_buffer[i], HEX);
  }
  Serial.println();
}

static void dump(char *str, unsigned char i) {
  Serial.print(str);
  Serial.print("= 0x");
  Serial.println(i, HEX);
}

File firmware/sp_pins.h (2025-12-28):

#ifndef __SP_PINS
#define __SP_PINS

#include <avr/io.h>

// Phases, D2 to D5 (portD)
#define PIN_PH0         2       // D2
#define PIN_PH1         3       // D3
#define PIN_PH2         4       // D4
#define PIN_PH3         5       // D5

#define PINS_PHASES     (_BV(PIN_PH0)|_BV(PIN_PH1)|_BV(PIN_PH2)|_BV(PIN_PH3))
#define WR_PORT_PHASES  PORTD
#define RD_PORT_PHASES  PIND

#define PHASES_BUS_RESET   ((RD_PORT_PHASES & PINS_PHASES) == (_BV(PIN_PH0)|_BV(PIN_PH2)))
#define PHASES_BUS_ENABLE  ((RD_PORT_PHASES & (_BV(PIN_PH1)|_BV(PIN_PH3))) == (_BV(PIN_PH1)|_BV(PIN_PH3)))
#define PHASES_BUS_DISABLE (!(PHASES_BUS_ENABLE))

// RDDATA on D6
#define WR_PORT_RD      PORTD
#define RD_PORT_RD      PIND
#define DIR_PORT_RD     DDRD
#define PIN_RD          6       // D6
#define SET_RD_HIGH     (WR_PORT_RD |= _BV(PIN_RD))
#define SET_RD_LOW      (WR_PORT_RD &= ~_BV(PIN_RD))
#define SET_RD_OUT      (DIR_PORT_RD |= _BV(PIN_RD))
#define SET_RD_IN       (DIR_PORT_RD &= ~(_BV(PIN_RD)))

// WRDATA on D7
#define WR_PORT_WR      PORTD
#define RD_PORT_WR      PIND
#define DIR_PORT_WR     DDRD
#define PIN_WR          7       // D7
#define SET_WR_HIGH     (WR_PORT_WR |= _BV(PIN_WR))
#define SET_WR_LOW      (WR_PORT_WR &= ~_BV(PIN_WR))
#define SET_WR_OUT      (DIR_PORT_WR |= _BV(PIN_WR))
#define SET_WR_IN       (DIR_PORT_WR &= ~(_BV(PIN_WR)))

// REQ aka PH0, on D2
#define WR_PORT_REQ     PORTD
#define RD_PORT_REQ     PIND
#define DIR_PORT_REQ    DDRD
#define PIN_REQ         PIN_PH0    // Define the PIN number to REQ (PH0)    - PORTD bit2: D2
#define REQ_IS_HIGH     (RD_PORT_REQ & _BV(PIN_REQ))
#define REQ_IS_LOW      (!(REQ_IS_HIGH))
#define WAIT_REQ_LOW    while (REQ_IS_HIGH)

//WRPROT on A5
#define WR_PORT_ACK     PORTC   // Define the PORT to ACK                - A0 to A5
#define RD_PORT_ACK     PINC
#define DIR_PORT_ACK    DDRC
#define PIN_WRPROT      5       // A5 (portC)
#define PIN_ACK         PIN_WRPROT // Define the PIN number to ACK (WRPROT) - PORTC bit5: A5
#define SET_ACK_HIGH    (WR_PORT_ACK |= _BV(PIN_ACK))
#define SET_ACK_LOW     (WR_PORT_ACK &= ~_BV(PIN_ACK))
#define SET_ACK_OUT     (DIR_PORT_ACK |= _BV(PIN_ACK))
#define SET_ACK_IN      (DIR_PORT_ACK &= ~(_BV(PIN_ACK)))

#define ACK_IS_HIGH     (RD_PORT_ACK & _BV(PIN_ACK))
#define ACK_IS_LOW      (!(ACK_IS_HIGH))

//DRV1 on A0
#define WR_PORT_DRV1    PORTC
#define RD_PORT_DRV1    PINC
#define DIR_PORT_DRV1   DDRC
#define PIN_DRV1        0       // A0 (portC bit 0)
#define SET_DRV1_IN     (DIR_PORT_DRV1 &= ~(_BV(PIN_DRV1)))
#define SET_DRV1_HIGH   (WR_PORT_DRV1 |= _BV(PIN_DRV1))
#define DRV1_IS_HIGH    (RD_PORT_DRV1 & _BV(PIN_DRV1))
#define DRV1_IS_LOW     (!(DRV1_IS_HIGH))

//DRV2 on D9
#define WR_PORT_DRV2    PORTB
#define RD_PORT_DRV2    PINB
#define DIR_PORT_DRV2   DDRB
#define PIN_DRV2        1       // D9 (portB bit 1)
#define SET_DRV2_IN     (DIR_PORT_DRV2 &= ~(_BV(PIN_DRV2)))
#define SET_DRV2_HIGH   (WR_PORT_DRV2 |= _BV(PIN_DRV2))
#define DRV2_IS_HIGH    (RD_PORT_DRV2 & _BV(PIN_DRV2))
#define DRV2_IS_LOW     (!(DRV2_IS_HIGH))

//----------------------------------------------
// Daisy pins
//----------------------------------------------

#define WR_PORT_DAISY_PH3      PORTB
#define RD_PORT_DAISY_PH3      PINB
#define DIR_PORT_DAISY_PH3     DDRB
#define PIN_DAISY_PH3          0       // D8, portB bit 0
#define SET_DAISY_PH3_HIGH     (WR_PORT_DAISY_PH3 |= _BV(PIN_DAISY_PH3))
#define SET_DAISY_PH3_LOW      (WR_PORT_DAISY_PH3 &= ~_BV(PIN_DAISY_PH3))
#define SET_DAISY_PH3_OUT      (DIR_PORT_DAISY_PH3 |= _BV(PIN_DAISY_PH3))

#define WR_PORT_DAISY_DRV1     PORTC
#define RD_PORT_DAISY_DRV1     PINC
#define DIR_PORT_DAISY_DRV1    DDRC
#define PIN_DAISY_DRV1         2       // A2
#define SET_DAISY_DRV1_HIGH    (WR_PORT_DAISY_DRV1 |= _BV(PIN_DAISY_DRV1))
#define SET_DAISY_DRV1_LOW     (WR_PORT_DAISY_DRV1 &= ~_BV(PIN_DAISY_DRV1))
#define SET_DAISY_DRV1_OUT     (DIR_PORT_DAISY_DRV1 |= _BV(PIN_DAISY_DRV1))

#define WR_PORT_DAISY_DRV2     PORTC
#define RD_PORT_DAISY_DRV2     PINC
#define DIR_PORT_DAISY_DRV2    DDRC
#define PIN_DAISY_DRV2         3       // A3
#define SET_DAISY_DRV2_HIGH    (WR_PORT_DAISY_DRV2 |= _BV(PIN_DAISY_DRV2))
#define SET_DAISY_DRV2_LOW     (WR_PORT_DAISY_DRV2 &= ~_BV(PIN_DAISY_DRV2))
#define SET_DAISY_DRV2_OUT     (DIR_PORT_DAISY_DRV2 |= _BV(PIN_DAISY_DRV2))


#define WR_PORT_DAISY_HDSEL    PORTC
#define RD_PORT_DAISY_HDSEL    PINC
#define DIR_PORT_DAISY_HDSEL   DDRC
#define PIN_DAISY_HDSEL        1       // A1
#define SET_DAISY_HDSEL_IN     (DIR_PORT_DAISY_HDSEL &= ~_BV(PIN_DAISY_HDSEL))
#define SET_DAISY_HDSEL_HIGH   (WR_PORT_DAISY_HDSEL |= _BV(PIN_DAISY_HDSEL))
#define DAISY_HDSEL_IS_HIGH    (RD_PORT_DAISY_HDSEL & _BV(PIN_DAISY_HDSEL))
#define DAISY_HDSEL_IS_LOW     (!(DAISY_HDSEL_IS_HIGH))
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

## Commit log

2025-11-18 Fix build issues, comment Eject button for now
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2025-12-21 Fix daisy-chaining behind an Unidisk 3.5
2025-12-21 Update README, add PCB proto
    [OpenSDII-small-chainable.fzz, SP2SD_NANO_DIY_BOM.csv]
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2025-12-26 fix pads width
    [OpenSDII-small-chainable.fzz]
2025-12-27 Fix DRV2 IN pin
    [sp_pins.h]
2025-12-27 PCB fixes
    Mainly VCC to MicroSD module should come from the Nano.
    Remove useless diodes. Move LED out of the Nano's way.
    [OpenSDII-small-chainable.fzz]
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2025-12-28 Rename project, add proper licensing
    [SP2SD_NANO_DIY_BOM.csv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]
2025-12-28 orthogonality fix
    [BurgerDisk.fzz]
2025-12-28 GSOS fix: drop delay
    [firmware.ino]
2026-01-01 PCB rev4, W926160AS1P6
    zigzagging track fix
    [BurgerDisk.fzz]
2026-01-01 Add a small DB19/IDC20 adapter
    [db19-idc20-adapter.fzz]
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2026-01-01 Fix SoftSP
    Rework state machine to be closer to 44bbc2e, so that the firmware
    works with SoftSP cards.
    Reason of the bug unclear, possibly a timing issue.
    Workaround annoying, it's uglier than what existed.
    [firmware.ino]
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2026-01-01 Rework to add jumper on HDSEL
    Cleanup a bit
    [BurgerDisk.fzz]
2026-01-01 v5 PCB, to be tested
    (W926160ASV8)
    [BurgerDisk.fzz]
2026-01-02 PCB: Put diodes back
    They are useful in reality (on A2S4100 only...)
    PCBWay ref #W926160ASV10
    [BurgerDisk.fzz]
2026-01-02 Decode and checksum data packets faster
    It is still much too slow to allow for not acking a wrong
    packet and let the computer re-transmit it.
    [firmware.ino]
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2026-01-02 In case of SD-card-related error, don't crash the whole system
    Just do absolutely nothing on the Smartbus if no SD card is
    inserted or zero partitions are opened. Flash LED for the
    user.
    [firmware.ino]
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2026-01-04 Bigger pads on DB19 connectors
    Also more precise pitch (2.77mm)
    [BurgerDisk.fzz, db19-idc20-adapter.fzz]
2026-01-04 Fix BOM quantities
2026-01-04 Move labels where they'll be visible after assembly
    [BurgerDisk.fzz]
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2026-01-05 Make PCB as wide as plug allows
    [db19-idc20-adapter.fzz]
2026-01-09 Have the SD module stick out of the enclosure
    (W926160ASV13)
    [BurgerDisk.fzz]
2026-01-09 Link to fritzing LED bug
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2026-01-09 Update STL with last print
    [BurgerDisk.stl]
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2026-01-14 Zener voltage limiter for DRV2, test
    [BurgerDisk.fzz]
2026-01-15 Fix packet ignoring when another SP device is behind
2026-01-15 Optocoupler on DRV2 - wip
    [BurgerDisk.fzz]
2026-01-17 Update documentation and resistor value
    [BurgerDisk.fzz]
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2026-01-18 Fix circuit so we don't have to INPUT_PULLUP DRV2 pin
    [BurgerDisk.fzz]
2026-01-20 Move SD slot to front
    [BurgerDisk Bottom.stl, BurgerDisk LED diffuser.stl, BurgerDisk Top.stl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]
2026-01-20 Fix stl links
2026-01-21 Version with and without logo bump
    [BurgerDisk Bottom with logo.stl, BurgerDisk Bottom without logo.stl, BurgerDisk Bottom.stl]
2026-01-22 Redo the PCB in Kicad
    [BurgerDisk.fzz, BurgerDisk_THT_AngledDB19.kicad_pcb, BurgerDisk_THT_AngledDB19.kicad_sch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]
2026-01-23 Modify holder a bit
    [BurgerDisk_THT_AngledDB19.kicad_pcb, BurgerDisk_THT_SolderTypeDB19.kicad_pcb]
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2026-01-23 Add tooling to create JLCPCB BOM/CPL files
    [BurgerDisk_THT_AngledDB19.kicad_pcb, BurgerDisk_THT_AngledDB19.kicad_sch]
2026-01-23 Small esthetic fixes
    [BurgerDisk_THT_AngledDB19.kicad_pcb, BurgerDisk_THT_AngledDB19.kicad_sch, BurgerDisk_THT_SolderTypeDB19.kicad_pcb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]
2026-01-23 fix 470Ω resistor silkscreen
    [BurgerDisk_THT_AngledDB19.kicad_pcb, BurgerDisk_THT_SolderTypeDB19.kicad_pcb]
2026-01-24 Add 8-pin header for full size SD module
    [BurgerDisk_THT_AngledDB19.kicad_pcb, BurgerDisk_THT_AngledDB19.kicad_sch, BurgerDisk_THT_SolderTypeDB19.kicad_pcb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]
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2026-01-24 Add a very hacky way to add Nano headers
    [BurgerDisk_THT_AngledDB19.kicad_sch, BurgerDisk_THT_SolderTypeDB19.kicad_sch]
2026-01-25 Revert full-size SD connector and module.
    They don't have level shifter.
    [BurgerDisk_THT_AngledDB19.kicad_pcb, BurgerDisk_THT_AngledDB19.kicad_sch, BurgerDisk_THT_SolderTypeDB19.kicad_pcb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]
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2026-01-28 Cleanup old PCB now that new PCB is tested
    [BurgerDisk.fzz, BurgerDisk_THT_AngledDB19.kicad_pcb, BurgerDisk_THT_AngledDB19.kicad_sch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]
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2026-01-28 Wider tracks for power
    [BurgerDisk_THT_AngledDB19.kicad_pcb, BurgerDisk_THT_AngledDB19.kicad_sch, BurgerDisk_THT_SolderTypeDB19.kicad_pcb]
2026-01-30 Reverse 3 resistors for correct silkscreen orientation
    [BurgerDisk_THT_AngledDB19.kicad_pcb, BurgerDisk_THT_AngledDB19.kicad_sch, BurgerDisk_THT_SolderTypeDB19.kicad_pcb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]
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2026-01-30 Better routing to allow grounding to ground plane
    [BurgerDisk_THT_AngledDB19.kicad_pcb, BurgerDisk_THT_SolderTypeDB19.kicad_pcb]
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2026-02-05 Be invisible until first bus reset
    Fixes booting from S6 on SoftSP
    [firmware.ino]
2026-02-05 Remove RDDATA diode, causing harm on SoftSP
    [BurgerDisk_THT_AngledDB19.kicad_pcb, BurgerDisk_THT_AngledDB19.kicad_sch, BurgerDisk_THT_SolderTypeDB19.kicad_pcb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]
2026-02-06 Fix SoftSPv6 (extra byte before start of packet)
    Thanks to Robert Justice
    [firmware.ino]
2026-02-06 Fix angled DB19 footprint to match the one we can buy
    [BurgerDisk_THT_AngledDB19.kicad_pcb, BurgerDisk_THT_AngledDB19.kicad_sch]
2026-02-08 Add untested Small and SMD version
    [Small-SMD.kicad_pcb, Small-SMD.kicad_sch]
2026-02-10 Switch to cheaper IDC box header
    [BurgerDisk_THT_AngledDB19.kicad_sch, BurgerDisk_THT_SolderTypeDB19.kicad_sch, Small-SMD.kicad_pcb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]
2026-02-10 Fix U1 footprint
    [Small-SMD.kicad_pcb]
2026-02-10 Fix D2
    [Small-SMD.kicad_sch]
2026-02-10 WIP - untested - remove the Arduino
    [Small-atmega-SMD.kicad_pcb, Small-atmega-SMD.kicad_sch]
2026-02-10 Add GND to level shifter :-/
    [Small-SMD.kicad_pcb, Small-SMD.kicad_sch, Small-atmega-SMD.kicad_pcb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]
2026-02-11 WIP untested very small PCB
    [Small-SMD.kicad_pcb, Small-SMD.kicad_sch, Small-atmega-SMD.kicad_pcb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]
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2026-02-12 Renames, move to resonator on Domino
    [BurgerDisk-THT-AngledDB19.kicad_pcb, BurgerDisk-THT-AngledDB19.kicad_sch, BurgerDisk-THT-SolderTypeDB19.kicad_pcb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]
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2026-02-14 update enclose for easier DB19 fitting
    [BurgerDisk bottom.stl, BurgerDisk top.stl, DB19-to-IDC20 adapter.stl]
2026-02-14 Cleanup PCBs, fatter power traces
    [BurgerDisk-THT-SolderTypeDB19.kicad_pcb, DominoDisk-SMD-Angled.kicad_pcb, DominoDisk-SMD-Angled.kicad_sch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]
2026-02-14 Move connector away from MCU
    [Small-atmega-SMD.kicad_pcb, Small-atmega-SMD.kicad_sch]
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2026-02-15 Rework for cleanliness
    [Small-SMD.kicad_pcb, Small-SMD.kicad_sch, Small-atmega-SMD.kicad_pcb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]
2026-02-15 Let the OCD win
    [BurgerDisk-THT-SolderTypeDB19.kicad_pcb, Small-atmega-SMD.kicad_pcb]
2026-02-16 Fix part number on Small version
    [DominoDisk-SMD.kicad_pcb, Small-atmega-SMD.kicad_sch]
2026-02-16 Fix LCSC parts
    [Small-atmega-SMD.kicad_pcb, Small-atmega-SMD.kicad_sch]
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2026-02-17 Add libraries and update Domino/Angled
    [DominoDisk-SMD-Angled.kicad_pcb, DominoDisk-SMD-Angled.kicad_sch, DominoDisk-SMD.kicad_pcb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]
2026-02-17 Rework R3 so everything's in line
    for easier soldering
    [BurgerDisk-THT-AngledDB19.kicad_pcb, BurgerDisk-THT-SolderTypeDB19.kicad_pcb]
2026-02-19 Add logo (thanks to Javier Rivera!!)
    Add my own micro/SD modules
    [BurgerDisk-THT-AngledDB19.kicad_pcb, BurgerDisk-THT-AngledDB19.kicad_sch, BurgerDisk-THT-SolderTypeDB19.kicad_pcb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]
2026-02-21 Fix LED and R6
    [DominoDisk-SMD.kicad_pcb, DominoDisk-SMD.kicad_sch]
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2026-02-24 Gain 7mm on Dominodisk (4 layers)
    [DominoDisk-SMD.kicad_pcb, DominoDisk-SMD.kicad_sch]
2026-02-25 Fix microSD caps
    [DominoDisk-SMD.kicad_pcb, DominoDisk-SMD.kicad_sch, MicroSD-module.kicad_pcb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]
2026-02-27 Small caps fixes
    [BurgerDisk-THT-SolderTypeDB19.kicad_pcb, DominoDisk-SMD.kicad_pcb, DominoDisk-SMD.kicad_sch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]
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2026-02-28 Remove Fixed Fixme. Thanks Ralph Irving
    [firmware.ino]
2026-03-01 Add SD module header, for hackers
    [Small-atmega-SMD.kicad_pcb, Small-atmega-SMD.kicad_sch]
2026-03-01 Add indicator on PC817 pin1
    [BurgerDisk-THT-AngledDB19.kicad_pcb, BurgerDisk-THT-AngledDB19.kicad_sch, BurgerDisk-THT-SolderTypeDB19.kicad_pcb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]
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2026-03-02 Fix holes placement, off by just a little bit
    [MicroSD-module.kicad_pcb]
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2026-03-03 Fix SD module pins
    [SD-module.kicad_pcb, SD-module.kicad_sch]
2026-03-04 Add solder pads for hacking
    [Small-atmega-SMD.kicad_pcb, Small-atmega-SMD.kicad_sch]
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2026-03-05 Move logo out of PCB
    until I'm sure Rebecca's estate is OK with it
    [BurgerDisk-THT-AngledDB19.kicad_pcb, BurgerDisk-THT-SolderTypeDB19.kicad_pcb, DominoDisk-SMD.kicad_pcb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]
2026-03-06 Cleanup for better ground
    [DominoDisk-SMD.kicad_pcb]
2026-03-07 Rework for more cleanliness
    [DominoDisk-SMD.kicad_pcb]
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2026-03-09 Silkscreen/via avoidance
    [DominoDisk-SMD.kicad_pcb, Small-atmega-SMD.kicad_pcb]
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2026-03-21 Fix details on DD/angled
    [DominoDisk-SMD-Angled.kicad_pcb, DominoDisk-SMD.kicad_pcb, Small-atmega-SMD.kicad_pcb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]
2026-03-21 Rework for DB19F on the back
    [DominoDisk-SMD-Angled.kicad_pcb]
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2026-03-24 Fix 2-pin headers sections
    Thanks to Terin Stock
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2026-04-12 Correct errcode on offline devices
    [firmware.ino]
2026-04-12 WIP extended Smartport
    Getting issues with extended write blocks
    [firmware.ino]
2026-04-14 Make read try again in case of SD swap
    Sync writes, too.
    [firmware.ino]
2026-04-15 More details on SD errors
    Increase read retries to 3
    [firmware.ino]
2026-04-17 Make extended mode work better, generalize
    Still issues on WriteBlock
    [firmware.ino]
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2026-04-28 Retry on data packet errors
    Now that we're fast enough to know if a packet is wrong,
    let us retry!
    [firmware.ino]
2026-04-28 tighten a bit
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

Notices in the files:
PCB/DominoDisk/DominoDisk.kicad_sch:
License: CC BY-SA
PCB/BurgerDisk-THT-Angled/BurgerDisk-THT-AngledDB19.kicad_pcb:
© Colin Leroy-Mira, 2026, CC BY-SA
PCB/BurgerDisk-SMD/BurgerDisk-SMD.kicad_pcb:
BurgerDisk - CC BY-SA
